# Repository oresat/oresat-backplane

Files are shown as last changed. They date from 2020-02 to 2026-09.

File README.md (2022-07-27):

# OreSat Backplane

## Background

The [OreSat](http://oresat.org) CubeSat bus uses a card cage / backplane system based on a 1 Mbps Controller Area Network (CAN) bus and a 2 cell Lithium ion battery power bus (6.0 - 8.4 V). There are ~ 8 cards per CubeSat "U", and the board is meant to be general purpose enough to allow for some card swapping. The RF lines, however, are microstrips on the backplane PCB so the backplane must be rev'd for changes in the RF cards. There are three sets of connectors:

1. 40 pin "Main" connector, which has !shutdown, CAN1, power, CAN2, OreSat power Domain (OPD) lines, and then 5 shared spare pins for custom card interconnects.
2. SMPM RF conncectors, which allows up to 3 RF connector per card and allows for 50 ohm microstrips to be run up and down the the board.
3. 20 pin "Auxiliary" connectors, used on the all but the "end" cards (top and bottom cards), which are for future inter-card communication. Good for Ethernet, for example.

The backplane now comes in two flavors: a 1U backplane, and a 2U backplane.

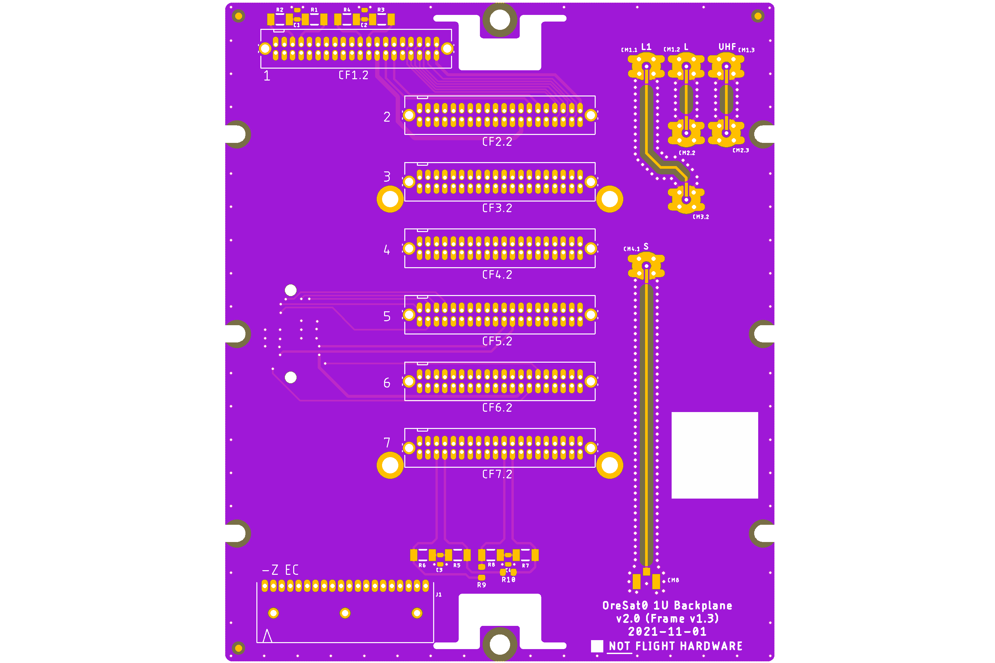
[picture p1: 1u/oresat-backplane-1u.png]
OreSat 1U Backplane Picture

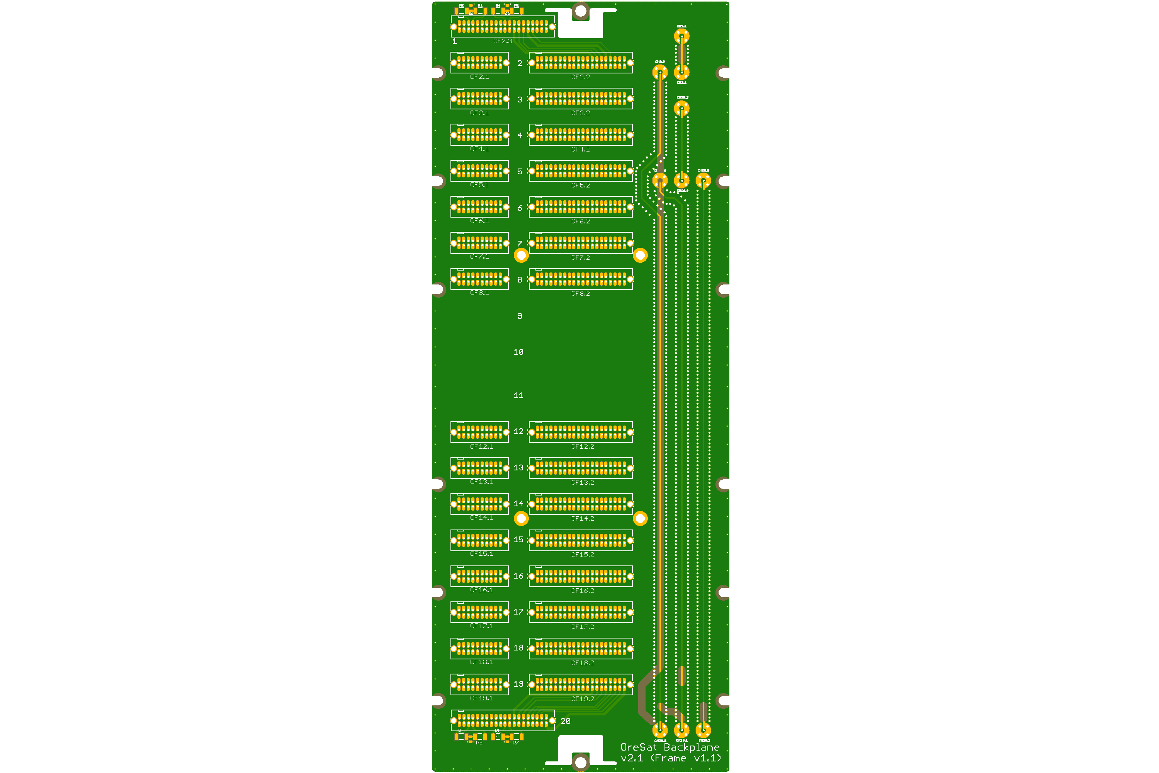
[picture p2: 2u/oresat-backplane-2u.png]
OreSat 2U Backplane Picture


## Mechanical Specifications

All mechanical specifications for this board are from the SolidWorks model which is in the 'oresat-structure' repo, specifically see the 'Backplane' folder. Some notes on the mechanical design:

- Ring of bare copper on the back is for thermal contact. Assumes annodized Aluminum, so no electrical contact on this ring.
- Backplane is grounded to the Aluminum frame on the internal four fasteners; this requires preparing the Aluminum for an electrical connection.
- Square cutouts on the top and bottom are for the solar connectors to reach the end cards. Note that on the 1U backplane, the bottom cutout is not used.
- Weird cutouts above and below square solar connector cutouts are for shoulder bolts (3 mm Shoulder Diameter, 2 mm Shoulder Length, M2 x 0.4 mm Thread, McMaster Carr #[90263A111](https://www.mcmaster.com/90263a111)) that precisely locates the PCB while allowing some flexing due to differences in thermal expansion between the Aluminum frame and the PCB.
- All other fasteners are M2 x 0.4 x 4 mm.

## Electrical Specifications

The board is designed for a [4 layer stackup](https://docs.oshpark.com/services/four-layer/) from [OSH Park](https://oshpark.com/) which has better RF performance than regular 2 layer board runs.

The connectors that we use on this puppy are the:

- **1.27 mm through-hole vertical socket connectors:**
    - 40 pin main connector
       - Samtec SFM-120-01-S-D-LC
       - 3D CAD: https://www.samtec.com/partnumber/sfm-120-01-s-d-lc
       - Drawing: http://suddendocs.samtec.com/prints/sfm-1xx-xx-xxx-d-xxx-mkt.pdf
       - Brochure: http://suddendocs.samtec.com/catalog_english/sfm.pdf
       - SFM footprint: http://suddendocs.samtec.com/prints/sfm-thd.pdf
    - 20 pin auxiliary connector
       - Samtec SFM-110-01-S-D-LC
       - 3D CAD: https://www.samtec.com/partnumber/sfm-110-01-s-d-lc
       - Drawing: http://suddendocs.samtec.com/prints/sfm-1xx-xx-xxx-d-xxx-mkt.pdf
       - Brochure: http://suddendocs.samtec.com/catalog_english/sfm.pdf
       - SFM footprint: http://suddendocs.samtec.com/prints/sfm-thd.pdf

- **RF (70 cm, L band, S band)**
   - Molex 073300-011X
   - SMPM Connector Plug, Male Pin 50 Ohm Surface Mount, Through Hole Solder, $13.84/ea @ 10
   - Molex (w/CAD): https://www.molex.com/molex/products/datasheet.jsp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
   - We've done a detailed characteraziation of OSH Park's 4 layer process, and found that 0.38 mm is the correct width for a 50 ohm microstrip.

- **CAN termination**
   - We'll use split termination, using two 60 ohm resistors with a center tapped capacitor for reduced EMI.
   - Resistors
      - 60.4 +/- 1% ohms. Might consider higher if the number of notes (~ 20) adds too much parallel resistance)
      - Usually there's only 2V (differential) across the 120 ohm termination resistors = 16 mA = 33 mW of power dissipation.
      - In the event of a bus short, there's 8.4 V across 120 ohms is 70 mA = 590 mW of power dissipation. That's ~ 300 mW across each of the 60 ohm resistors. Yikes.
      - ISO 11898-2 also requires 220 mW for the termination resistors, for whatever that's worth.
      - There exist 0.5 W 1206 resistors (?!) so although that's for an air rating, we'll still choose it, since larger than 1206 resistors are a tight fit
   - Capacitor
      - ISO 11898-2 doesn't seem to say anything about the capacitance, and the internets tend to say weird things. Unclear on this value.
      - TI's [Controller Area Network Physical Layer Requirements](http://www.ti.com/lit/an/slla270/slla270.pdf) suggests 4.7 nF to make the f_3dB = 1.1 MHz.
      - Seems awfully close to our 1 Mbps bus, so let's bump that down to 1 nF which is f_3db = 5.3 MHz.

- **Debug connector**
   - Harwin M55-6001642R (same family as the solar and end cap connectors)
   - Located on the back side of the backplane, it's a 16 pin 1.27 mm connector that gives external access to CAN busses, VBUS, and the UART lines. It sits in the 1U solar module "cutout".
   - For the external connector board, see the `backplane-debug` folder in the `oresat-flatsat` repo.

## Versions

- 1U
   - v1.0 - First fabbed 1U, but never assembled. For old frames (v1.1 frames), no -Z end cap connector, no debug connector.
   - v1.1 - Added -Z end cap connector. Fabbed roughly 2020-09-01, two assembled.
   - v1.2 - Added 1.27 mm debug connector, which tended to short. Fabbed 2020-12-08. Originally delivered on OreSat0.0 but never flown.
   - v2.0 -new backplane "v2" signal pinout (less power, more signals, UART lines, CAN bus bridging) and new non-shorting debug connector. Made new debug port board and breakout. Also corrected RF ports, including L1 band microstrip and S band strip to -Z end cap. Fabbed 2021-11-01 and installed on OreSat0.1 handed off to Spaceflight, ready for launch!
- 2U
   - v1.0 - First backplane. 2 layer board, RF connector array, aux and main connectors. Fabbed 2018/10/02.
   - v1.1 - End Cards now use 40 pin connector, solar connectors now actually fit. Fabbed 2019/02/25.
   - V2.0 - Switched to 4 layer board, removed RF connector array, used actual microstrips tuned to the 4 layer OSH Park process. Fabbed 2019/07/01.
   - v2.1 - Updated to latest backplane DXF, reducing all sides by 0.15 mm. Fixed solar connector cutout areas that were lopsided. Added CAN termination resistors. Moved RF connectors to latest (2020/02/15) locations. NOT YET FABBED.
   - vHASP - Made for the NASA HASP mission, fabbed, but never used.
   - V2.2 - Updated to FrameV2 and Oresat0.5 card locations

## LICENSE

Copyright the Portland State Aerospace Society, 2022.

This source describes Open Hardware that is licensed under CERN-OHL-S v2, or any later version.

You may redistribute and modify this source and make products using it under the terms of the CERN-OHL-S v2 (https://ohwr.org/cern_ohl_s_v2.txt).

This source is distributed WITHOUT ANY EXPRESS OR IMPLIED WARRANTY, INCLUDING OF MERCHANTABILITY, SATISFACTORY QUALITY AND FITNESS FOR A PARTICULAR PURPOSE. Please see the CERN-OHL-S v2 for applicable conditions.

Source location: https://github.com/oresat/

As per CERN-OHL-S v2 section 4, should You produce hardware based on this source, You must where practicable maintain the Source Location visible on the external case of the Gizmo or other products you make using this source.

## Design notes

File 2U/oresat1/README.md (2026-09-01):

---
title: "**OreSat1 2U Backplane Fabrication and Assembly Information**"
subtitle: |
  **Fabrication and Assembly Information**\
  For build TIME-STAMP
fontsize: 10pt
geometry:
  - margin=0.5in
toc: true
toc-depth: 2
colorlinks: true
urlcolor: blue
---

\newpage

# About this Board

## Board Description

The OreSat1 2U Backplane is the backplane for a 2U CubeSat based on the open source [OreSat CubeSat system](https://www.oresat.org/). The backplane has:

- 40 pin main connnectors for Oresat-based cards
- Bus voltage (2S Lithium Ion batteries with a Vnom of 7.2V)
- Two CAN busses for inter-card communication
- RF lines using SMPM RF connectors and microstrips
- A debug connector to carry critical lines to the outside of the CubeSat
- Two cutouts for solar module connections

## Documentation Links

- OreSat Backplane hardware Git repository: <https://github.com/oresat/oresat-backplane>
- **TODO:** Backplane Design Notes + Design Review Notes

## Documentation Files

| Filename | Notes |
| --- | --- |
| README.pdf | This README file |
| PROJECT-NAME-outline.dxf | Board outline (with holes) in DXF format |
| PROJECT-NAME-pcba.step | 3D model of PCBA (with components) |
| PROJECT-NAME-render-bot.jpg | Render of the top of the 3D model |
| PROJECT-NAME-render-bot.jpg | Render of the bottom of the 3D model |
| PROJECT-NAME-schematic.pdf | PDF of board schematics |

## Contact Information

- Website: <https://www.oresat.org/>
- Email: <oresat@pdx.edu>
- Instagram: @pdxaerospace

## Board Renders

Render of the top of the 3D model
Render of the bottom of the 3D model

\newpage

# Printed Circuit Board (PCB) Fabrication Information

## Board Info

- 4 layer board
- Bounding box is 82.5 x 213.5 mm
- Board thickness is 1.59 mm (0.063 inch)
- **Important:** See Materials and Stack Up sections below

## Board Requirements

- Design Rules
    - Minimum Trace / Space design rules
       - Outer layers: 0.127 mm (5.0 mil) / 0.127 mm (5.0 mil)
       - Inner layers: 0.127 mm (5.0 mil) / 0.127 mm (5.0 mil)
    - Outer dimension router tolerance: +/- 0.254 mm (10.0 mil)
    - Hole placement tolerance: +/- 0.075 mm (3.0 mil)
    - Inner tab routed slot tolerance: +/- 0.254 mm (10.0 mil)
- Drills
   - Drill Positional Tolerance: 0.051 mm (2.0 mil)
   - Drill Size tolerance: +/- 0.064 mm (2.5 mil)
- Plated/Un-plated holes
  - PTH minimum diameter: 0.254 mm (10 mil)
  - PTH minimum annulus: 0.102 mm (4 mil) radius
  - There are 4 un-plated (NPT) holes
- Outline/Routing
  - Requires a 1.0 mm or smaller diameter routing bit
- Slots/Cutouts
  - There are two slot/cutouts.
  - Requires a 1.0 mm or smaller diameter routing bit
- There are 3 fiducials on the top layer and 3 fiducials on the bottom layer.
- Panel tabs ("mouse bites")
   - Card edges must be smooth; no mouse bites or other intrusions into the card outline.
   - If external mouse bites are required, minimize and customer will remove by hand before assembly.
- If not otherwise specified, PCB fabrication shall conform to IPC-6012, Class 2 or better. 
- If not otherwise specified, PCB acceptability criteria shall be via IPC-A-600, Class 2 or better.

## Materials

- Controlled impedance
   - The stackup is critical for the performance of high speed signals on this board.
   - As long as the stackup is controlled, the board is not considered controlled impedance.
- Isola FR408HR or material with equivalent Dk.
- Board Surface treatment should be ENIG, althogh immersion Silver is acceptable.
- White silkscreen on top and bottom surface
- Taiyo PSR-4000 or equivalent soldermask on top and bottom, no requirements for color.

## Stack Up

| Layer | Thickness | Notes |
|---|---|---|
| Top Copper | 0.043 mm /  1.7 mil |  Layer 1 foil, 1 oz Cu after plating |
| prepreg | 0.200 mm /  7.9 mil |  Prepreg - Isola FR408HR 2113 |
| Layer 2 | 0.018 mm /  0.7 mil |  Layer 2 foil, 0.5 oz Cu |
| Core | 0.991 mm / 39 mil |  Core Isola FR408HR |
| Layer 3 | 0.018 mm /  0.7 mil |  Layer 3 foil, 0.5 oz Cu |
| prepreg | 0.200 mm /  7.9 mil |  Prepreg - Isola FR408HR 2113 |
| Bottom Copper | 0.043 mm /  1.7 mil |  Layer 4 foil, 1 oz copper after plating |
| **Total Stackup** | **1.588 mm / 62.5 mil** | |

## Array / Panel Information

- Coordinate with Contract Manufacturer (CM) for optimal size of this panel.
- If no feedback from CM, then produce single boards (no panel).

## Fabrication Files

### IPC-2581 File

| Filename | Notes |
| --- | --- |
| PROJECT-NAME-ipc2581.xml | IPC-2581 board information file |

### Legacy PCB Files

| Filename | Notes |
| ---| --- |
| PROJECT-NAME-Edge_Cuts.gbr | RS274X file for the dimension (outline) layer |
| PROJECT-NAME-F_Silkscreen.gbr | RS274X file for the top silkscreen |
| PROJECT-NAME-F_Mask.gbr | RS274X file for the top soldermask |
| PROJECT-NAME-F_Cu.gbr | RS274X file for the top copper layer |
| PROJECT-NAME-In1_Cu.gbr | RS274X file for the layer 2 copper |
| PROJECT-NAME-In2_Cu.gbr | RS274X file for the layer 3 copper |
| PROJECT-NAME-B_Cu.gbr | RS274X file for the bottom copper layer |
| PROJECT-NAME-B_Mask.gbr | RS274X file for the bottom soldermask |
| PROJECT-NAME-B_Silkscreen.gbr | RS274X file for the bottom silkscreen |
| PROJECT-NAME-NPTH.drl | Excellon file for non-plated through holes |
| PROJECT-NAME-PTH.drl | Excellon file for plated through holes | 

\newpage

# Printed Circuit Board Assembly (PCBA) Information

## Assembly Info

- There are components on the top and bottom sides of the board.
- This PCBA is a mix of surface mount (SMT) and through hole (THT) components.

## Assembly Requirements

- Assembly shall conform to IPC J-STD-001 Class 2 or better.
- Inspection of assemblies shall be per IPC-A-610, Class 2 or better.
- Bake components that are not moisture sealed to appropriate levels as required.
- Solder paste MUST be leaded.
- Aqueous flux and wash strongly preferred.
   - Clean to NASA Standard "Visibly Clean (VC)": No particles or residues are visible to the naked eye.
- No conformal coating.
- Ship in antistatic protective bag.

## Component Specific Assembly Information

- SMPM connectors (CM*.*) should be hand-added before reflow.

## Assembly Files

### IPC-2581 File

| Filename | Notes |
| --- | --- |
| PROJECT-NAME-ipc2581.xml | IPC-2581 board information file |

### Bill of Materials (BOM)

| Filename | Description |
| --- | --- |
| PROJECT-NAME-bom.csv | BOM in Comma Separated Variable format |

### Solder Paste Stencils

| Filename | Notes |
| --- | --- |
| PROJECT-NAME-B_Paste.gbr | RS274X file for top/front solder paste stencil |
| PROJECT-NAME-F_Paste.gbr | RS274X file for bottom/back solder paste stencil |

### Mounting/Placement Location

| Filename | Description |
| --- | --- |
| PROJECT-NAME-3u.pos | Pick and place locations for components |

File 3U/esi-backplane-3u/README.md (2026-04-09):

---
title: "**ESI/OreSat 3U Backplane Fabrication and Assembly Information**"
subtitle: |
  **Fabrication and Assembly Information**\
  For build TIME-STAMP
fontsize: 10pt
geometry:
  - margin=0.5in
toc: true
toc-depth: 2
colorlinks: true
urlcolor: blue
---

\newpage

# About this Board

## Board Description

The ESI/OreSat 3U Backplane is the backplane for a 3U backplane based on the open source [OreSat CubeSat system](https://www.oresat.org/). The backplane has:

- 40 pin main connnectors for Oresat-based cards
- Bus voltage (2S Lithium Ion batteries with a Vnom of 7.2V)
- Two CAN busses for inter-card communication
- RF lines using SMPM RF connectors and microstrips
- A debug connector to carry critical lines to the outside of the CubeSat
- Four cutouts for solar module connections

## Documentation Links

- OreSat Backplane hardware Git repository: <https://github.com/oresat/oresat-backplane>
- **TODO:** Backplane Design Notes + Design Review Notes

## Documentation Files

| Filename | Notes |
| --- | --- |
| README.pdf | This README file |
| PROJECT-NAME-outline.dxf | Board outline (with holes) in DXF format |
| PROJECT-NAME-pcba.step | 3D model of PCBA (with components) |
| PROJECT-NAME-render-bot.jpg | Render of the top of the 3D model |
| PROJECT-NAME-render-bot.jpg | Render of the bottom of the 3D model |
| PROJECT-NAME-schematic.pdf | PDF of board schematics |

## Contact Information

- Website: <https://www.oresat.org/>
- Email: <oresat@pdx.edu>
- Instagram: @pdxaerospace

## Board Renders

Render of the top of the 3D model
Render of the bottom of the 3D model

\newpage

# Printed Circuit Board (PCB) Fabrication Information

## Board Info

- 4 layer board
- Bounding box is 82.5 x 327.0 mm
- Board thickness is 1.59 mm (0.063 inch)
- **Important:** See Materials and Stack Up sections below

## Board Requirements

- Design Rules
    - Minimum Trace / Space design rules
       - Outer layers: 0.127 mm (5.0 mil) / 0.127 mm (5.0 mil)
       - Inner layers: 0.127 mm (5.0 mil) / 0.127 mm (5.0 mil)
    - Outer dimension router tolerance: +/- 0.254 mm (10.0 mil)
    - Hole placement tolerance: +/- 0.075 mm (3.0 mil)
    - Inner tab routed slot tolerance: +/- 0.254 mm (10.0 mil)
- Drills
   - Drill Positional Tolerance: 0.051 mm (2.0 mil)
   - Drill Size tolerance: +/- 0.064 mm (2.5 mil)
- Plated/Un-plated holes
  - There are 4 un-plated (NPT) holes
  - PTH minimum diameter: 0.254 mm (10 mil)
  - PTH minimum annulus: 0.102 mm (4 mil) radius
- Outline/Routing
  - Requires a 1.0 mm or smaller diameter routing bit
- Slots
  - There are no slots (although two cutouts have slot-like features)
- Cutouts
  - There are five cutouts.
- There are 3 fiducials on the top layer and 3 fiducials on the bottom layer.
- Panel tabs ("mouse bites")
   - Card edges must be smooth; no mouse bites or other intrusions into the card outline.
   - If external mouse bites are required, minimize and customer will remove by hand before assembly.
- If not otherwise specified, build to IPC 6012 Class 2 or better.

## Materials

- Controlled impedance
   - The stackup is critical for the performance of high speed signals on this board.
   - As long as the stackup is controlled, the board is not considered controlled impedance.
- Isola FR408HR or material with equivalent Dk.
- Board Surface treatment should be ENIG, althogh immersion Silver is acceptable.
- White silkscreen on top and bottom surface
- Taiyo PSR-4000 or equivalent soldermask on top and bottom, no requirements for color.

## Stack Up

| Layer | Thickness | Notes |
|---|---|---|
| Top Copper | 0.043 mm /  1.7 mil |  Layer 1 foil, 1 oz Cu after plating |
| prepreg | 0.200 mm /  7.9 mil |  Prepreg - Isola FR408HR 2113 |
| Layer 2 | 0.018 mm /  0.7 mil |  Layer 2 foil, 0.5 oz Cu |
| Core | 0.991 mm / 39 mil |  Core Isola FR408HR |
| Layer 3 | 0.018 mm /  0.7 mil |  Layer 3 foil, 0.5 oz Cu |
| prepreg | 0.200 mm /  7.9 mil |  Prepreg - Isola FR408HR 2113 |
| Bottom Copper | 0.043 mm /  1.7 mil |  Layer 4 foil, 1 oz copper after plating |
| **Total Stackup** | **1.588 mm / 62.5 mil** | |

## Array / Panel Information

- Coordinate with Contract Manufacturer (CM) for optimal size of this panel.
- If no feedback from CM, then produce single boards (no panel).

## Fabrication Files

### IPC-2581 File

| Filename | Notes |
| --- | --- |
| PROJECT-NAME-ipc2581.xml | IPC-2581 board information file |

### Legacy PCB Files

| Filename | Notes |
| ---| --- |
| PROJECT-NAME-Edge_Cuts.gbr | RS274X file for the dimension (outline) layer |
| PROJECT-NAME-F_Silkscreen.gbr | RS274X file for the top silkscreen |
| PROJECT-NAME-F_Mask.gbr | RS274X file for the top soldermask |
| PROJECT-NAME-F_Cu.gbr | RS274X file for the top copper layer |
| PROJECT-NAME-In1_Cu.gbr | RS274X file for the layer 2 copper |
| PROJECT-NAME-In2_Cu.gbr | RS274X file for the layer 3 copper |
| PROJECT-NAME-B_Cu.gbr | RS274X file for the bottom copper layer |
| PROJECT-NAME-B_Mask.gbr | RS274X file for the bottom soldermask |
| PROJECT-NAME-B_Silkscreen.gbr | RS274X file for the bottom silkscreen |
| PROJECT-NAME-NPTH.drl | Excellon file for non-plated through holes |
| PROJECT-NAME-PTH.drl | Excellon file for plated through holes | 

\newpage

# Printed Circuit Board Assembly (PCBA) Information

## Assembly Info

- There are components on the top and bottom sides of the board.
- This PCBA is a mix of surface mount (SMT) and through hole (THT) components.

## Assembly Requirements

- Assemble to IPC Class 2 or better
- Bake components that are not moisture sealed to appropriate levels as required.
- Solder paste MUST be leaded.
- Aqueous flux and wash strongly preferred.
   - Clean to NASA Standard "Visibly Clean (VC)": No particles or residues are visible to the naked eye.
- No conformal coating.
- Ship in antistatic protective bag.

## Component Specific Assembly Information

- SMPM connectors (CM*.*) should be hand-added before reflow.
- Not all connectors are placed, see BOM.

## Assembly Files

### IPC-2581 File

| Filename | Notes |
| --- | --- |
| PROJECT-NAME-ipc2581.xml | IPC-2581 board information file |

### Bill of Materials (BOM)

| Filename | Description |
| --- | --- |
| PROJECT-NAME-bom.csv | BOM in Comma Separated Variable format |

### Solder Paste Stencils

| Filename | Notes |
| --- | --- |
| PROJECT-NAME-B_Paste.gbr | RS274X file for top/front solder paste stencil |
| PROJECT-NAME-F_Paste.gbr | RS274X file for bottom/back solder paste stencil |

### Mounting/Placement Location

| Filename | Description |
| --- | --- |
| PROJECT-NAME-3u.pos | Pick and place locations for components |

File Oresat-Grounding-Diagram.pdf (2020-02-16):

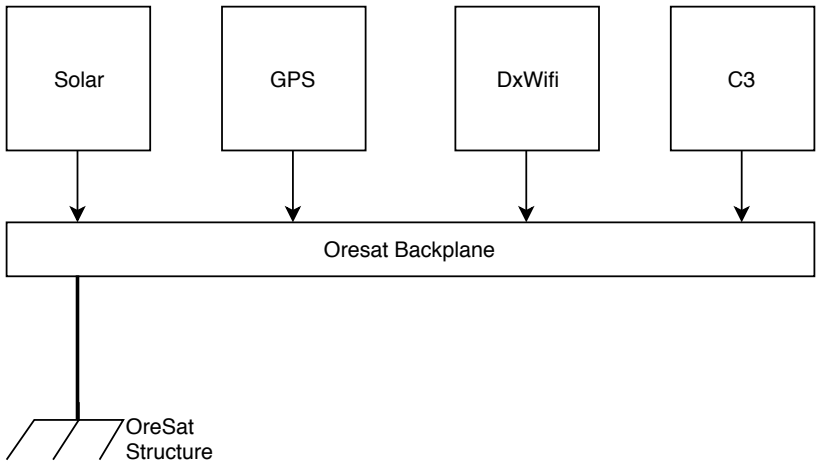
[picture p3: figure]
Solar; GPS; DxWifi; Oresat Backplane; OreSat Structure

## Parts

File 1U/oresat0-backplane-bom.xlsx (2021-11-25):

Bill Of Materials for OreSat0 1U Backplane
PCB version: 2.0 |  |  | P/NP = | Place/No Place
BOM revision: 1 |  |  | Generic = | Any part with the same characteristics may be substituted
Cnt | Part References | P/NP | Mfg | Mfg PN | Description | Distributor | Dist. PN | Cost | Ext. | Stock* | Generic | Notes
2 | C1, C2 | P | Murata | GCM1885C2A102JA16D | 1000 pF ±5% 100V Ceramic Capacitor C0G, NP0 0603 (1608 Metric) | Digi-Key | 399-C0603C102F1GACAUTOCT-ND | 0.143 | 0.286 | 0 | Y | High voltage, automotive grade
0 | C3, C4 | NP | Murata | GCM1885C2A102JA16D | 1000 pF ±5% 100V Ceramic Capacitor C0G, NP0 0603 (1608 Metric) | Digi-Key | 399-C0603C102F1GACAUTOCT-ND | 0 | 0 | 0 | Y
7 | C5, C6, C7, C8, C9, C10, C11 | P | Murata | GCM31CC71E106KA03K | 10 µF ±10% 25V Ceramic Capacitor X7S 1206 (3216 Metric) | Digi-Key | 490-14533-1-ND | 0.575 | 4.025 | 0 | Y | Vbus hold-up capacitors
7 | CM1.1, CM1.2, CM1.3, CM2.2, CM2.3, CM3.2, CM4.1 | P | Molex | 073300-0110 | "RF": SMPM Connector Plug, Male Pin 50 Ohm SMT + TH | Digi-Key | WM10770-ND | 14.02 | 98.14 | 8 | N | RF connectors
7 | B1, B2, B3, B4, B5, B6, B7 | P | Molex | 073300-0220 | Adapter Coaxial Connector SMPM Jack, Female Socket To SMPM Jack, Female Socket 50Ohm | Digi-Key | WM17066-ND | 14.72 | 103.04 | 16 | N | RF barrel adapters (required)
7 | CF1.2, CF2.2, CF3.2, CF4.2, CF5.2, CF6.2, CF7.2, CF8.2 | P | Samtec | SFM-120-01-S-D-LC | "Main": TigerEye SFM series 40 pin 1.27 mm TH Vertical connector | Digi-Key | SAM11706-ND | 11.998 | 83.986 | 11 | N | Main card connectors
1 | J1 | P | TE | 5-104196-5 | 20 Position Receptacle Connector 0.050" (1.27mm) Through Hole, Right Angle Gold | Digi-Key | A115240-ND | 6.43 | 6.43 | 8 | N | -Z End Cap connector
1 | J2 | P | Harwin | M55-6001642R | 16 Position Receptacle Connector 0.050" (1.27mm) Surface Mount Gold | Digi-Key | 952-3836-1-ND | 1.96 | 1.96 | 6 | N | Debug connector
1 | PCB1 | P | Osh Park | N/A | OreSat0 1U Backplane v2.0 | N/A | N/A | 126.6 | 126.6 | 3 | N | 4 layer Osh Park PCB
4 | R1, R2, R3, R4 | P | Rohm | ESR18EZPF60R4 | 60.4 Ohms ±1% 0.5W, 1/2W Resistor 1206 AEC-Q200 | Digi-Key | RHM60.4AFCT-ND | 0.126 | 0.504 | 0 | Y | High wattage just in case
0 | R5, R6, R7, R8 | NP | Rohm | ESR18EZPF60R4 | 60.4 Ohms ±1% 0.5W, 1/2W Resistor 1206 AEC-Q200 | Digi-Key | RHM60.4AFCT-ND | 0.126 | 0 | 0 | Y | High wattage just in case
2 | R9, R10 | P | Stackpole | RMCF0603ZT0R00 | 0 Ohms Jumper 0.1W, 1/10W Chip Resistor 0603 (1608 Metric) Automotive AEC-Q200 Thick Film | Digi-Key | RMCF0603ZT0R00CT-ND | 0.1 | 0.2 | 0 | Y | CAN jumpers (bridges CAN1 to CAN2)
 |  |  |  |  |  |  |  | Total: | $425.17
BOM Version Information
Rev | Date | Notes
1.0r0 | -- | Initial BOM for 1U.
1.1r0 | 2020-12-08 | Added -Z end cap connector, and debug connector.
2.0r0 | 2021-10-17 | v2.0 backplane specifically for OreSat0
2.0r1 | 2021-11-25 | Fixed debug connector.
* Stock: | 2021-11-01 | Last updated before OreSat0.1 orders

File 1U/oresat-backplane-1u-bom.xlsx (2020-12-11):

Bill Of Materials for OreSat Backplane 1U
source file: oresat-backplane-1u.sch
PCB version: 1.1 |  |  | P/DNP = | Place/Do Not Place (DNP is for final production boards)
BOM revision: 0 |  |  | Generic = | Any generic part with the same characteristics are OK (e.g., bypass cap)
Cnt | Part References | P/DNP | Mfg | Mfg PN | Description | Distributor | Dist. PN | Generic | Notes
8 | CM1.1, CM1.2, CM1.3, CM2.1, CM2.2, CM2.3, CM3.2, CM4.1 | P | Molex | 073300-0110 | "RF": SMPM Connector Plug, Male Pin 50 Ohm SMT + TH | Digi-Key | WM10770-ND | N | RF connectors
7 | CF2.1, CF3.1, CF4.1, CF5.1, CF6.1, CF7.1, CF8.1 | DNP | Samtec | SFM-110-01-S-D-LC | "Aux": TigerEye SFM series 20 pin 1.27 mm TH Vertical connector | Digi-Key | SFM-110-01-S-D-LC-ND | N | Auxiliary (not placed!)
8 | CF1.2, CF2.2, CF3.2, CF4.2, CF5.2, CF6.2, CF7.2, CF8.2 | P | Samtec | SFM-120-01-S-D-LC | "Main": TigerEye SFM series 40 pin 1.27 mm TH Vertical connector | Digi-Key | SAM11706-ND | N | Main card connectors
8 | R1, R2, R3, R4, R5, R6, R7, R8 | P | Rohm | ESR18EZPF60R4 | 60.4 Ohms ±1% 0.5W, 1/2W Resistor 1206 AEC-Q200 | Digi-Key | RHM60.4AFCT-ND | N | High wattage just in case
4 | C1, C2, C3, C4 | P | Kemet | C0603C102F1GACAUTO | 1000pF ±1% 100V Ceramic Capacitor C0G, NP0 0603 | Digi-Key | 399-C0603C102F1GACAUTOCT-ND | N | High voltage, automotive grade
1 | J1 | P | TE | 5-104196-5 | 20 Position Receptacle Connector Through Hole, Right Angle | Digi-Key | A115240-ND | N | -Z End Cap connector
1 | J3 | P | Harwin | M50-3501042 | 20 Position Connector Header Through Hole 0.050" (1.27mm) | Digi-Key | 952-1386-ND | N | Debug connector
Revision versioing infro
Rev | Date | Notes
1.0r0 | -- | Initial BOM for 1U.
1.1r0 | 2020-12-08 | Added -Z end cap connector, and debug connector.

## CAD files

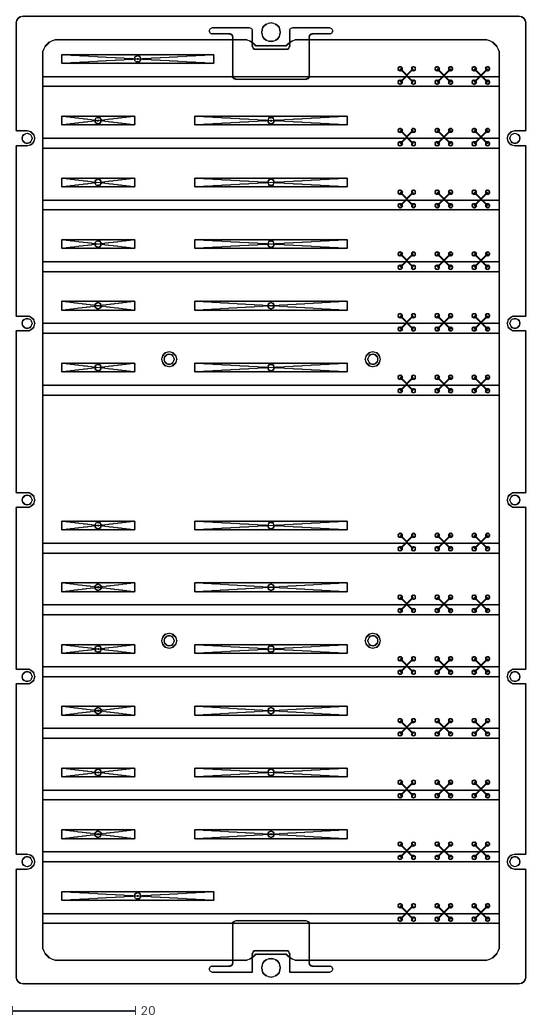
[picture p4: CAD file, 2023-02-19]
1.5U/1.5U_BackplanePCB.DXF
82.5 x 156.7

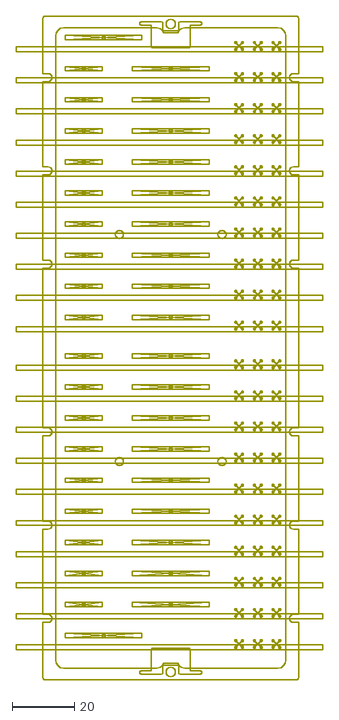
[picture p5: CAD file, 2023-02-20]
2U/2u-backplane.dxf
98.6 x 213.5

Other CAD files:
3U/esi-backplane-3u/esi-backplane-with-hole.dxf
3U/oresat-backplane-3u.dxf

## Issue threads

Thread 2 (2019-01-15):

Fix RF connectors based on HFSS simulation

andrewgreenberg, 2019-01-15:
RF connectors, at least n to n+1 connections, don't have great 2.4 GHz functionality. Wait for the HFSS simulation, and fix RF connector (SMPM) and microcoax footprints.

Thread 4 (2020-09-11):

Larger annulus and drill hole on RF connectors

davidalay, 2020-09-11:
The annulus on the rf connectors needs to be wider.  The drill diameter also needs to be slightly wider.

Closed 2021-11-03.

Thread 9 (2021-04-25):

Switch to a shrouded debug connector to prevent possible shorts

andrewgreenberg, 2021-04-25:
... like that destroyed BP #2.

Closed 2021-11-03.

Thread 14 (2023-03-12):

Pads on back of board for RF connector ground pins are too small

Benjamin-C, 2023-03-12:
The RF connectors need bigger ground pads for the ground pins on the back of the board so that we can solder them easier

Benjamin-C, 2023-03-28:
Annular ring size increased to 1.2mm diameter

Closed 2023-03-28.

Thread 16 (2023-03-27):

OreSat0.5 2U backplane: remove solder mask from under all M2 screws

andrewgreenberg, 2023-03-27:
Remove the front solder mask from below the 2x precision shoulder bolts and the 16 M2x0.4x4 fasteners.

Closed 2023-04-23.

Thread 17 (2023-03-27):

OreSat0.5 2U: 20 pin AUX connectors in the wrong slot. :(

andrewgreenberg, 2023-03-27:
20 pin aux connectors need to be in slot 17 (CFC Processor Card) and slot 18 (CFC sensor card), not in Slot 19, which is where the lens mount holders go.. You can leave the main connector in slot 19, no harm in that, but it does not need the AUX connector.

Closed 2023-03-28.

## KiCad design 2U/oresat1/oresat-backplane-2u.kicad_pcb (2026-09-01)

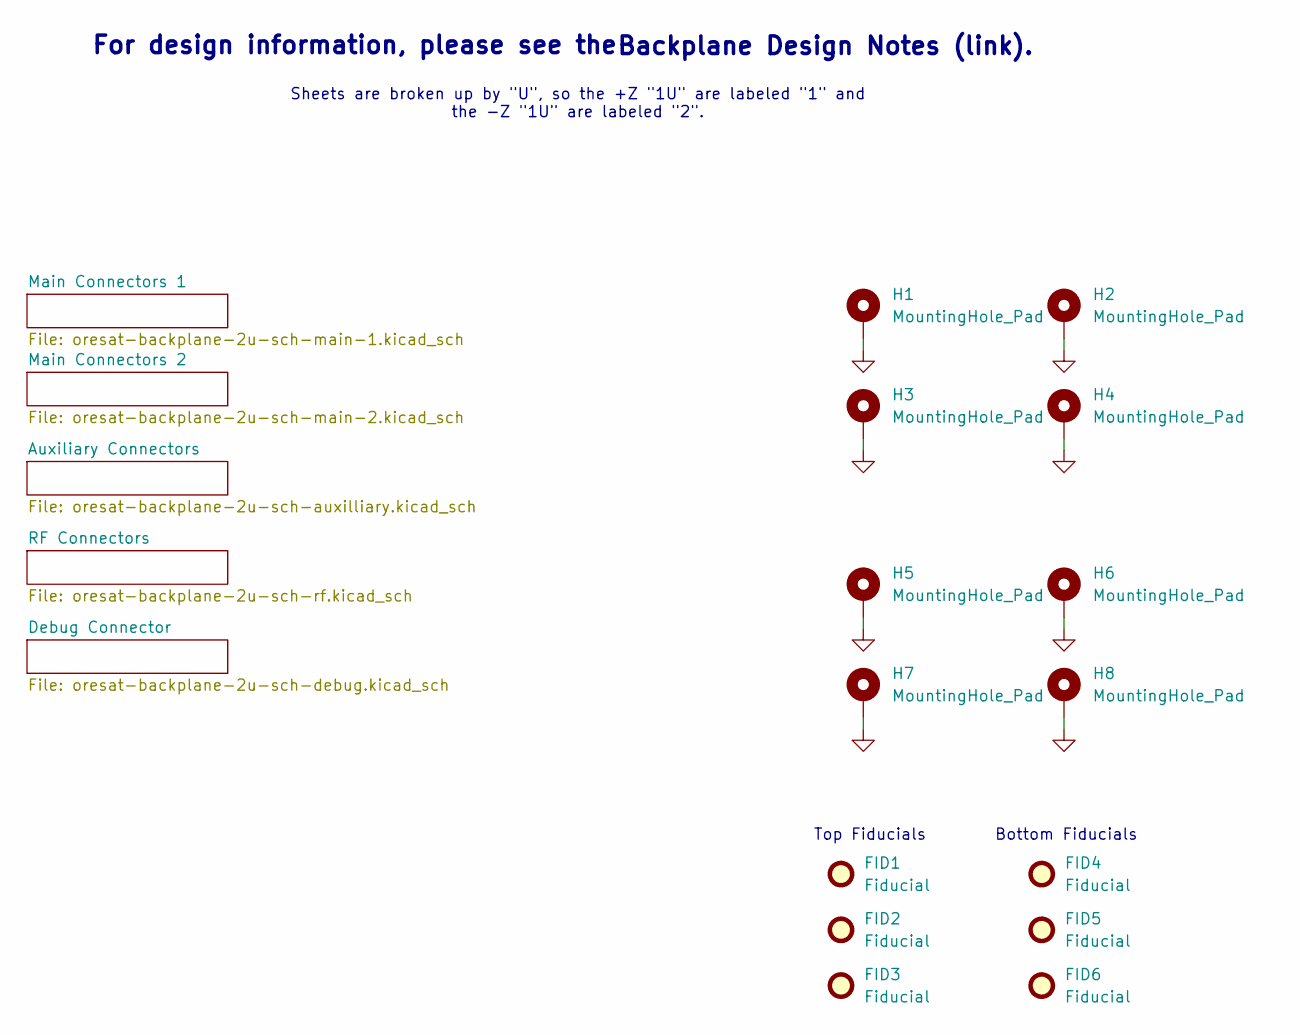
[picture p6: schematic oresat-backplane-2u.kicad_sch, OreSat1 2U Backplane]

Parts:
FID1, FID2, FID3, FID4, FID5, FID6: Fiducial; Fiducial_1mm_Mask2mm
H1, H2, H3, H4, H5, H6, H7, H8: MountingHole_Pad; MountingHole_2.2mm_M2_DIN965_Pad

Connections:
GND: H1.1 (1_1), H2.1 (1_1), H3.1 (1_1), H4.1 (1_1), H5.1 (1_1), H6.1 (1_1), H7.1 (1_1), H8.1 (1_1); also elsewhere on the board

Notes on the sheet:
For design information, please see the
Top Fiducials
Sheets are broken up by "U", so the +Z "1U" are labeled "1" and the -Z "1U" are labeled "2".
Backplane Design Notes (link).
Bottom Fiducials

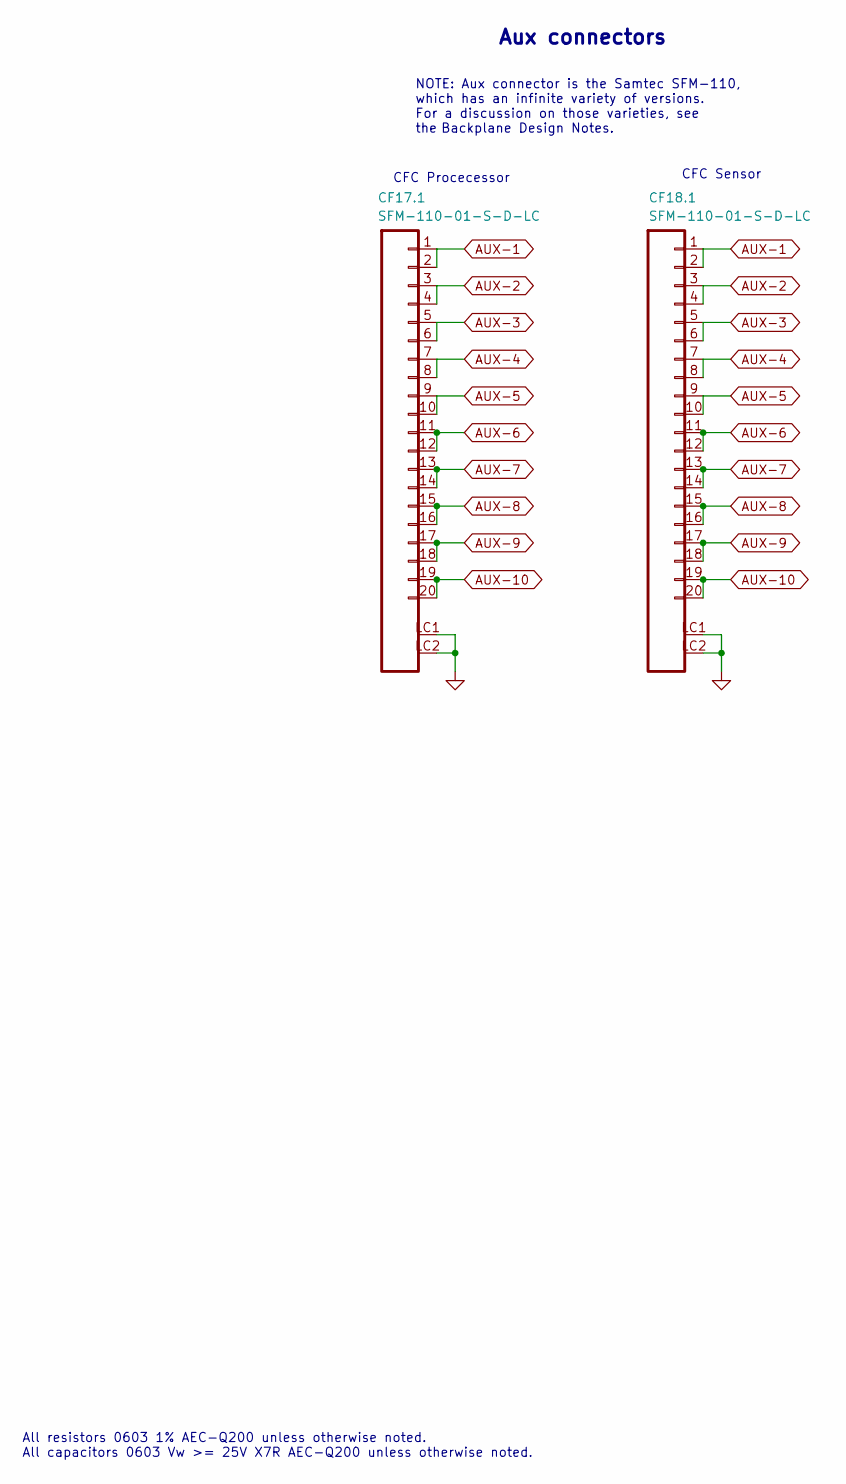
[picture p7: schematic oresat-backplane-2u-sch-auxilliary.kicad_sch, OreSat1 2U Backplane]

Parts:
CF17.1, CF18.1: SFM-110-01-S-D-LC; J-SAMTEC-CF-SFM-110-X1-XXX-D-LC; MPN SFM-110-01-S-D-LC

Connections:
AUX-1: CF17.1.1, CF17.1.2, CF18.1.1, CF18.1.2
AUX-2: CF17.1.3, CF17.1.4, CF18.1.3, CF18.1.4
AUX-3: CF17.1.5, CF17.1.6, CF18.1.5, CF18.1.6
AUX-4: CF17.1.7, CF17.1.8, CF18.1.7, CF18.1.8
AUX-5: CF17.1.9, CF17.1.10, CF18.1.9, CF18.1.10
AUX-6: CF17.1.11, CF17.1.12, CF18.1.11, CF18.1.12
AUX-7: CF17.1.13, CF17.1.14, CF18.1.13, CF18.1.14
AUX-8: CF17.1.15, CF17.1.16, CF18.1.15, CF18.1.16
AUX-9: CF17.1.17, CF17.1.18, CF18.1.17, CF18.1.18
AUX-10: CF17.1.19, CF17.1.20, CF18.1.19, CF18.1.20
GND: CF17.1.LC1, CF17.1.LC2, CF18.1.LC1, CF18.1.LC2; also elsewhere on the board

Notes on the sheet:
Backplane Design Notes.
CFC Procecessor
All resistors 0603 1% AEC-Q200 unless otherwise noted. All capacitors 0603 Vw >= 25V X7R AEC-Q200 unless otherwise noted.
CFC Sensor
NOTE: Aux connector is the Samtec SFM-110, which has an infinite variety of versions. For a discussion on those varieties, see the
Aux connectors

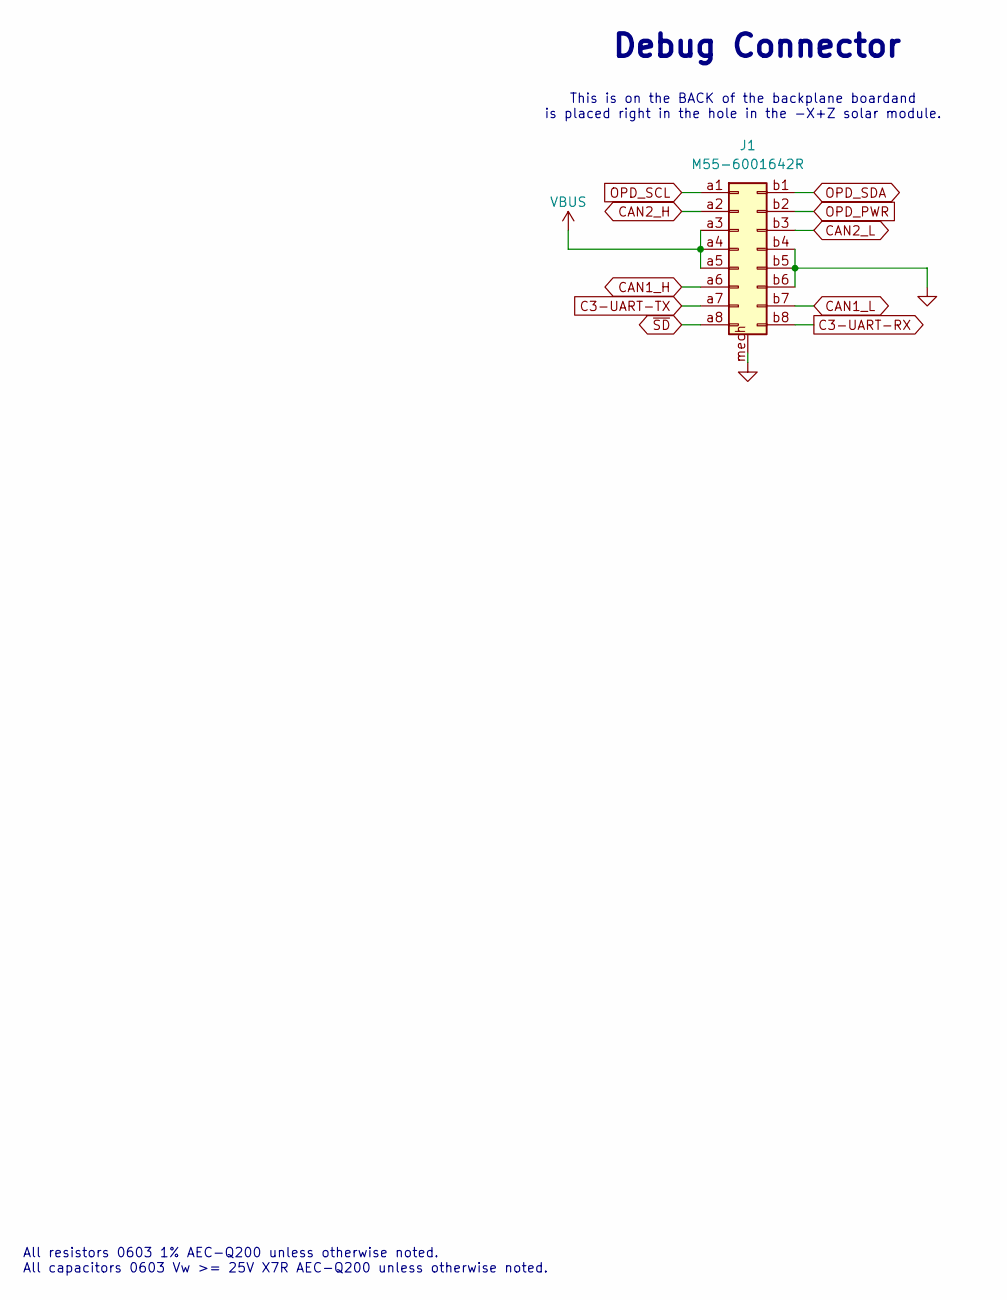
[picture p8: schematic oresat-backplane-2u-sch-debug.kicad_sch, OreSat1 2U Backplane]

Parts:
J1: M55-6001642R; m55-6001642; MPN M55-6001642R

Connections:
C3-UART-RX: J1.b8; also elsewhere on the board
C3-UART-TX: J1.a7; also elsewhere on the board
CAN1_H: J1.a6; also elsewhere on the board
CAN1_L: J1.b7; also elsewhere on the board
CAN2_H: J1.a2; also elsewhere on the board
CAN2_L: J1.b3; also elsewhere on the board
GND: J1.b4, J1.b5, J1.b6, J1.mech; also elsewhere on the board
OPD_PWR: J1.b2; also elsewhere on the board
OPD_SCL: J1.a1; also elsewhere on the board
OPD_SDA: J1.b1; also elsewhere on the board
VBUS: J1.a3, J1.a4, J1.a5; also elsewhere on the board
~SD: J1.a8; also elsewhere on the board

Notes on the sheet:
This is on the BACK of the backplane boardand is placed right in the hole in the -X+Z solar module.
Debug Connector
All resistors 0603 1% AEC-Q200 unless otherwise noted. All capacitors 0603 Vw >= 25V X7R AEC-Q200 unless otherwise noted.

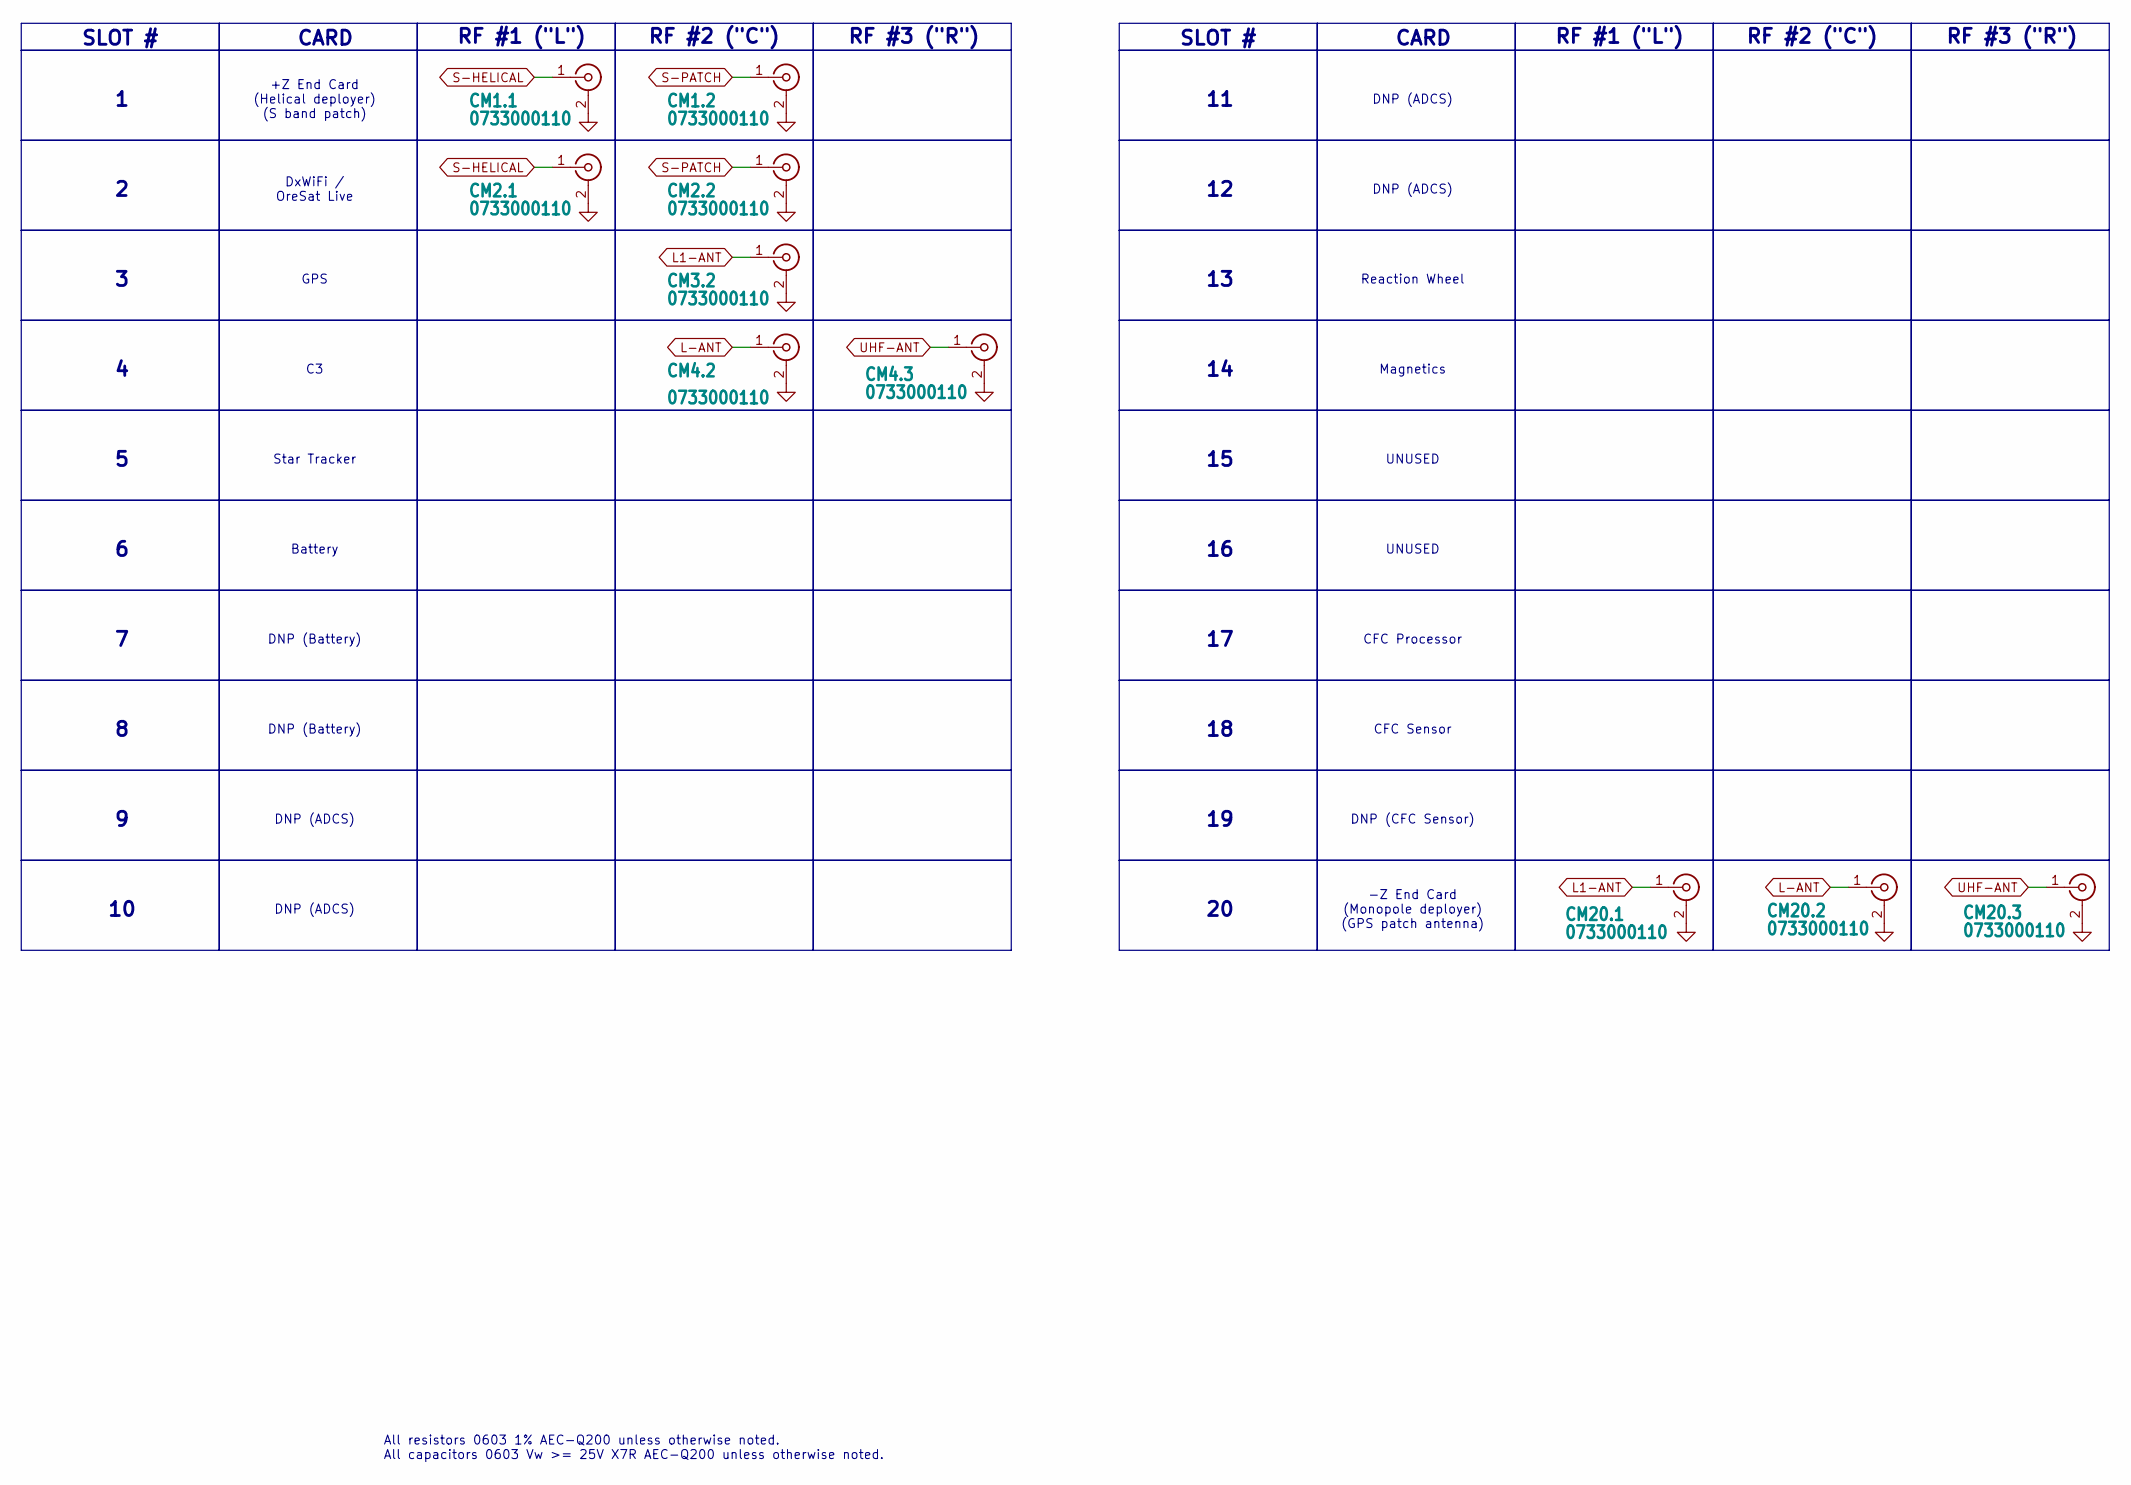
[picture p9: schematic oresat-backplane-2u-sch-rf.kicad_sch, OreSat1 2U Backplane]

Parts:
CM1.1, CM1.2, CM2.1, CM2.2, CM3.2, CM4.2, CM4.3, CM20.1, CM20.2, CM20.3: 0733000110; J-MOLEX-SMPM-73300-011X; MPN 0733000110

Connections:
GND: CM1.1.2 (Ext), CM1.2.2 (Ext), CM2.1.2 (Ext), CM2.2.2 (Ext), CM3.2.2 (Ext), CM4.2.2 (Ext), CM4.3.2 (Ext), CM20.1.2 (Ext), CM20.2.2 (Ext), CM20.3.2 (Ext); also elsewhere on the board
L1-ANT: CM3.2.1 (In), CM20.1.1 (In)
L-ANT: CM4.2.1 (In), CM20.2.1 (In)
S-HELICAL: CM1.1.1 (In), CM2.1.1 (In)
S-PATCH: CM1.2.1 (In), CM2.2.1 (In)
UHF-ANT: CM4.3.1 (In), CM20.3.1 (In)

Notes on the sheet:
CARD
SLOT #
+Z End Card (Helical deployer) (S band patch)
RF #2 ("C")
RF #3 ("R")
DxWiFi / OreSat Live
UNUSED
Star Tracker
Battery
DNP (CFC Sensor)
GPS
RF #1 ("L")
DNP (ADCS)
CFC Sensor
Magnetics
CFC Processor
-Z End Card (Monopole deployer) (GPS patch antenna)
DNP (Battery)
Reaction Wheel
All resistors 0603 1% AEC-Q200 unless otherwise noted. All capacitors 0603 Vw >= 25V X7R AEC-Q200 unless otherwise noted.

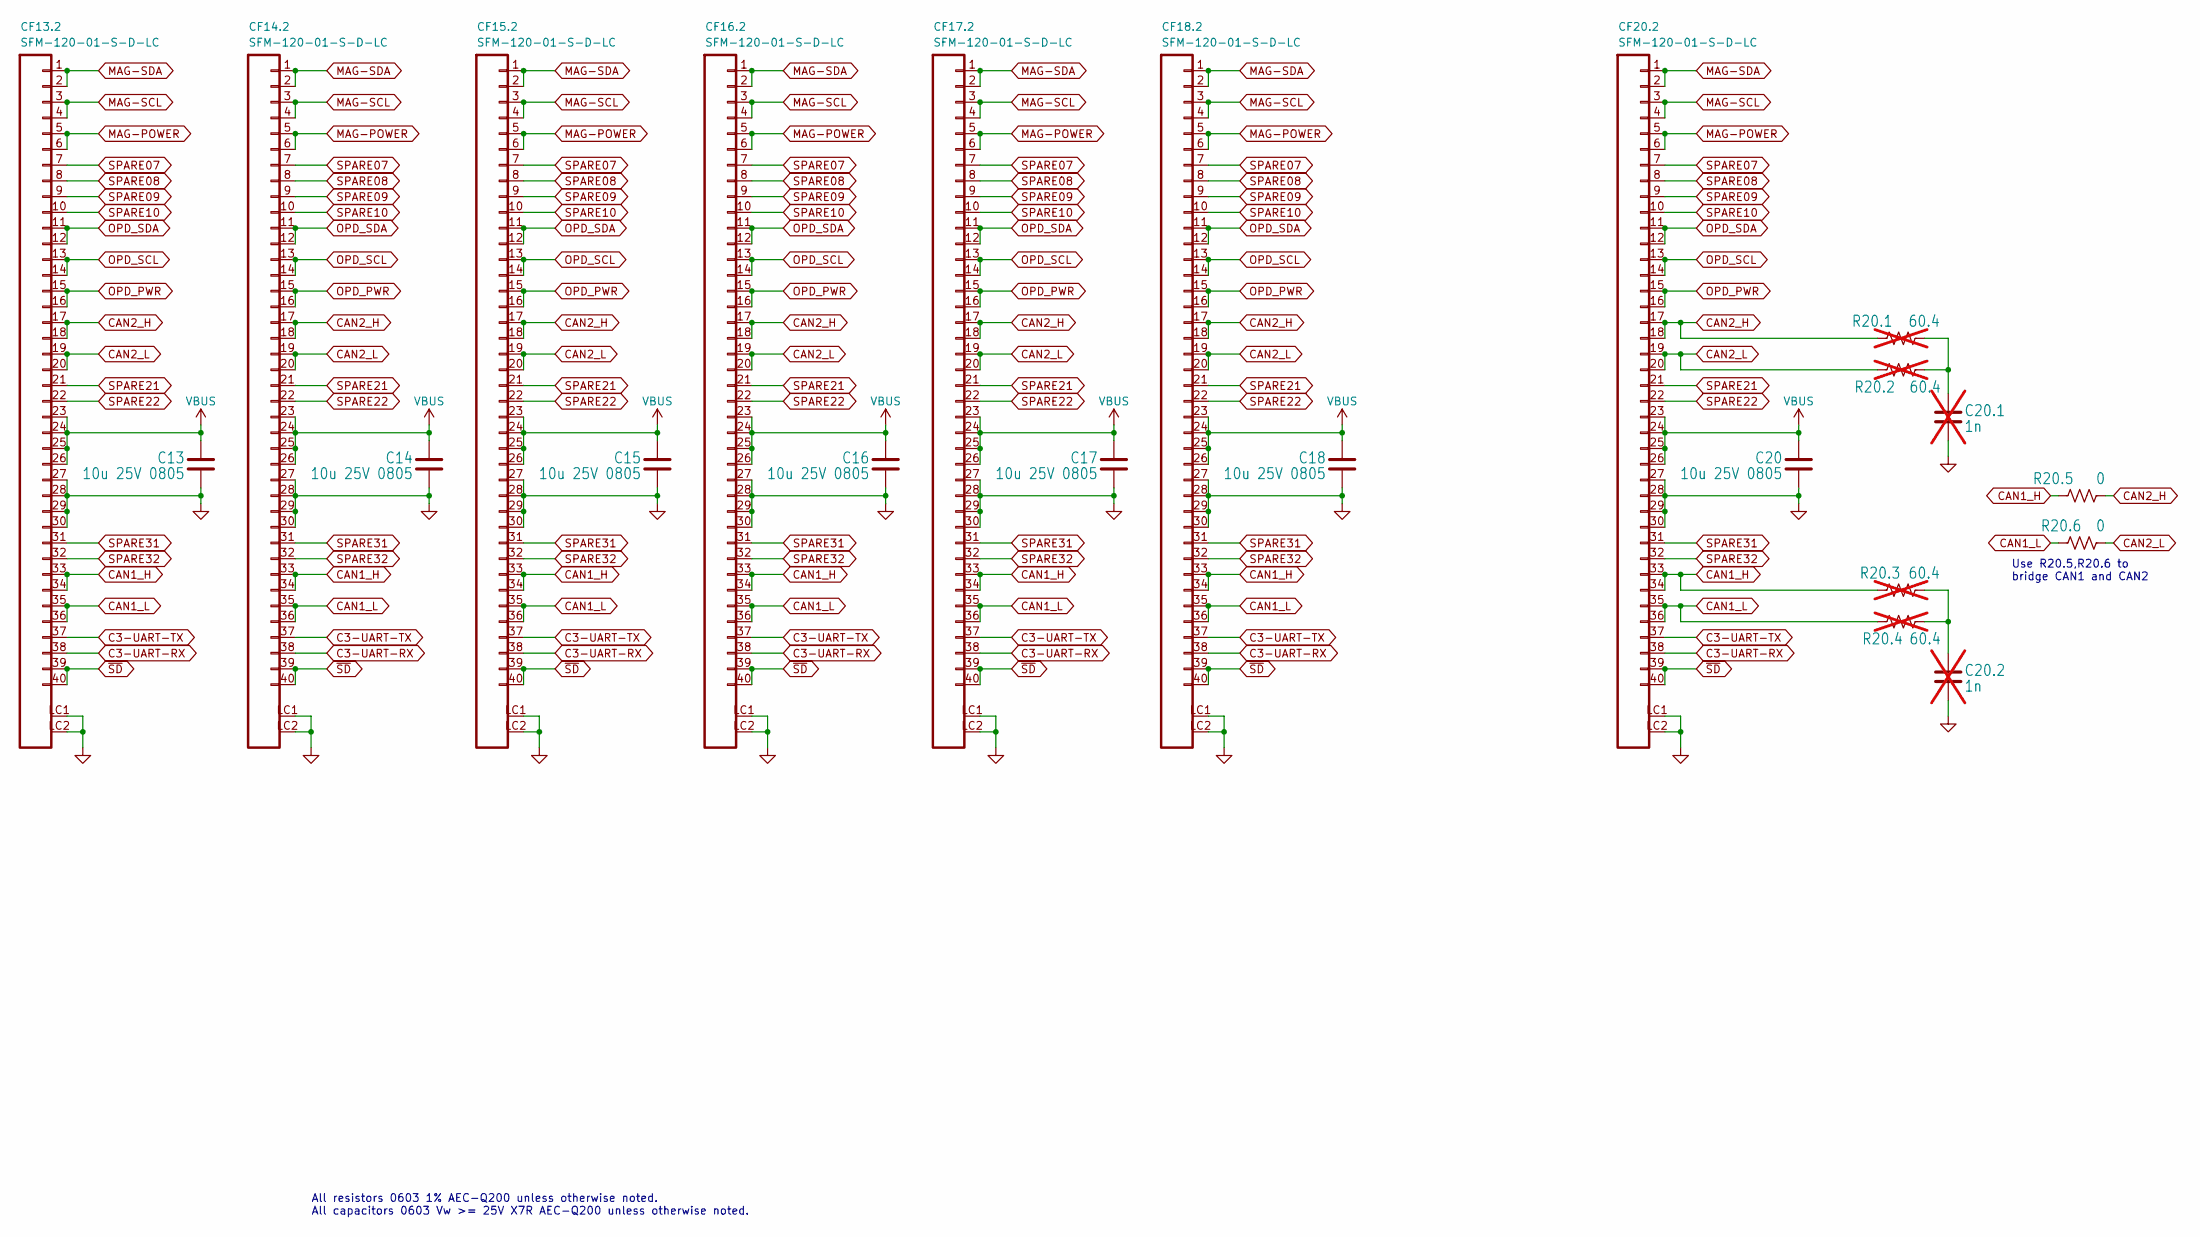
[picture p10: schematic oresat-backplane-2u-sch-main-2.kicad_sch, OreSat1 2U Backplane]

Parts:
C13, C14, C15, C16, C17, C18, C20: 10u 25V 0805; C_1206_3216Metric; MPN GRT31CR71E106KE13L
C20.1, C20.2: 1n; 0603-C-NOSILK; MPN C0603C102J5GECAUTO; not fitted
CF13.2, CF14.2, CF15.2, CF16.2, CF17.2, CF18.2, CF20.2: SFM-120-01-S-D-LC; J-SAMTEC-SFM-120-X1-XXX-D; MPN SFM-120-01-S-D-LC
R20.1, R20.2, R20.3, R20.4: 60.4; R_1206_3216Metric; MPN RMCF1206FT60R4; not fitted
R20.5, R20.6: 0; 0603-C-NOSILK; MPN RMCF0603ZT0R00

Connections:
C3-UART-RX: CF13.2.38, CF14.2.38, CF15.2.38, CF16.2.38, CF17.2.38, CF18.2.38, CF20.2.38; also elsewhere on the board
C3-UART-TX: CF13.2.37, CF14.2.37, CF15.2.37, CF16.2.37, CF17.2.37, CF18.2.37, CF20.2.37; also elsewhere on the board
CAN1_H: CF13.2.33, CF13.2.34, CF14.2.33, CF14.2.34, CF15.2.33, CF15.2.34, CF16.2.33, CF16.2.34, CF17.2.33, CF17.2.34, CF18.2.33, CF18.2.34, CF20.2.33, CF20.2.34, R20.3.1, R20.5.1; also elsewhere on the board
CAN1_L: CF13.2.35, CF13.2.36, CF14.2.35, CF14.2.36, CF15.2.35, CF15.2.36, CF16.2.35, CF16.2.36, CF17.2.35, CF17.2.36, CF18.2.35, CF18.2.36, CF20.2.35, CF20.2.36, R20.4.2, R20.6.1; also elsewhere on the board
CAN2_H: CF13.2.17, CF13.2.18, CF14.2.17, CF14.2.18, CF15.2.17, CF15.2.18, CF16.2.17, CF16.2.18, CF17.2.17, CF17.2.18, CF18.2.17, CF18.2.18, CF20.2.17, CF20.2.18, R20.1.1, R20.5.2; also elsewhere on the board
CAN2_L: CF13.2.19, CF13.2.20, CF14.2.19, CF14.2.20, CF15.2.19, CF15.2.20, CF16.2.19, CF16.2.20, CF17.2.19, CF17.2.20, CF18.2.19, CF18.2.20, CF20.2.19, CF20.2.20, R20.2.2, R20.6.2; also elsewhere on the board
GND: C13.2, C14.2, C15.2, C16.2, C17.2, C18.2, C20.2, C20.1.2, C20.2.2, CF13.2.27, CF13.2.28, CF13.2.29, CF13.2.30, CF13.2.LC1, CF13.2.LC2, CF14.2.27, CF14.2.28, CF14.2.29, CF14.2.30, CF14.2.LC1, CF14.2.LC2, CF15.2.27, CF15.2.28, CF15.2.29, CF15.2.30, CF15.2.LC1, CF15.2.LC2, CF16.2.27, CF16.2.28, CF16.2.29, CF16.2.30, CF16.2.LC1, CF16.2.LC2, CF17.2.27, CF17.2.28, CF17.2.29, CF17.2.30, CF17.2.LC1, CF17.2.LC2, CF18.2.27, CF18.2.28, CF18.2.29, CF18.2.30, CF18.2.LC1, CF18.2.LC2, CF20.2.27, CF20.2.28, CF20.2.29, CF20.2.30, CF20.2.LC1, CF20.2.LC2; also elsewhere on the board
MAG-POWER: CF13.2.5, CF13.2.6, CF14.2.5, CF14.2.6, CF15.2.5, CF15.2.6, CF16.2.5, CF16.2.6, CF17.2.5, CF17.2.6, CF18.2.5, CF18.2.6, CF20.2.5, CF20.2.6; also elsewhere on the board
MAG-SCL: CF13.2.3, CF13.2.4, CF14.2.3, CF14.2.4, CF15.2.3, CF15.2.4, CF16.2.3, CF16.2.4, CF17.2.3, CF17.2.4, CF18.2.3, CF18.2.4, CF20.2.3, CF20.2.4; also elsewhere on the board
MAG-SDA: CF13.2.1, CF13.2.2, CF14.2.1, CF14.2.2, CF15.2.1, CF15.2.2, CF16.2.1, CF16.2.2, CF17.2.1, CF17.2.2, CF18.2.1, CF18.2.2, CF20.2.1, CF20.2.2; also elsewhere on the board
unnamed: C20.1.1, R20.1.2, R20.2.1
unnamed: C20.2.1, R20.3.2, R20.4.1
OPD_PWR: CF13.2.15, CF13.2.16, CF14.2.15, CF14.2.16, CF15.2.15, CF15.2.16, CF16.2.15, CF16.2.16, CF17.2.15, CF17.2.16, CF18.2.15, CF18.2.16, CF20.2.15, CF20.2.16; also elsewhere on the board
OPD_SCL: CF13.2.13, CF13.2.14, CF14.2.13, CF14.2.14, CF15.2.13, CF15.2.14, CF16.2.13, CF16.2.14, CF17.2.13, CF17.2.14, CF18.2.13, CF18.2.14, CF20.2.13, CF20.2.14; also elsewhere on the board
OPD_SDA: CF13.2.11, CF13.2.12, CF14.2.11, CF14.2.12, CF15.2.11, CF15.2.12, CF16.2.11, CF16.2.12, CF17.2.11, CF17.2.12, CF18.2.11, CF18.2.12, CF20.2.11, CF20.2.12; also elsewhere on the board
SPARE07: CF13.2.7, CF14.2.7, CF15.2.7, CF16.2.7, CF17.2.7, CF18.2.7, CF20.2.7; also elsewhere on the board
SPARE08: CF13.2.8, CF14.2.8, CF15.2.8, CF16.2.8, CF17.2.8, CF18.2.8, CF20.2.8; also elsewhere on the board
SPARE09: CF13.2.9, CF14.2.9, CF15.2.9, CF16.2.9, CF17.2.9, CF18.2.9, CF20.2.9; also elsewhere on the board
SPARE10: CF13.2.10, CF14.2.10, CF15.2.10, CF16.2.10, CF17.2.10, CF18.2.10, CF20.2.10; also elsewhere on the board
SPARE21: CF13.2.21, CF14.2.21, CF15.2.21, CF16.2.21, CF17.2.21, CF18.2.21, CF20.2.21; also elsewhere on the board
SPARE22: CF13.2.22, CF14.2.22, CF15.2.22, CF16.2.22, CF17.2.22, CF18.2.22, CF20.2.22; also elsewhere on the board
SPARE31: CF13.2.31, CF14.2.31, CF15.2.31, CF16.2.31, CF17.2.31, CF18.2.31, CF20.2.31; also elsewhere on the board
SPARE32: CF13.2.32, CF14.2.32, CF15.2.32, CF16.2.32, CF17.2.32, CF18.2.32, CF20.2.32; also elsewhere on the board
VBUS: C13.1, C14.1, C15.1, C16.1, C17.1, C18.1, C20.1, CF13.2.23, CF13.2.24, CF13.2.25, CF13.2.26, CF14.2.23, CF14.2.24, CF14.2.25, CF14.2.26, CF15.2.23, CF15.2.24, CF15.2.25, CF15.2.26, CF16.2.23, CF16.2.24, CF16.2.25, CF16.2.26, CF17.2.23, CF17.2.24, CF17.2.25, CF17.2.26, CF18.2.23, CF18.2.24, CF18.2.25, CF18.2.26, CF20.2.23, CF20.2.24, CF20.2.25, CF20.2.26; also elsewhere on the board
~SD: CF13.2.39, CF13.2.40, CF14.2.39, CF14.2.40, CF15.2.39, CF15.2.40, CF16.2.39, CF16.2.40, CF17.2.39, CF17.2.40, CF18.2.39, CF18.2.40, CF20.2.39, CF20.2.40; also elsewhere on the board

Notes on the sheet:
Use R20.5,R20.6 to bridge CAN1 and CAN2
All resistors 0603 1% AEC-Q200 unless otherwise noted. All capacitors 0603 Vw >= 25V X7R AEC-Q200 unless otherwise noted.

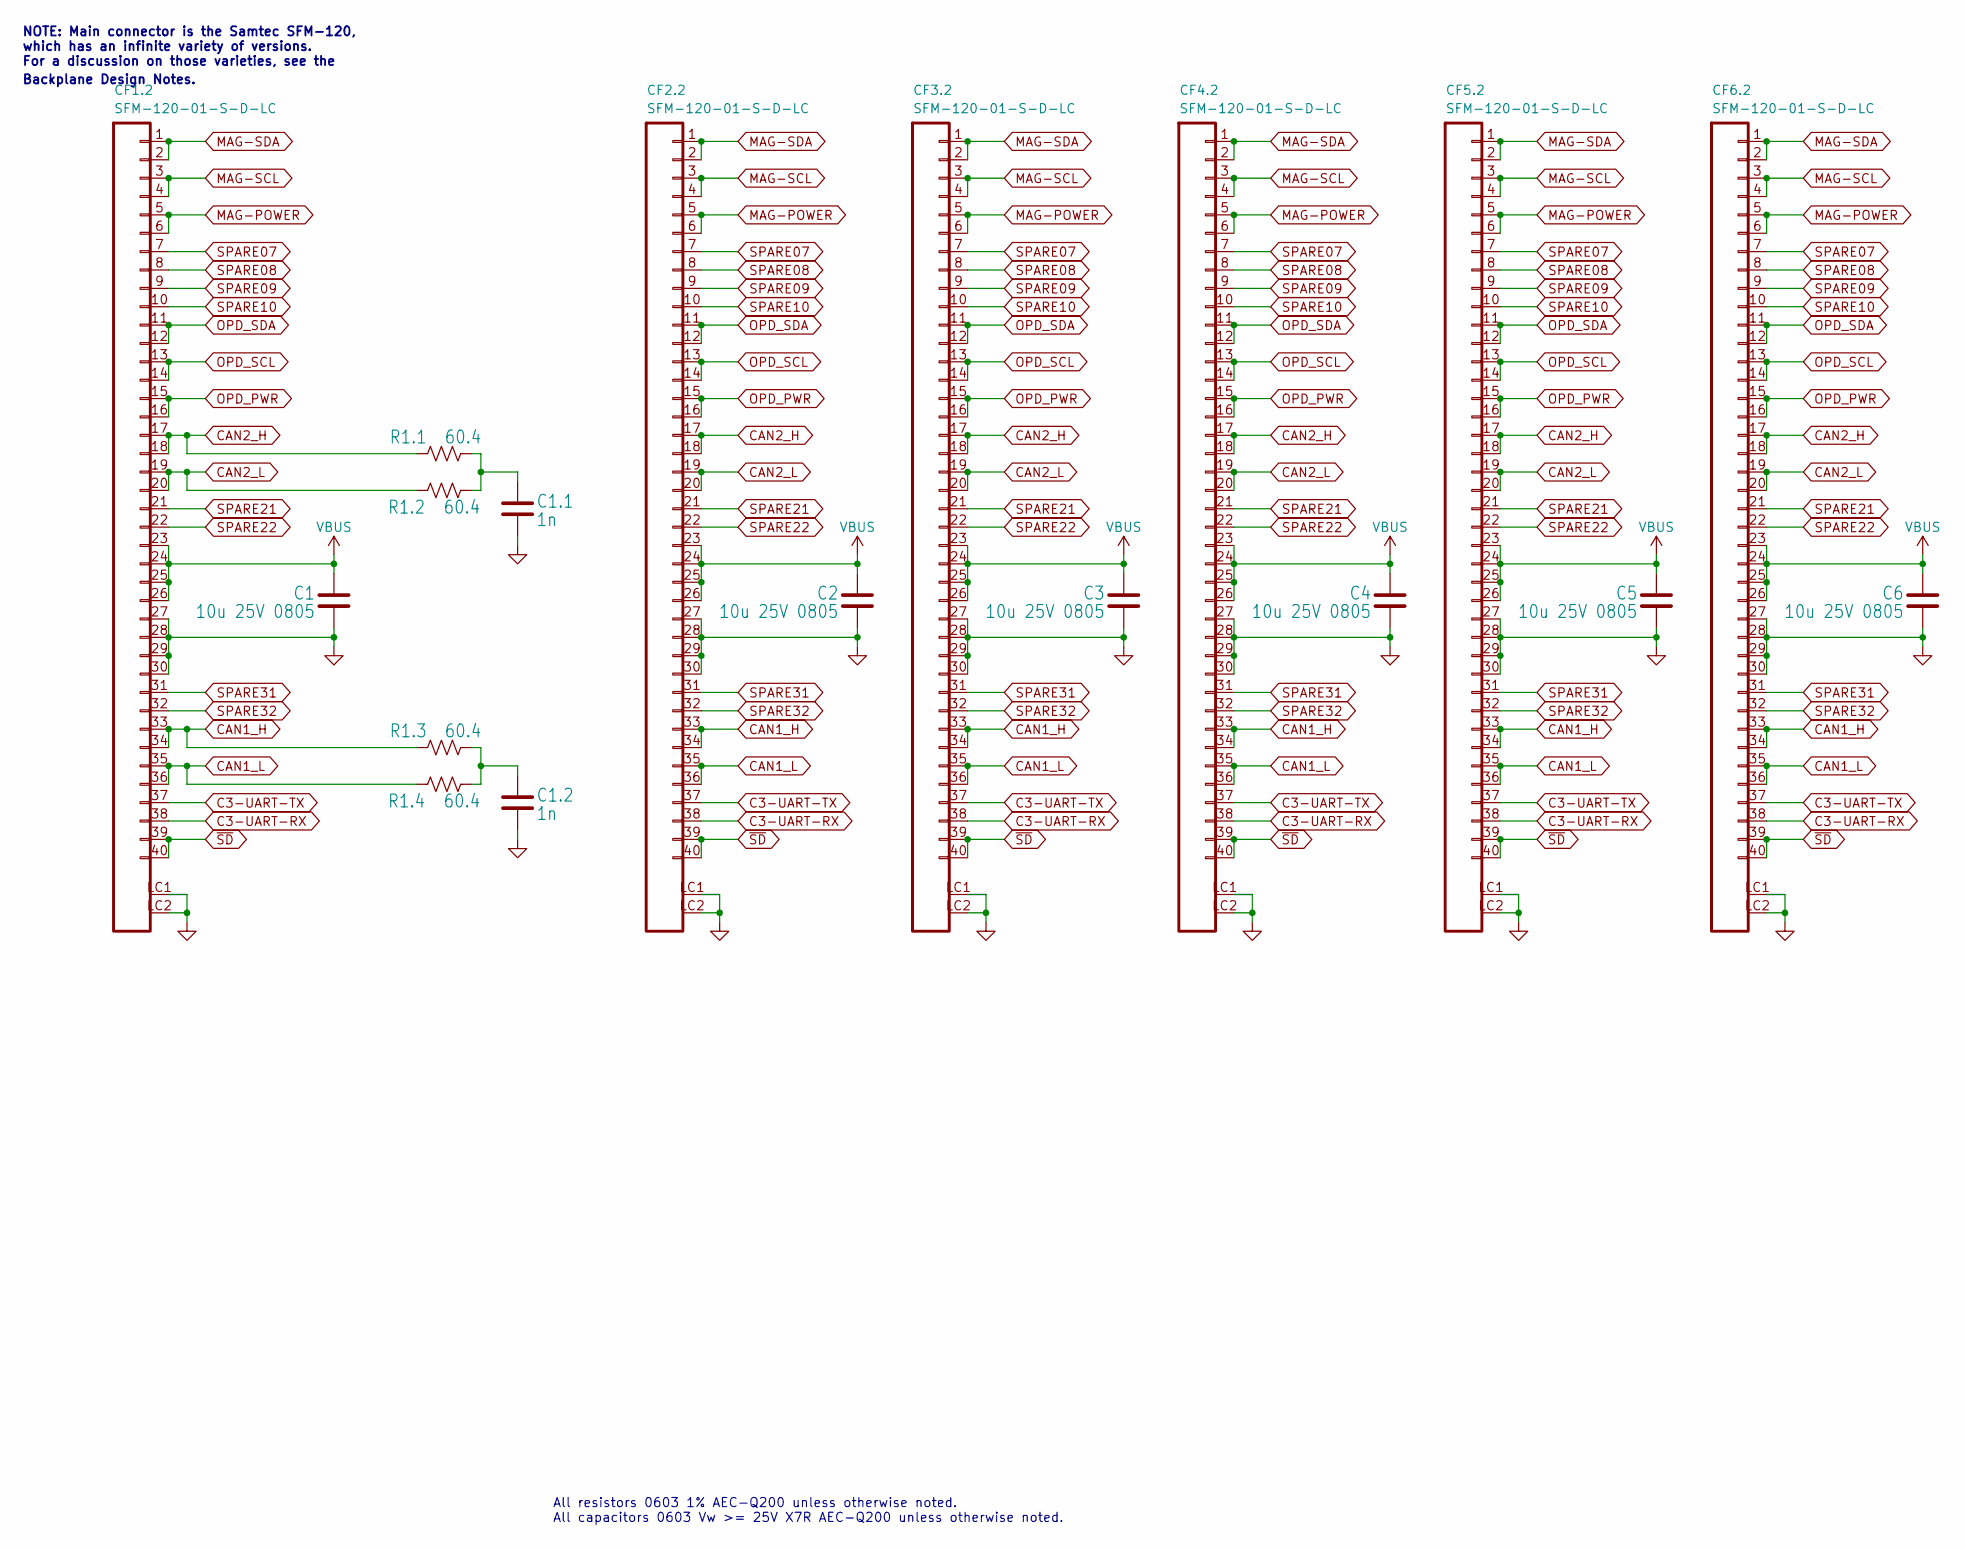
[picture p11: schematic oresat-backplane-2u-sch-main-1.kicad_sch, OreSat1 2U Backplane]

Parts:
C1, C2, C3, C4, C5, C6: 10u 25V 0805; C_1206_3216Metric; MPN GRT31CR71E106KE13L
C1.1, C1.2: 1n; 0603-C-NOSILK; MPN C0603C102J5GECAUTO
CF1.2, CF2.2, CF3.2, CF4.2, CF5.2, CF6.2: SFM-120-01-S-D-LC; J-SAMTEC-SFM-120-X1-XXX-D; MPN SFM-120-01-S-D-LC
R1.1, R1.2, R1.3, R1.4: 60.4; R_1206_3216Metric; MPN RMCF1206FT60R4

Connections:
C3-UART-RX: CF1.2.38, CF2.2.38, CF3.2.38, CF4.2.38, CF5.2.38, CF6.2.38; also elsewhere on the board
C3-UART-TX: CF1.2.37, CF2.2.37, CF3.2.37, CF4.2.37, CF5.2.37, CF6.2.37; also elsewhere on the board
CAN1_H: CF1.2.33, CF1.2.34, CF2.2.33, CF2.2.34, CF3.2.33, CF3.2.34, CF4.2.33, CF4.2.34, CF5.2.33, CF5.2.34, CF6.2.33, CF6.2.34, R1.3.2; also elsewhere on the board
CAN1_L: CF1.2.35, CF1.2.36, CF2.2.35, CF2.2.36, CF3.2.35, CF3.2.36, CF4.2.35, CF4.2.36, CF5.2.35, CF5.2.36, CF6.2.35, CF6.2.36, R1.4.1; also elsewhere on the board
CAN2_H: CF1.2.17, CF1.2.18, CF2.2.17, CF2.2.18, CF3.2.17, CF3.2.18, CF4.2.17, CF4.2.18, CF5.2.17, CF5.2.18, CF6.2.17, CF6.2.18, R1.1.2; also elsewhere on the board
CAN2_L: CF1.2.19, CF1.2.20, CF2.2.19, CF2.2.20, CF3.2.19, CF3.2.20, CF4.2.19, CF4.2.20, CF5.2.19, CF5.2.20, CF6.2.19, CF6.2.20, R1.2.1; also elsewhere on the board
GND: C1.2, C1.1.2, C1.2.2, C2.2, C3.2, C4.2, C5.2, C6.2, CF1.2.27, CF1.2.28, CF1.2.29, CF1.2.30, CF1.2.LC1, CF1.2.LC2, CF2.2.27, CF2.2.28, CF2.2.29, CF2.2.30, CF2.2.LC1, CF2.2.LC2, CF3.2.27, CF3.2.28, CF3.2.29, CF3.2.30, CF3.2.LC1, CF3.2.LC2, CF4.2.27, CF4.2.28, CF4.2.29, CF4.2.30, CF4.2.LC1, CF4.2.LC2, CF5.2.27, CF5.2.28, CF5.2.29, CF5.2.30, CF5.2.LC1, CF5.2.LC2, CF6.2.27, CF6.2.28, CF6.2.29, CF6.2.30, CF6.2.LC1, CF6.2.LC2; also elsewhere on the board
MAG-POWER: CF1.2.5, CF1.2.6, CF2.2.5, CF2.2.6, CF3.2.5, CF3.2.6, CF4.2.5, CF4.2.6, CF5.2.5, CF5.2.6, CF6.2.5, CF6.2.6; also elsewhere on the board
MAG-SCL: CF1.2.3, CF1.2.4, CF2.2.3, CF2.2.4, CF3.2.3, CF3.2.4, CF4.2.3, CF4.2.4, CF5.2.3, CF5.2.4, CF6.2.3, CF6.2.4; also elsewhere on the board
MAG-SDA: CF1.2.1, CF1.2.2, CF2.2.1, CF2.2.2, CF3.2.1, CF3.2.2, CF4.2.1, CF4.2.2, CF5.2.1, CF5.2.2, CF6.2.1, CF6.2.2; also elsewhere on the board
unnamed: C1.1.1, R1.1.1, R1.2.2
unnamed: C1.2.1, R1.3.1, R1.4.2
OPD_PWR: CF1.2.15, CF1.2.16, CF2.2.15, CF2.2.16, CF3.2.15, CF3.2.16, CF4.2.15, CF4.2.16, CF5.2.15, CF5.2.16, CF6.2.15, CF6.2.16; also elsewhere on the board
OPD_SCL: CF1.2.13, CF1.2.14, CF2.2.13, CF2.2.14, CF3.2.13, CF3.2.14, CF4.2.13, CF4.2.14, CF5.2.13, CF5.2.14, CF6.2.13, CF6.2.14; also elsewhere on the board
OPD_SDA: CF1.2.11, CF1.2.12, CF2.2.11, CF2.2.12, CF3.2.11, CF3.2.12, CF4.2.11, CF4.2.12, CF5.2.11, CF5.2.12, CF6.2.11, CF6.2.12; also elsewhere on the board
SPARE07: CF1.2.7, CF2.2.7, CF3.2.7, CF4.2.7, CF5.2.7, CF6.2.7; also elsewhere on the board
SPARE08: CF1.2.8, CF2.2.8, CF3.2.8, CF4.2.8, CF5.2.8, CF6.2.8; also elsewhere on the board
SPARE09: CF1.2.9, CF2.2.9, CF3.2.9, CF4.2.9, CF5.2.9, CF6.2.9; also elsewhere on the board
SPARE10: CF1.2.10, CF2.2.10, CF3.2.10, CF4.2.10, CF5.2.10, CF6.2.10; also elsewhere on the board
SPARE21: CF1.2.21, CF2.2.21, CF3.2.21, CF4.2.21, CF5.2.21, CF6.2.21; also elsewhere on the board
SPARE22: CF1.2.22, CF2.2.22, CF3.2.22, CF4.2.22, CF5.2.22, CF6.2.22; also elsewhere on the board
SPARE31: CF1.2.31, CF2.2.31, CF3.2.31, CF4.2.31, CF5.2.31, CF6.2.31; also elsewhere on the board
SPARE32: CF1.2.32, CF2.2.32, CF3.2.32, CF4.2.32, CF5.2.32, CF6.2.32; also elsewhere on the board
VBUS: C1.1, C2.1, C3.1, C4.1, C5.1, C6.1, CF1.2.23, CF1.2.24, CF1.2.25, CF1.2.26, CF2.2.23, CF2.2.24, CF2.2.25, CF2.2.26, CF3.2.23, CF3.2.24, CF3.2.25, CF3.2.26, CF4.2.23, CF4.2.24, CF4.2.25, CF4.2.26, CF5.2.23, CF5.2.24, CF5.2.25, CF5.2.26, CF6.2.23, CF6.2.24, CF6.2.25, CF6.2.26; also elsewhere on the board
~SD: CF1.2.39, CF1.2.40, CF2.2.39, CF2.2.40, CF3.2.39, CF3.2.40, CF4.2.39, CF4.2.40, CF5.2.39, CF5.2.40, CF6.2.39, CF6.2.40; also elsewhere on the board

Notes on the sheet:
NOTE: Main connector is the Samtec SFM-120, which has an infinite variety of versions. For a discussion on those varieties, see the
All resistors 0603 1% AEC-Q200 unless otherwise noted. All capacitors 0603 Vw >= 25V X7R AEC-Q200 unless otherwise noted.
Backplane Design Notes.

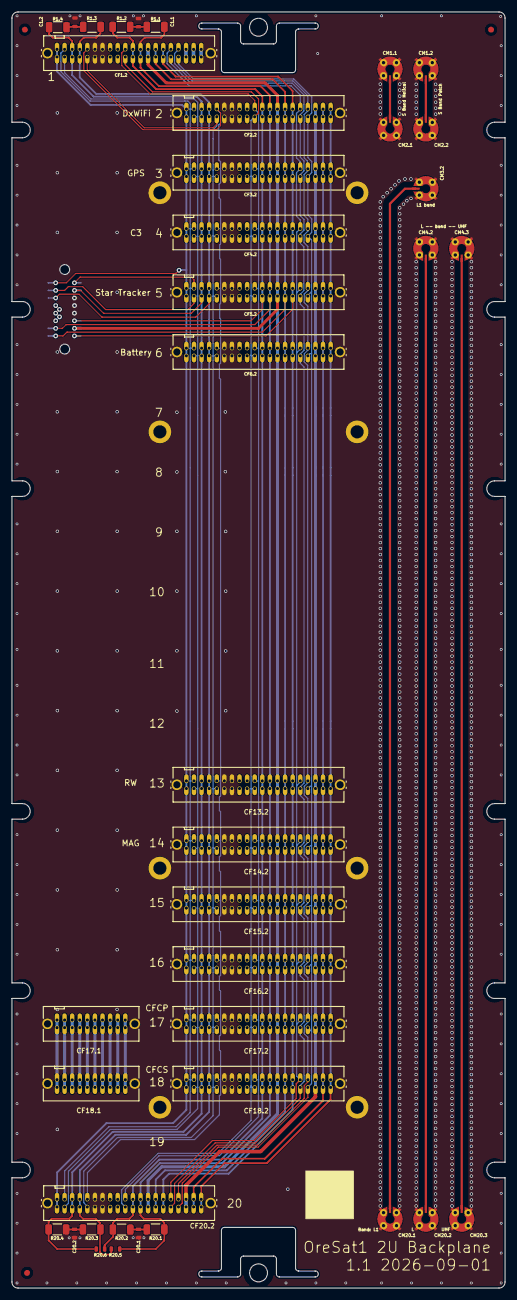
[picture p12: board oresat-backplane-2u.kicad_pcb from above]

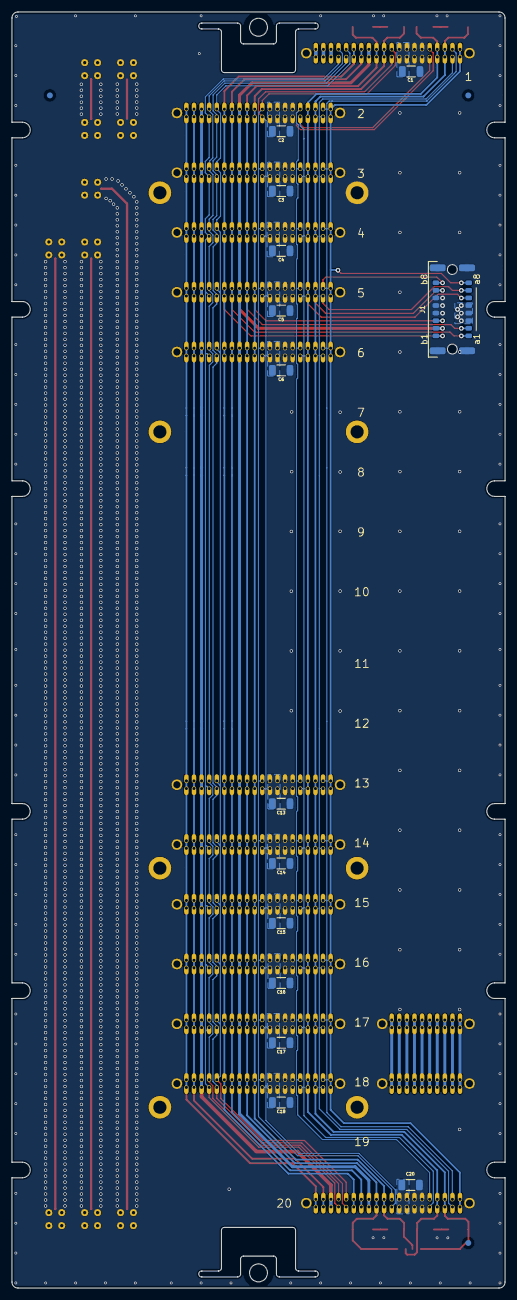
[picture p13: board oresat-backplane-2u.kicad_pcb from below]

Board: 4 copper layers, 82.5 x 213.5 mm, 69 parts (17 on the bottom side), 42 nets.

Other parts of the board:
PH1, PH2: MountingHole_3mm

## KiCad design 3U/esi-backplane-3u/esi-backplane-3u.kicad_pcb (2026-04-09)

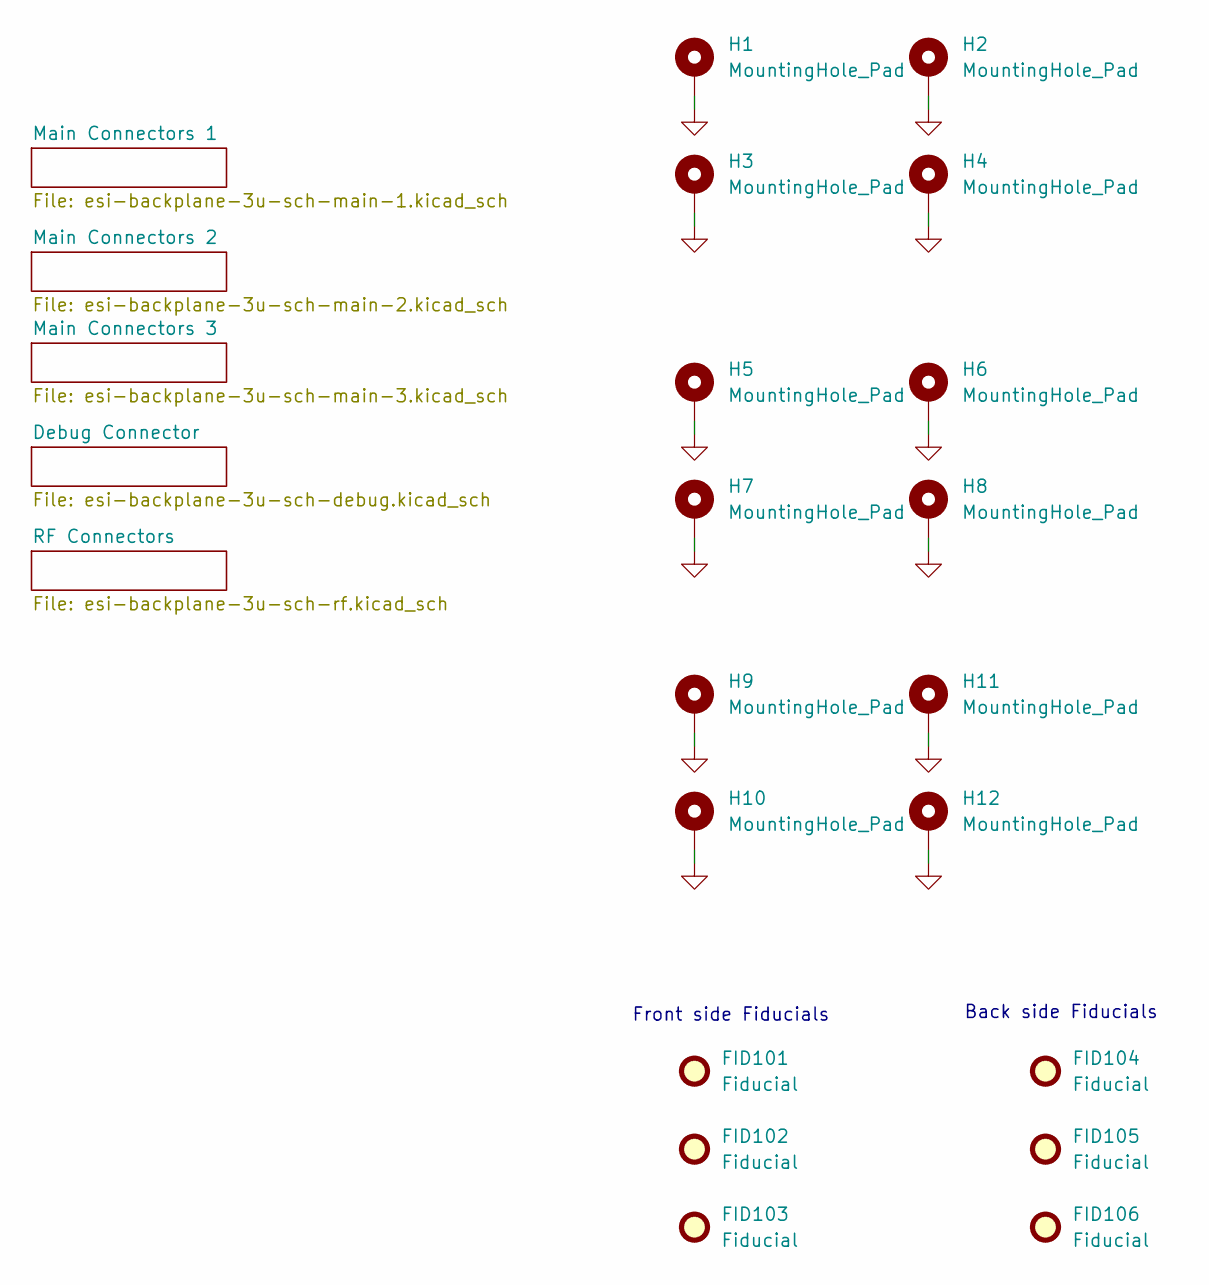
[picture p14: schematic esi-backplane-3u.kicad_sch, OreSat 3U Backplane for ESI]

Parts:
FID101, FID102, FID103, FID104, FID105, FID106: Fiducial; Fiducial_1mm_Mask2mm
H1, H2, H3, H4, H5, H6, H7, H8, H9, H10, H11, H12: MountingHole_Pad; MountingHole_2.2mm_M2_DIN965_Pad

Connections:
GND: H1.1, H2.1, H3.1, H4.1, H5.1, H6.1, H7.1, H8.1, H9.1, H10.1, H11.1, H12.1; also elsewhere on the board

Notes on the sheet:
Front side Fiducials
Back side Fiducials

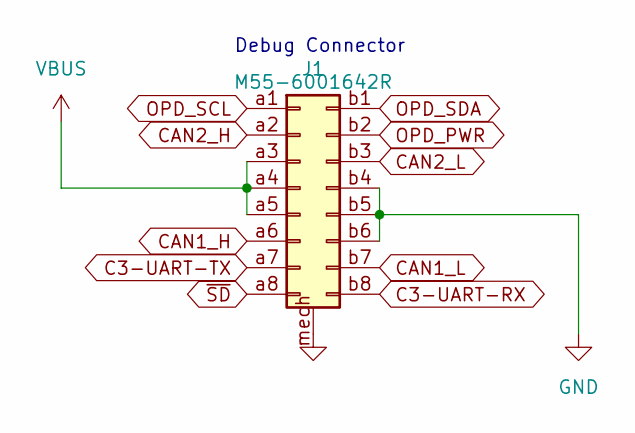
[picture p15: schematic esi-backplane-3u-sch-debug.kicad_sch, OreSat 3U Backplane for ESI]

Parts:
J1: M55-6001642R; m55-6001642; MPN M55-6001642R

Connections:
C3-UART-RX: J1.b8; also elsewhere on the board
C3-UART-TX: J1.a7; also elsewhere on the board
CAN1_H: J1.a6; also elsewhere on the board
CAN1_L: J1.b7; also elsewhere on the board
CAN2_H: J1.a2; also elsewhere on the board
CAN2_L: J1.b3; also elsewhere on the board
GND: J1.b4, J1.b5, J1.b6, J1.mech; also elsewhere on the board
OPD_PWR: J1.b2; also elsewhere on the board
OPD_SCL: J1.a1; also elsewhere on the board
OPD_SDA: J1.b1; also elsewhere on the board
VBUS: J1.a3, J1.a4, J1.a5; also elsewhere on the board
~SD: J1.a8; also elsewhere on the board

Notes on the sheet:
Debug Connector

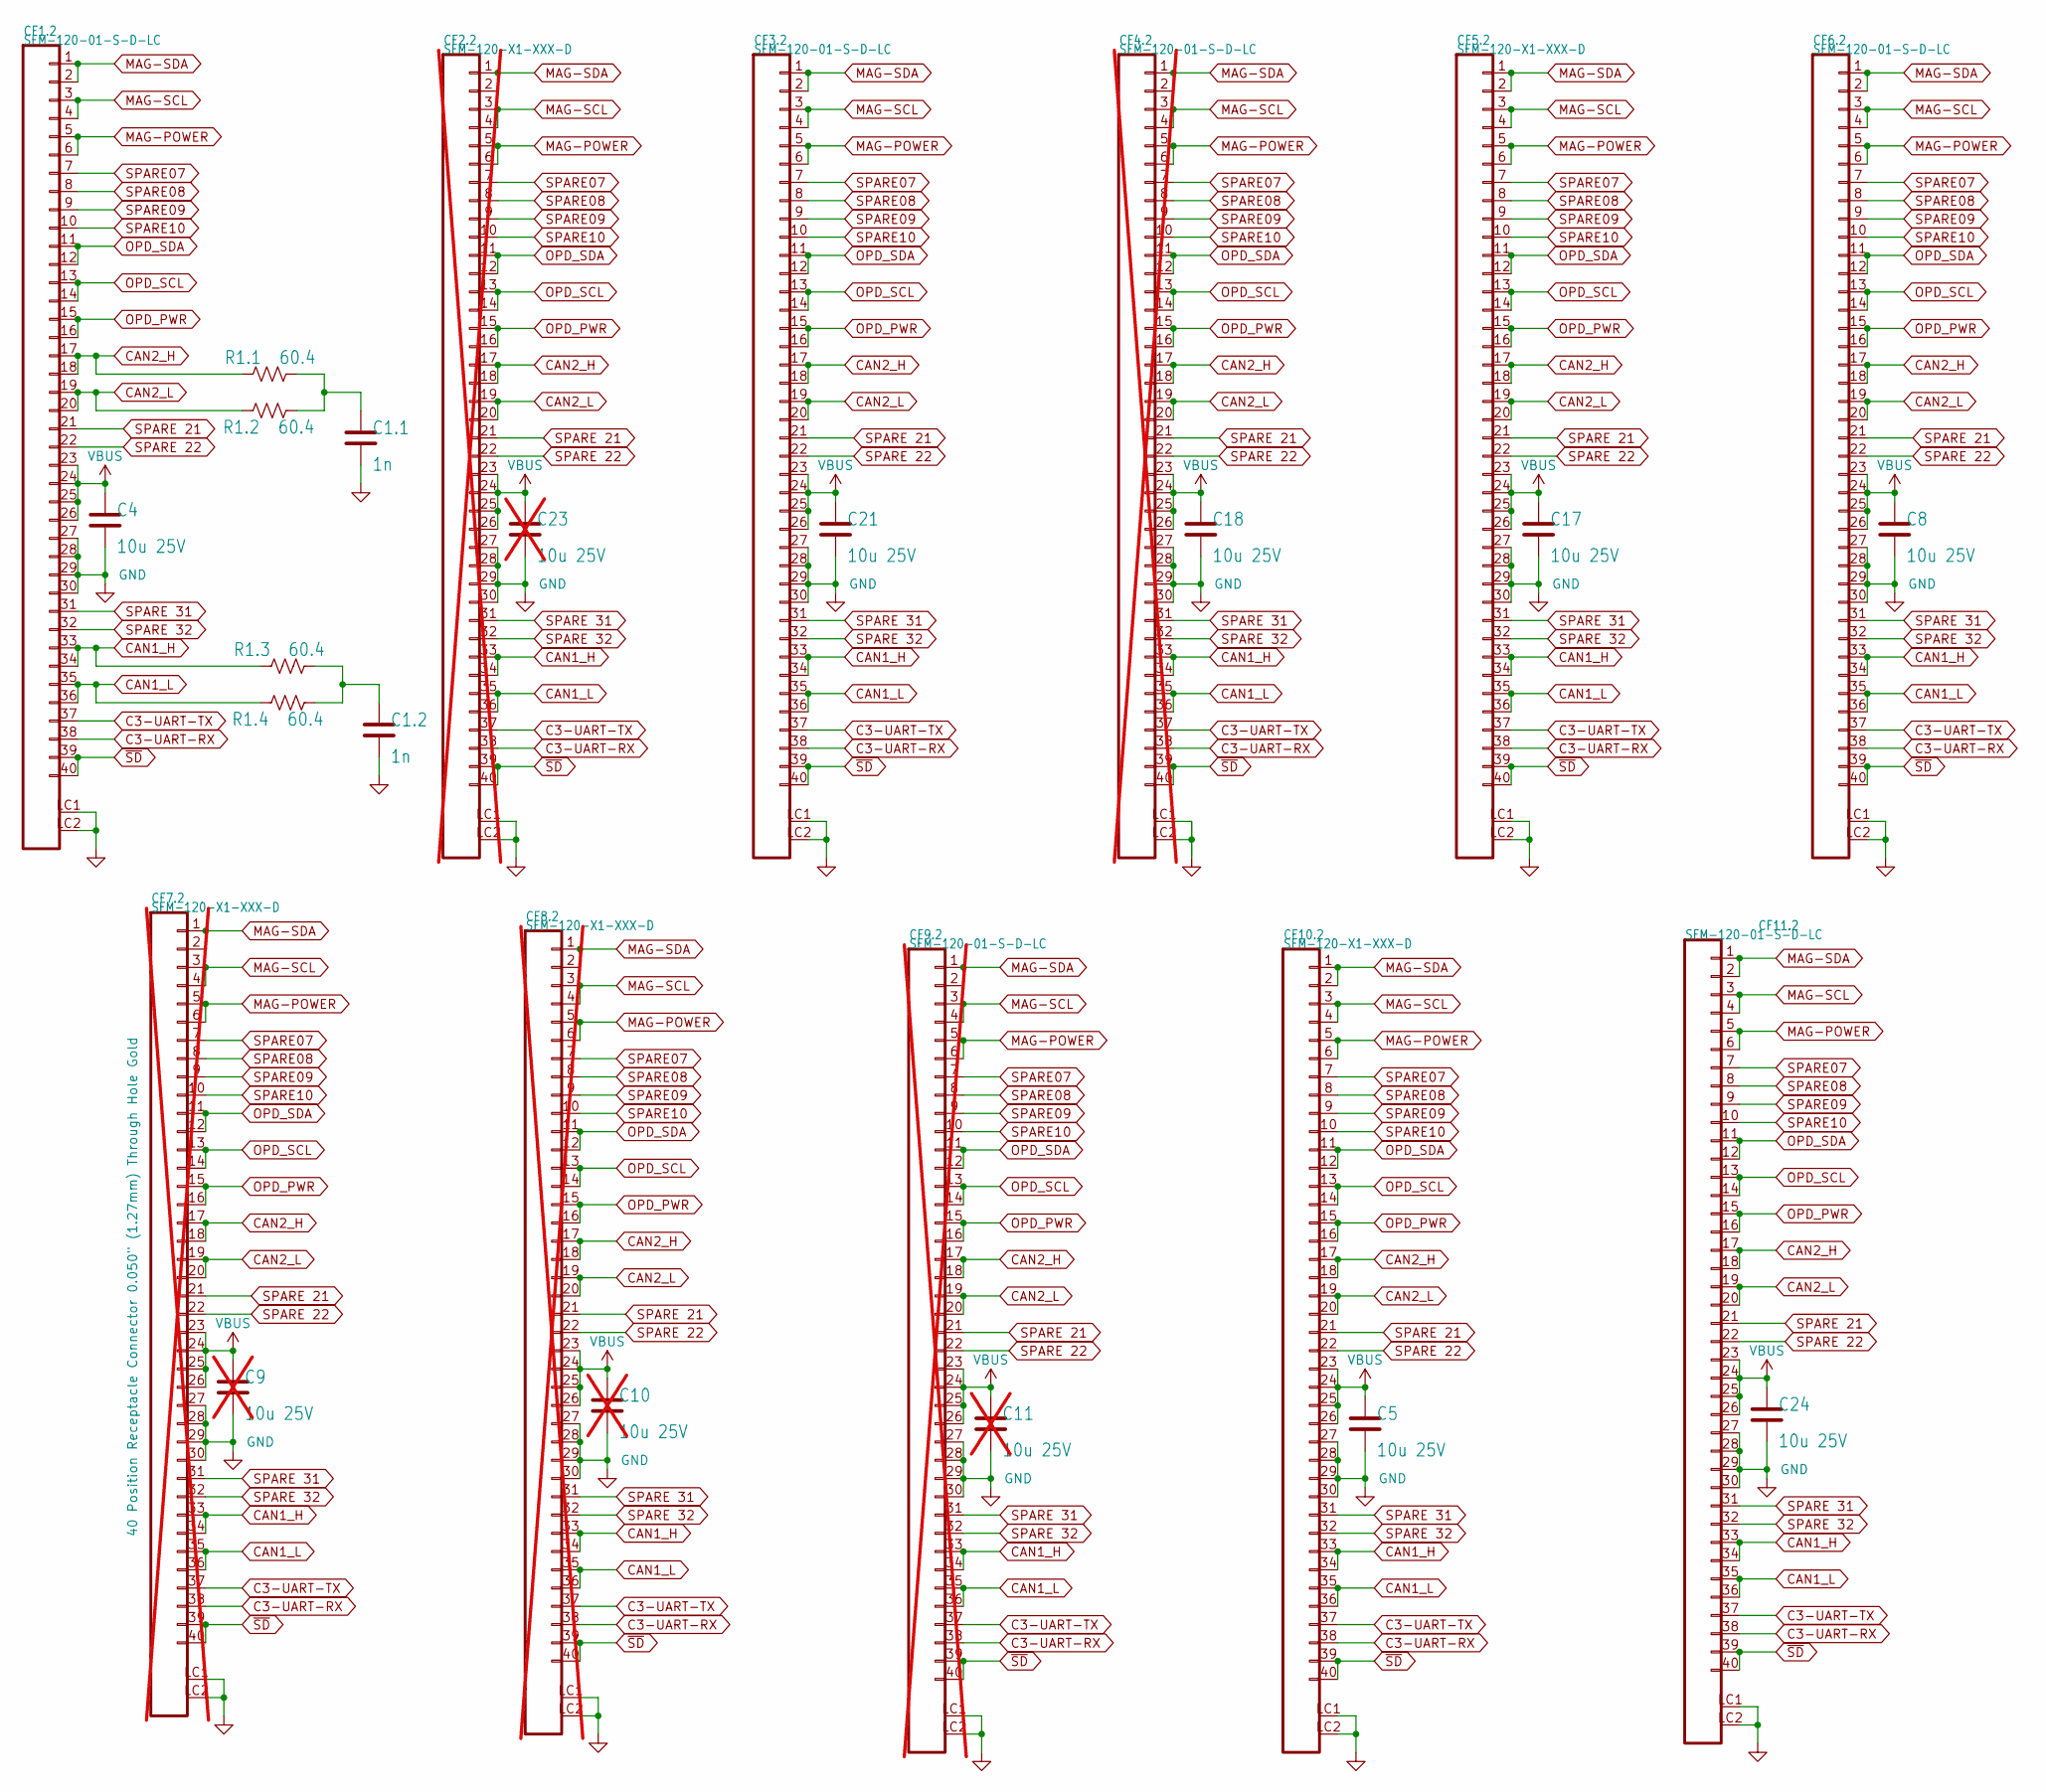
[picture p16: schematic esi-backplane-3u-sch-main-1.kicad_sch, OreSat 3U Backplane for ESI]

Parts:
C1.1, C1.2: 1n; 0603-C-NOSILK; MPN C0603C102J5GECAUTO
C4, C5, C8, C17, C18, C21, C24: 10u 25V; C_1206_3216Metric; MPN TMK316AB7106KLHT
C9, C10, C11, C23: 10u 25V; C_1206_3216Metric; MPN TMK316AB7106KLHT; not fitted
CF1.2, CF3.2, CF6.2, CF11.2: SFM-120-01-S-D-LC; J-SAMTEC-SFM-120-X1-XXX-D; MPN SFM-120-01-S-D-LC
CF2.2, CF7.2, CF8.2: SFM-120-X1-XXX-D; J-SAMTEC-SFM-120-X1-XXX-D; MPN SFM-120-01-S-D-LC; not fitted
CF4.2, CF9.2: SFM-120-01-S-D-LC; J-SAMTEC-SFM-120-X1-XXX-D; MPN SFM-120-01-S-D-LC; not fitted
CF5.2, CF10.2: SFM-120-X1-XXX-D; J-SAMTEC-SFM-120-X1-XXX-D; MPN SFM-120-01-S-D-LC
R1.1, R1.2, R1.3, R1.4: 60.4; R_1206_3216Metric; MPN RMCF1206FT60R4

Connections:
C3-UART-RX: CF1.2.38, CF2.2.38, CF3.2.38, CF4.2.38, CF5.2.38, CF6.2.38, CF7.2.38, CF8.2.38, CF9.2.38, CF10.2.38, CF11.2.38; also elsewhere on the board
C3-UART-TX: CF1.2.37, CF2.2.37, CF3.2.37, CF4.2.37, CF5.2.37, CF6.2.37, CF7.2.37, CF8.2.37, CF9.2.37, CF10.2.37, CF11.2.37; also elsewhere on the board
CAN1_H: CF1.2.33, CF1.2.34, CF2.2.33, CF2.2.34, CF3.2.33, CF3.2.34, CF4.2.33, CF4.2.34, CF5.2.33, CF5.2.34, CF6.2.33, CF6.2.34, CF7.2.33, CF7.2.34, CF8.2.33, CF8.2.34, CF9.2.33, CF9.2.34, CF10.2.33, CF10.2.34, CF11.2.33, CF11.2.34, R1.3.2; also elsewhere on the board
CAN1_L: CF1.2.35, CF1.2.36, CF2.2.35, CF2.2.36, CF3.2.35, CF3.2.36, CF4.2.35, CF4.2.36, CF5.2.35, CF5.2.36, CF6.2.35, CF6.2.36, CF7.2.35, CF7.2.36, CF8.2.35, CF8.2.36, CF9.2.35, CF9.2.36, CF10.2.35, CF10.2.36, CF11.2.35, CF11.2.36, R1.4.1; also elsewhere on the board
CAN2_H: CF1.2.17, CF1.2.18, CF2.2.17, CF2.2.18, CF3.2.17, CF3.2.18, CF4.2.17, CF4.2.18, CF5.2.17, CF5.2.18, CF6.2.17, CF6.2.18, CF7.2.17, CF7.2.18, CF8.2.17, CF8.2.18, CF9.2.17, CF9.2.18, CF10.2.17, CF10.2.18, CF11.2.17, CF11.2.18, R1.1.2; also elsewhere on the board
CAN2_L: CF1.2.19, CF1.2.20, CF2.2.19, CF2.2.20, CF3.2.19, CF3.2.20, CF4.2.19, CF4.2.20, CF5.2.19, CF5.2.20, CF6.2.19, CF6.2.20, CF7.2.19, CF7.2.20, CF8.2.19, CF8.2.20, CF9.2.19, CF9.2.20, CF10.2.19, CF10.2.20, CF11.2.19, CF11.2.20, R1.2.1; also elsewhere on the board
GND: C1.1.2, C1.2.2, C4.2, C5.2, C8.2, C9.2, C10.2, C11.2, C17.2, C18.2, C21.2, C23.2, C24.2, CF1.2.27, CF1.2.28, CF1.2.29, CF1.2.30, CF1.2.LC1, CF1.2.LC2, CF2.2.27, CF2.2.28, CF2.2.29, CF2.2.30, CF2.2.LC1, CF2.2.LC2, CF3.2.27, CF3.2.28, CF3.2.29, CF3.2.30, CF3.2.LC1, CF3.2.LC2, CF4.2.27, CF4.2.28, CF4.2.29, CF4.2.30, CF4.2.LC1, CF4.2.LC2, CF5.2.27, CF5.2.28, CF5.2.29, CF5.2.30, CF5.2.LC1, CF5.2.LC2, CF6.2.27, CF6.2.28, CF6.2.29, CF6.2.30, CF6.2.LC1, CF6.2.LC2, CF7.2.27, CF7.2.28, CF7.2.29, CF7.2.30, CF7.2.LC1, CF7.2.LC2, CF8.2.27, CF8.2.28, CF8.2.29, CF8.2.30, CF8.2.LC1, CF8.2.LC2, CF9.2.27, CF9.2.28, CF9.2.29, CF9.2.30, CF9.2.LC1, CF9.2.LC2, CF10.2.27, CF10.2.28, CF10.2.29, CF10.2.30, CF10.2.LC1, CF10.2.LC2, CF11.2.27, CF11.2.28, CF11.2.29, CF11.2.30, CF11.2.LC1, CF11.2.LC2; also elsewhere on the board
MAG-POWER: CF1.2.5, CF1.2.6, CF2.2.5, CF2.2.6, CF3.2.5, CF3.2.6, CF4.2.5, CF4.2.6, CF5.2.5, CF5.2.6, CF6.2.5, CF6.2.6, CF7.2.5, CF7.2.6, CF8.2.5, CF8.2.6, CF9.2.5, CF9.2.6, CF10.2.5, CF10.2.6, CF11.2.5, CF11.2.6; also elsewhere on the board
MAG-SCL: CF1.2.3, CF1.2.4, CF2.2.3, CF2.2.4, CF3.2.3, CF3.2.4, CF4.2.3, CF4.2.4, CF5.2.3, CF5.2.4, CF6.2.3, CF6.2.4, CF7.2.3, CF7.2.4, CF8.2.3, CF8.2.4, CF9.2.3, CF9.2.4, CF10.2.3, CF10.2.4, CF11.2.3, CF11.2.4; also elsewhere on the board
MAG-SDA: CF1.2.1, CF1.2.2, CF2.2.1, CF2.2.2, CF3.2.1, CF3.2.2, CF4.2.1, CF4.2.2, CF5.2.1, CF5.2.2, CF6.2.1, CF6.2.2, CF7.2.1, CF7.2.2, CF8.2.1, CF8.2.2, CF9.2.1, CF9.2.2, CF10.2.1, CF10.2.2, CF11.2.1, CF11.2.2; also elsewhere on the board
unnamed: C1.1.1, R1.1.1, R1.2.2
unnamed: C1.2.1, R1.3.1, R1.4.2
OPD_PWR: CF1.2.15, CF1.2.16, CF2.2.15, CF2.2.16, CF3.2.15, CF3.2.16, CF4.2.15, CF4.2.16, CF5.2.15, CF5.2.16, CF6.2.15, CF6.2.16, CF7.2.15, CF7.2.16, CF8.2.15, CF8.2.16, CF9.2.15, CF9.2.16, CF10.2.15, CF10.2.16, CF11.2.15, CF11.2.16; also elsewhere on the board
OPD_SCL: CF1.2.13, CF1.2.14, CF2.2.13, CF2.2.14, CF3.2.13, CF3.2.14, CF4.2.13, CF4.2.14, CF5.2.13, CF5.2.14, CF6.2.13, CF6.2.14, CF7.2.13, CF7.2.14, CF8.2.13, CF8.2.14, CF9.2.13, CF9.2.14, CF10.2.13, CF10.2.14, CF11.2.13, CF11.2.14; also elsewhere on the board
OPD_SDA: CF1.2.11, CF1.2.12, CF2.2.11, CF2.2.12, CF3.2.11, CF3.2.12, CF4.2.11, CF4.2.12, CF5.2.11, CF5.2.12, CF6.2.11, CF6.2.12, CF7.2.11, CF7.2.12, CF8.2.11, CF8.2.12, CF9.2.11, CF9.2.12, CF10.2.11, CF10.2.12, CF11.2.11, CF11.2.12; also elsewhere on the board
SPARE07: CF1.2.7, CF2.2.7, CF3.2.7, CF4.2.7, CF5.2.7, CF6.2.7, CF7.2.7, CF8.2.7, CF9.2.7, CF10.2.7, CF11.2.7; also elsewhere on the board
SPARE08: CF1.2.8, CF2.2.8, CF3.2.8, CF4.2.8, CF5.2.8, CF6.2.8, CF7.2.8, CF8.2.8, CF9.2.8, CF10.2.8, CF11.2.8; also elsewhere on the board
SPARE09: CF1.2.9, CF2.2.9, CF3.2.9, CF4.2.9, CF5.2.9, CF6.2.9, CF7.2.9, CF8.2.9, CF9.2.9, CF10.2.9, CF11.2.9; also elsewhere on the board
SPARE10: CF1.2.10, CF2.2.10, CF3.2.10, CF4.2.10, CF5.2.10, CF6.2.10, CF7.2.10, CF8.2.10, CF9.2.10, CF10.2.10, CF11.2.10; also elsewhere on the board
SPARE 21: CF1.2.21, CF2.2.21, CF3.2.21, CF4.2.21, CF5.2.21, CF6.2.21, CF7.2.21, CF8.2.21, CF9.2.21, CF10.2.21, CF11.2.21; also elsewhere on the board
SPARE 22: CF1.2.22, CF2.2.22, CF3.2.22, CF4.2.22, CF5.2.22, CF6.2.22, CF7.2.22, CF8.2.22, CF9.2.22, CF10.2.22, CF11.2.22; also elsewhere on the board
SPARE 31: CF1.2.31, CF2.2.31, CF3.2.31, CF4.2.31, CF5.2.31, CF6.2.31, CF7.2.31, CF8.2.31, CF9.2.31, CF10.2.31, CF11.2.31; also elsewhere on the board
SPARE 32: CF1.2.32, CF2.2.32, CF3.2.32, CF4.2.32, CF5.2.32, CF6.2.32, CF7.2.32, CF8.2.32, CF9.2.32, CF10.2.32, CF11.2.32; also elsewhere on the board
VBUS: C4.1, C5.1, C8.1, C9.1, C10.1, C11.1, C17.1, C18.1, C21.1, C23.1, C24.1, CF1.2.23, CF1.2.24, CF1.2.25, CF1.2.26, CF2.2.23, CF2.2.24, CF2.2.25, CF2.2.26, CF3.2.23, CF3.2.24, CF3.2.25, CF3.2.26, CF4.2.23, CF4.2.24, CF4.2.25, CF4.2.26, CF5.2.23, CF5.2.24, CF5.2.25, CF5.2.26, CF6.2.23, CF6.2.24, CF6.2.25, CF6.2.26, CF7.2.23, CF7.2.24, CF7.2.25, CF7.2.26, CF8.2.23, CF8.2.24, CF8.2.25, CF8.2.26, CF9.2.23, CF9.2.24, CF9.2.25, CF9.2.26, CF10.2.23, CF10.2.24, CF10.2.25, CF10.2.26, CF11.2.23, CF11.2.24, CF11.2.25, CF11.2.26; also elsewhere on the board
~SD: CF1.2.39, CF1.2.40, CF2.2.39, CF2.2.40, CF3.2.39, CF3.2.40, CF4.2.39, CF4.2.40, CF5.2.39, CF5.2.40, CF6.2.39, CF6.2.40, CF7.2.39, CF7.2.40, CF8.2.39, CF8.2.40, CF9.2.39, CF9.2.40, CF10.2.39, CF10.2.40, CF11.2.39, CF11.2.40; also elsewhere on the board

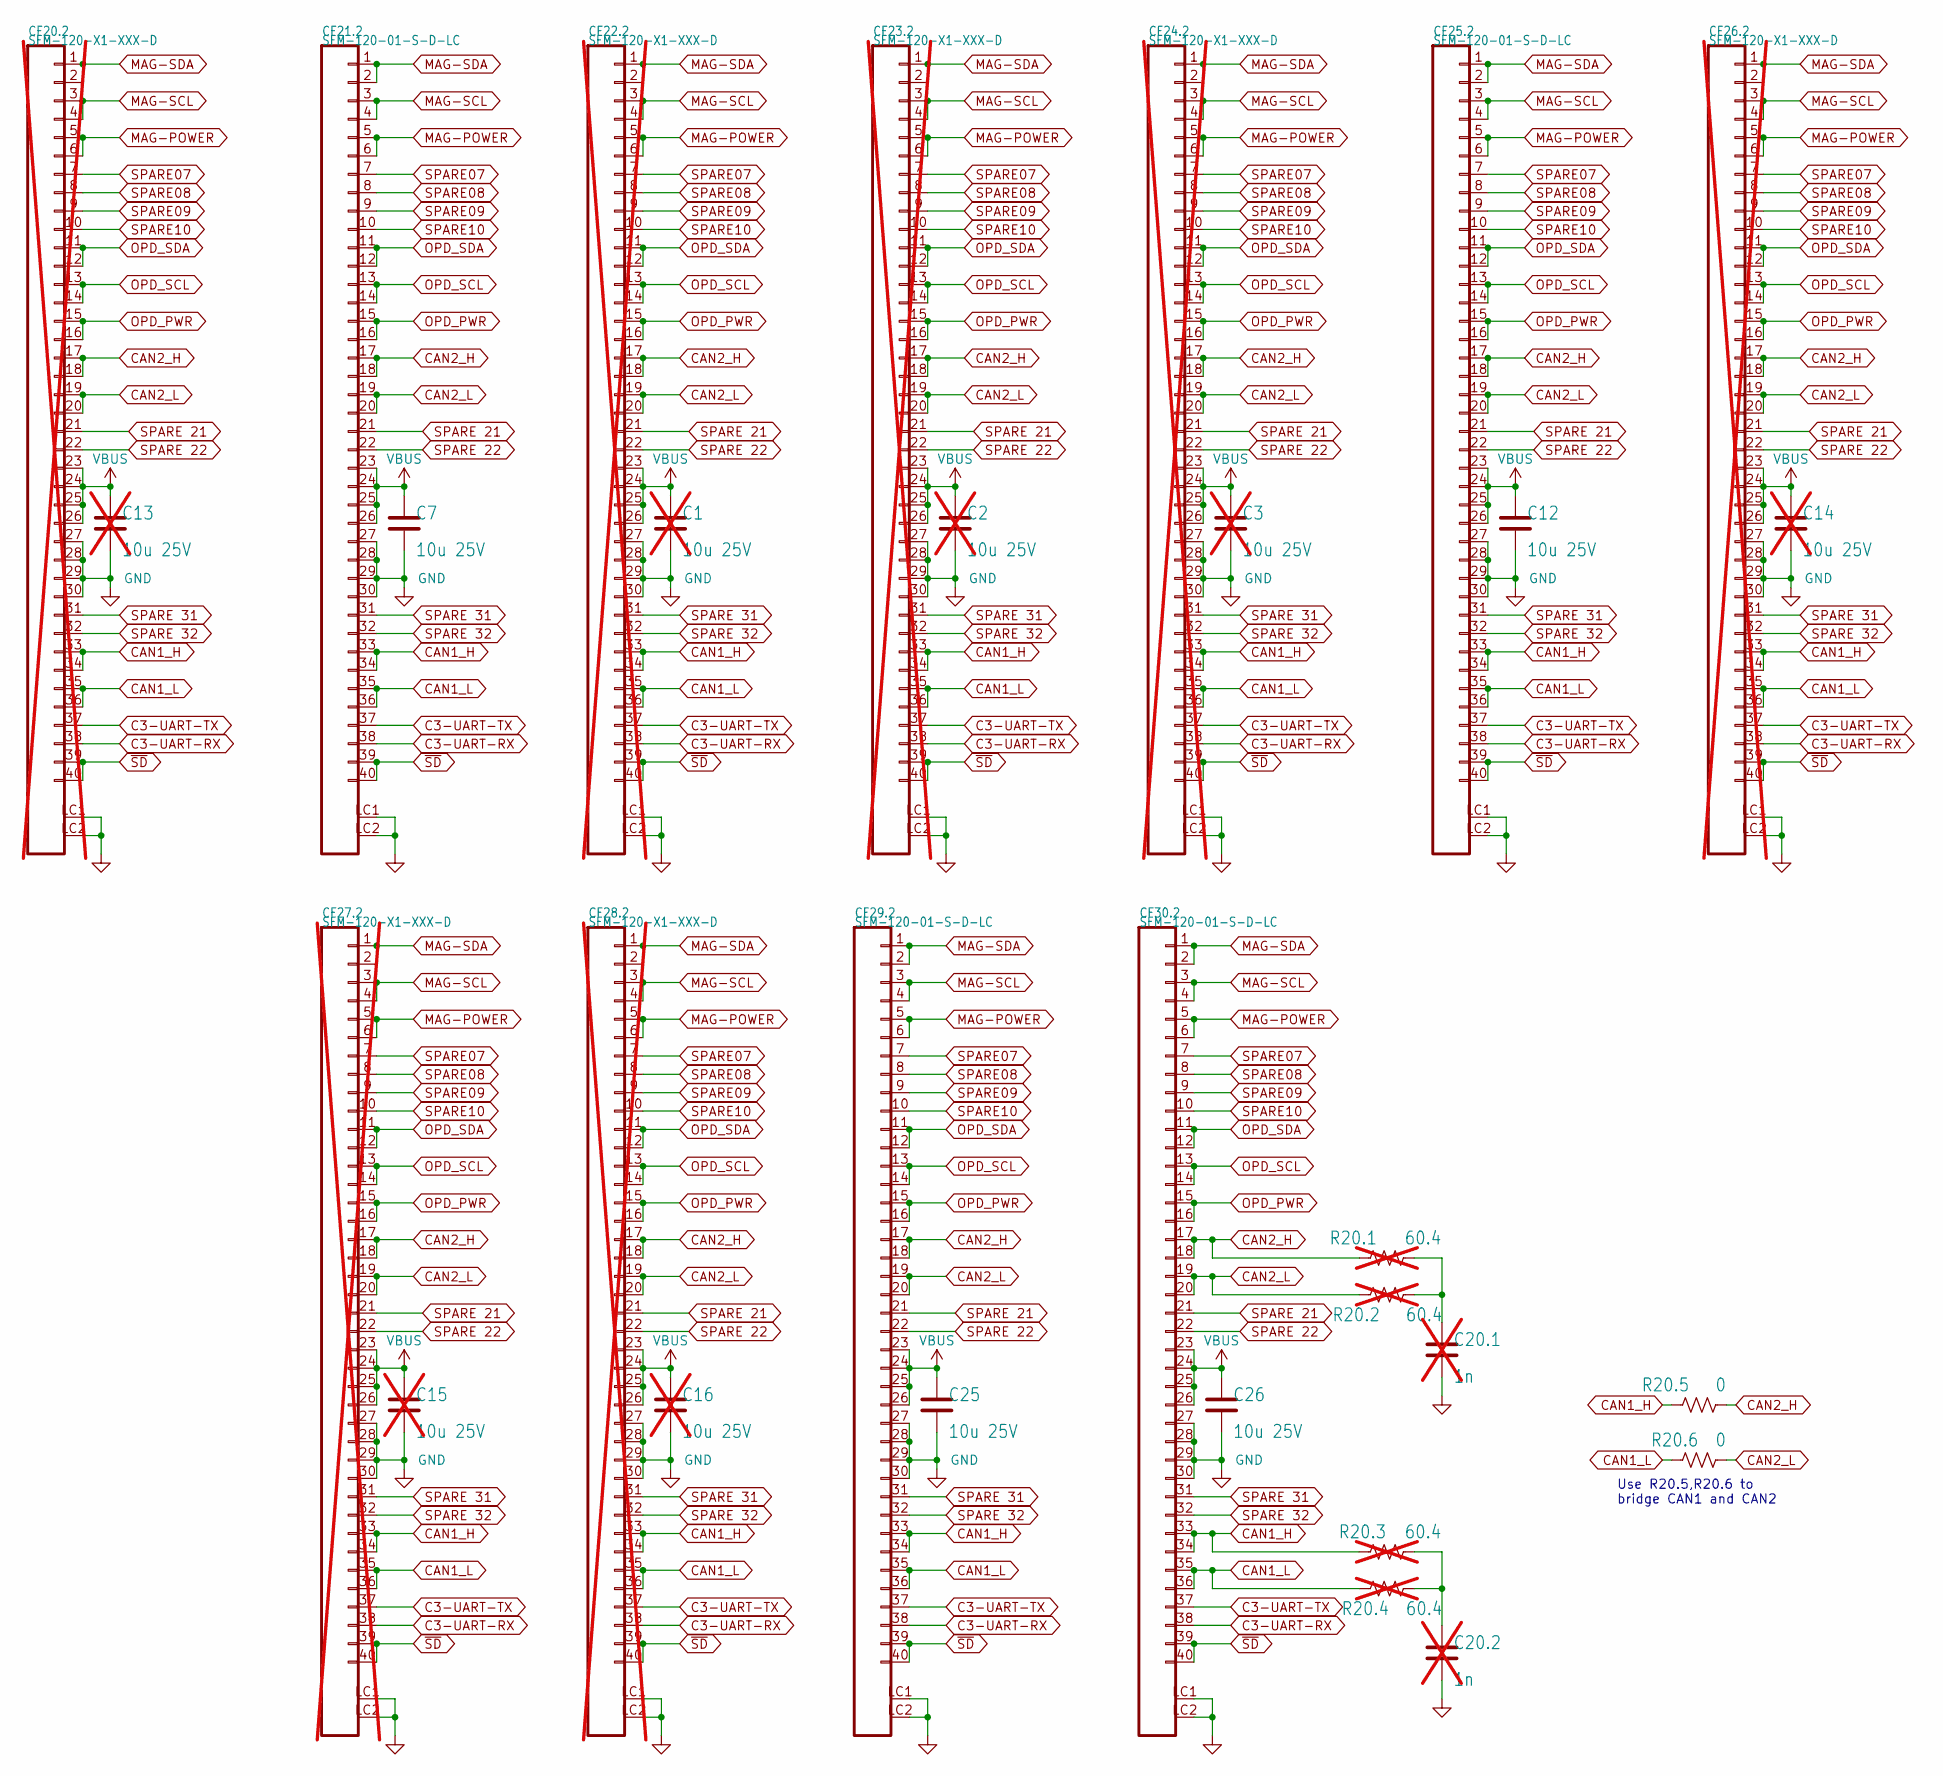
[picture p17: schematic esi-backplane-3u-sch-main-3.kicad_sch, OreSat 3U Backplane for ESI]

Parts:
C1, C2, C3, C13, C14, C15, C16: 10u 25V; C_1206_3216Metric; MPN TMK316AB7106KLHT; not fitted
C7, C12, C25, C26: 10u 25V; C_1206_3216Metric; MPN TMK316AB7106KLHT
C20.1, C20.2: 1n; 0603-C-NOSILK; MPN C0603C102J5GECAUTO; not fitted
CF20.2, CF22.2, CF23.2, CF24.2, CF26.2, CF27.2, CF28.2: SFM-120-X1-XXX-D; J-SAMTEC-SFM-120-X1-XXX-D; MPN SFM-120-01-S-D-LC; not fitted
CF21.2, CF25.2, CF29.2, CF30.2: SFM-120-01-S-D-LC; J-SAMTEC-SFM-120-X1-XXX-D; MPN SFM-120-01-S-D-LC
R20.1, R20.2, R20.3, R20.4: 60.4; R_1206_3216Metric; MPN RMCF1206FT60R4; not fitted
R20.5, R20.6: 0; 0603-C-NOSILK; MPN RMCF0603ZT0R00

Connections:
C3-UART-RX: CF20.2.38, CF21.2.38, CF22.2.38, CF23.2.38, CF24.2.38, CF25.2.38, CF26.2.38, CF27.2.38, CF28.2.38, CF29.2.38, CF30.2.38; also elsewhere on the board
C3-UART-TX: CF20.2.37, CF21.2.37, CF22.2.37, CF23.2.37, CF24.2.37, CF25.2.37, CF26.2.37, CF27.2.37, CF28.2.37, CF29.2.37, CF30.2.37; also elsewhere on the board
CAN1_H: CF20.2.33, CF20.2.34, CF21.2.33, CF21.2.34, CF22.2.33, CF22.2.34, CF23.2.33, CF23.2.34, CF24.2.33, CF24.2.34, CF25.2.33, CF25.2.34, CF26.2.33, CF26.2.34, CF27.2.33, CF27.2.34, CF28.2.33, CF28.2.34, CF29.2.33, CF29.2.34, CF30.2.33, CF30.2.34, R20.3.1, R20.5.1; also elsewhere on the board
CAN1_L: CF20.2.35, CF20.2.36, CF21.2.35, CF21.2.36, CF22.2.35, CF22.2.36, CF23.2.35, CF23.2.36, CF24.2.35, CF24.2.36, CF25.2.35, CF25.2.36, CF26.2.35, CF26.2.36, CF27.2.35, CF27.2.36, CF28.2.35, CF28.2.36, CF29.2.35, CF29.2.36, CF30.2.35, CF30.2.36, R20.4.2, R20.6.1; also elsewhere on the board
CAN2_H: CF20.2.17, CF20.2.18, CF21.2.17, CF21.2.18, CF22.2.17, CF22.2.18, CF23.2.17, CF23.2.18, CF24.2.17, CF24.2.18, CF25.2.17, CF25.2.18, CF26.2.17, CF26.2.18, CF27.2.17, CF27.2.18, CF28.2.17, CF28.2.18, CF29.2.17, CF29.2.18, CF30.2.17, CF30.2.18, R20.1.1, R20.5.2; also elsewhere on the board
CAN2_L: CF20.2.19, CF20.2.20, CF21.2.19, CF21.2.20, CF22.2.19, CF22.2.20, CF23.2.19, CF23.2.20, CF24.2.19, CF24.2.20, CF25.2.19, CF25.2.20, CF26.2.19, CF26.2.20, CF27.2.19, CF27.2.20, CF28.2.19, CF28.2.20, CF29.2.19, CF29.2.20, CF30.2.19, CF30.2.20, R20.2.2, R20.6.2; also elsewhere on the board
GND: C1.2, C2.2, C3.2, C7.2, C12.2, C13.2, C14.2, C15.2, C16.2, C20.1.2, C20.2.2, C25.2, C26.2, CF20.2.27, CF20.2.28, CF20.2.29, CF20.2.30, CF20.2.LC1, CF20.2.LC2, CF21.2.27, CF21.2.28, CF21.2.29, CF21.2.30, CF21.2.LC1, CF21.2.LC2, CF22.2.27, CF22.2.28, CF22.2.29, CF22.2.30, CF22.2.LC1, CF22.2.LC2, CF23.2.27, CF23.2.28, CF23.2.29, CF23.2.30, CF23.2.LC1, CF23.2.LC2, CF24.2.27, CF24.2.28, CF24.2.29, CF24.2.30, CF24.2.LC1, CF24.2.LC2, CF25.2.27, CF25.2.28, CF25.2.29, CF25.2.30, CF25.2.LC1, CF25.2.LC2, CF26.2.27, CF26.2.28, CF26.2.29, CF26.2.30, CF26.2.LC1, CF26.2.LC2, CF27.2.27, CF27.2.28, CF27.2.29, CF27.2.30, CF27.2.LC1, CF27.2.LC2, CF28.2.27, CF28.2.28, CF28.2.29, CF28.2.30, CF28.2.LC1, CF28.2.LC2, CF29.2.27, CF29.2.28, CF29.2.29, CF29.2.30, CF29.2.LC1, CF29.2.LC2, CF30.2.27, CF30.2.28, CF30.2.29, CF30.2.30, CF30.2.LC1, CF30.2.LC2; also elsewhere on the board
MAG-POWER: CF20.2.5, CF20.2.6, CF21.2.5, CF21.2.6, CF22.2.5, CF22.2.6, CF23.2.5, CF23.2.6, CF24.2.5, CF24.2.6, CF25.2.5, CF25.2.6, CF26.2.5, CF26.2.6, CF27.2.5, CF27.2.6, CF28.2.5, CF28.2.6, CF29.2.5, CF29.2.6, CF30.2.5, CF30.2.6; also elsewhere on the board
MAG-SCL: CF20.2.3, CF20.2.4, CF21.2.3, CF21.2.4, CF22.2.3, CF22.2.4, CF23.2.3, CF23.2.4, CF24.2.3, CF24.2.4, CF25.2.3, CF25.2.4, CF26.2.3, CF26.2.4, CF27.2.3, CF27.2.4, CF28.2.3, CF28.2.4, CF29.2.3, CF29.2.4, CF30.2.3, CF30.2.4; also elsewhere on the board
MAG-SDA: CF20.2.1, CF20.2.2, CF21.2.1, CF21.2.2, CF22.2.1, CF22.2.2, CF23.2.1, CF23.2.2, CF24.2.1, CF24.2.2, CF25.2.1, CF25.2.2, CF26.2.1, CF26.2.2, CF27.2.1, CF27.2.2, CF28.2.1, CF28.2.2, CF29.2.1, CF29.2.2, CF30.2.1, CF30.2.2; also elsewhere on the board
unnamed: C20.1.1, R20.1.2, R20.2.1
unnamed: C20.2.1, R20.3.2, R20.4.1
OPD_PWR: CF20.2.15, CF20.2.16, CF21.2.15, CF21.2.16, CF22.2.15, CF22.2.16, CF23.2.15, CF23.2.16, CF24.2.15, CF24.2.16, CF25.2.15, CF25.2.16, CF26.2.15, CF26.2.16, CF27.2.15, CF27.2.16, CF28.2.15, CF28.2.16, CF29.2.15, CF29.2.16, CF30.2.15, CF30.2.16; also elsewhere on the board
OPD_SCL: CF20.2.13, CF20.2.14, CF21.2.13, CF21.2.14, CF22.2.13, CF22.2.14, CF23.2.13, CF23.2.14, CF24.2.13, CF24.2.14, CF25.2.13, CF25.2.14, CF26.2.13, CF26.2.14, CF27.2.13, CF27.2.14, CF28.2.13, CF28.2.14, CF29.2.13, CF29.2.14, CF30.2.13, CF30.2.14; also elsewhere on the board
OPD_SDA: CF20.2.11, CF20.2.12, CF21.2.11, CF21.2.12, CF22.2.11, CF22.2.12, CF23.2.11, CF23.2.12, CF24.2.11, CF24.2.12, CF25.2.11, CF25.2.12, CF26.2.11, CF26.2.12, CF27.2.11, CF27.2.12, CF28.2.11, CF28.2.12, CF29.2.11, CF29.2.12, CF30.2.11, CF30.2.12; also elsewhere on the board
SPARE07: CF20.2.7, CF21.2.7, CF22.2.7, CF23.2.7, CF24.2.7, CF25.2.7, CF26.2.7, CF27.2.7, CF28.2.7, CF29.2.7, CF30.2.7; also elsewhere on the board
SPARE08: CF20.2.8, CF21.2.8, CF22.2.8, CF23.2.8, CF24.2.8, CF25.2.8, CF26.2.8, CF27.2.8, CF28.2.8, CF29.2.8, CF30.2.8; also elsewhere on the board
SPARE09: CF20.2.9, CF21.2.9, CF22.2.9, CF23.2.9, CF24.2.9, CF25.2.9, CF26.2.9, CF27.2.9, CF28.2.9, CF29.2.9, CF30.2.9; also elsewhere on the board
SPARE10: CF20.2.10, CF21.2.10, CF22.2.10, CF23.2.10, CF24.2.10, CF25.2.10, CF26.2.10, CF27.2.10, CF28.2.10, CF29.2.10, CF30.2.10; also elsewhere on the board
SPARE 21: CF20.2.21, CF21.2.21, CF22.2.21, CF23.2.21, CF24.2.21, CF25.2.21, CF26.2.21, CF27.2.21, CF28.2.21, CF29.2.21, CF30.2.21; also elsewhere on the board
SPARE 22: CF20.2.22, CF21.2.22, CF22.2.22, CF23.2.22, CF24.2.22, CF25.2.22, CF26.2.22, CF27.2.22, CF28.2.22, CF29.2.22, CF30.2.22; also elsewhere on the board
SPARE 31: CF20.2.31, CF21.2.31, CF22.2.31, CF23.2.31, CF24.2.31, CF25.2.31, CF26.2.31, CF27.2.31, CF28.2.31, CF29.2.31, CF30.2.31; also elsewhere on the board
SPARE 32: CF20.2.32, CF21.2.32, CF22.2.32, CF23.2.32, CF24.2.32, CF25.2.32, CF26.2.32, CF27.2.32, CF28.2.32, CF29.2.32, CF30.2.32; also elsewhere on the board
VBUS: C1.1, C2.1, C3.1, C7.1, C12.1, C13.1, C14.1, C15.1, C16.1, C25.1, C26.1, CF20.2.23, CF20.2.24, CF20.2.25, CF20.2.26, CF21.2.23, CF21.2.24, CF21.2.25, CF21.2.26, CF22.2.23, CF22.2.24, CF22.2.25, CF22.2.26, CF23.2.23, CF23.2.24, CF23.2.25, CF23.2.26, CF24.2.23, CF24.2.24, CF24.2.25, CF24.2.26, CF25.2.23, CF25.2.24, CF25.2.25, CF25.2.26, CF26.2.23, CF26.2.24, CF26.2.25, CF26.2.26, CF27.2.23, CF27.2.24, CF27.2.25, CF27.2.26, CF28.2.23, CF28.2.24, CF28.2.25, CF28.2.26, CF29.2.23, CF29.2.24, CF29.2.25, CF29.2.26, CF30.2.23, CF30.2.24, CF30.2.25, CF30.2.26; also elsewhere on the board
~SD: CF20.2.39, CF20.2.40, CF21.2.39, CF21.2.40, CF22.2.39, CF22.2.40, CF23.2.39, CF23.2.40, CF24.2.39, CF24.2.40, CF25.2.39, CF25.2.40, CF26.2.39, CF26.2.40, CF27.2.39, CF27.2.40, CF28.2.39, CF28.2.40, CF29.2.39, CF29.2.40, CF30.2.39, CF30.2.40; also elsewhere on the board

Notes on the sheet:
Use R20.5,R20.6 to bridge CAN1 and CAN2


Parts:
C6, C19, C22: 10u 25V; C_1206_3216Metric; MPN TMK316AB7106KLHT
C20, C27, C28, C29, C30: 10u 25V; C_1206_3216Metric; MPN TMK316AB7106KLHT; not fitted
CF12.2, CF14.2, CF15.2, CF16.2, CF17.2: SFM-120-X1-XXX-D; J-SAMTEC-SFM-120-X1-XXX-D; MPN SFM-120-01-S-D-LC; not fitted
CF13.2, CF18.2, CF19.2: SFM-120-01-S-D-LC; J-SAMTEC-SFM-120-X1-XXX-D; MPN SFM-120-01-S-D-LC

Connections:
C3-UART-RX: CF12.2.38, CF13.2.38, CF14.2.38, CF15.2.38, CF16.2.38, CF17.2.38, CF18.2.38, CF19.2.38; also elsewhere on the board
C3-UART-TX: CF12.2.37, CF13.2.37, CF14.2.37, CF15.2.37, CF16.2.37, CF17.2.37, CF18.2.37, CF19.2.37; also elsewhere on the board
CAN1_H: CF12.2.33, CF12.2.34, CF13.2.33, CF13.2.34, CF14.2.33, CF14.2.34, CF15.2.33, CF15.2.34, CF16.2.33, CF16.2.34, CF17.2.33, CF17.2.34, CF18.2.33, CF18.2.34, CF19.2.33, CF19.2.34; also elsewhere on the board
CAN1_L: CF12.2.35, CF12.2.36, CF13.2.35, CF13.2.36, CF14.2.35, CF14.2.36, CF15.2.35, CF15.2.36, CF16.2.35, CF16.2.36, CF17.2.35, CF17.2.36, CF18.2.35, CF18.2.36, CF19.2.35, CF19.2.36; also elsewhere on the board
CAN2_H: CF12.2.17, CF12.2.18, CF13.2.17, CF13.2.18, CF14.2.17, CF14.2.18, CF15.2.17, CF15.2.18, CF16.2.17, CF16.2.18, CF17.2.17, CF17.2.18, CF18.2.17, CF18.2.18, CF19.2.17, CF19.2.18; also elsewhere on the board
CAN2_L: CF12.2.19, CF12.2.20, CF13.2.19, CF13.2.20, CF14.2.19, CF14.2.20, CF15.2.19, CF15.2.20, CF16.2.19, CF16.2.20, CF17.2.19, CF17.2.20, CF18.2.19, CF18.2.20, CF19.2.19, CF19.2.20; also elsewhere on the board
GND: C6.2, C19.2, C20.2, C22.2, C27.2, C28.2, C29.2, C30.2, CF12.2.27, CF12.2.28, CF12.2.29, CF12.2.30, CF12.2.LC1, CF12.2.LC2, CF13.2.27, CF13.2.28, CF13.2.29, CF13.2.30, CF13.2.LC1, CF13.2.LC2, CF14.2.27, CF14.2.28, CF14.2.29, CF14.2.30, CF14.2.LC1, CF14.2.LC2, CF15.2.27, CF15.2.28, CF15.2.29, CF15.2.30, CF15.2.LC1, CF15.2.LC2, CF16.2.27, CF16.2.28, CF16.2.29, CF16.2.30, CF16.2.LC1, CF16.2.LC2, CF17.2.27, CF17.2.28, CF17.2.29, CF17.2.30, CF17.2.LC1, CF17.2.LC2, CF18.2.27, CF18.2.28, CF18.2.29, CF18.2.30, CF18.2.LC1, CF18.2.LC2, CF19.2.27, CF19.2.28, CF19.2.29, CF19.2.30, CF19.2.LC1, CF19.2.LC2; also elsewhere on the board
MAG-POWER: CF12.2.5, CF12.2.6, CF13.2.5, CF13.2.6, CF14.2.5, CF14.2.6, CF15.2.5, CF15.2.6, CF16.2.5, CF16.2.6, CF17.2.5, CF17.2.6, CF18.2.5, CF18.2.6, CF19.2.5, CF19.2.6; also elsewhere on the board
MAG-SCL: CF12.2.3, CF12.2.4, CF13.2.3, CF13.2.4, CF14.2.3, CF14.2.4, CF15.2.3, CF15.2.4, CF16.2.3, CF16.2.4, CF17.2.3, CF17.2.4, CF18.2.3, CF18.2.4, CF19.2.3, CF19.2.4; also elsewhere on the board
MAG-SDA: CF12.2.1, CF12.2.2, CF13.2.1, CF13.2.2, CF14.2.1, CF14.2.2, CF15.2.1, CF15.2.2, CF16.2.1, CF16.2.2, CF17.2.1, CF17.2.2, CF18.2.1, CF18.2.2, CF19.2.1, CF19.2.2; also elsewhere on the board
OPD_PWR: CF12.2.15, CF12.2.16, CF13.2.15, CF13.2.16, CF14.2.15, CF14.2.16, CF15.2.15, CF15.2.16, CF16.2.15, CF16.2.16, CF17.2.15, CF17.2.16, CF18.2.15, CF18.2.16, CF19.2.15, CF19.2.16; also elsewhere on the board
OPD_SCL: CF12.2.13, CF12.2.14, CF13.2.13, CF13.2.14, CF14.2.13, CF14.2.14, CF15.2.13, CF15.2.14, CF16.2.13, CF16.2.14, CF17.2.13, CF17.2.14, CF18.2.13, CF18.2.14, CF19.2.13, CF19.2.14; also elsewhere on the board
OPD_SDA: CF12.2.11, CF12.2.12, CF13.2.11, CF13.2.12, CF14.2.11, CF14.2.12, CF15.2.11, CF15.2.12, CF16.2.11, CF16.2.12, CF17.2.11, CF17.2.12, CF18.2.11, CF18.2.12, CF19.2.11, CF19.2.12; also elsewhere on the board
SPARE07: CF12.2.7, CF13.2.7, CF14.2.7, CF15.2.7, CF16.2.7, CF17.2.7, CF18.2.7, CF19.2.7; also elsewhere on the board
SPARE08: CF12.2.8, CF13.2.8, CF14.2.8, CF15.2.8, CF16.2.8, CF17.2.8, CF18.2.8, CF19.2.8; also elsewhere on the board
SPARE09: CF12.2.9, CF13.2.9, CF14.2.9, CF15.2.9, CF16.2.9, CF17.2.9, CF18.2.9, CF19.2.9; also elsewhere on the board
SPARE10: CF12.2.10, CF13.2.10, CF14.2.10, CF15.2.10, CF16.2.10, CF17.2.10, CF18.2.10, CF19.2.10; also elsewhere on the board
SPARE 21: CF12.2.21, CF13.2.21, CF14.2.21, CF15.2.21, CF16.2.21, CF17.2.21, CF18.2.21, CF19.2.21; also elsewhere on the board
SPARE 22: CF12.2.22, CF13.2.22, CF14.2.22, CF15.2.22, CF16.2.22, CF17.2.22, CF18.2.22, CF19.2.22; also elsewhere on the board
SPARE 31: CF12.2.31, CF13.2.31, CF14.2.31, CF15.2.31, CF16.2.31, CF17.2.31, CF18.2.31, CF19.2.31; also elsewhere on the board
SPARE 32: CF12.2.32, CF13.2.32, CF14.2.32, CF15.2.32, CF16.2.32, CF17.2.32, CF18.2.32, CF19.2.32; also elsewhere on the board
VBUS: C6.1, C19.1, C20.1, C22.1, C27.1, C28.1, C29.1, C30.1, CF12.2.23, CF12.2.24, CF12.2.25, CF12.2.26, CF13.2.23, CF13.2.24, CF13.2.25, CF13.2.26, CF14.2.23, CF14.2.24, CF14.2.25, CF14.2.26, CF15.2.23, CF15.2.24, CF15.2.25, CF15.2.26, CF16.2.23, CF16.2.24, CF16.2.25, CF16.2.26, CF17.2.23, CF17.2.24, CF17.2.25, CF17.2.26, CF18.2.23, CF18.2.24, CF18.2.25, CF18.2.26, CF19.2.23, CF19.2.24, CF19.2.25, CF19.2.26; also elsewhere on the board
~SD: CF12.2.39, CF12.2.40, CF13.2.39, CF13.2.40, CF14.2.39, CF14.2.40, CF15.2.39, CF15.2.40, CF16.2.39, CF16.2.40, CF17.2.39, CF17.2.40, CF18.2.39, CF18.2.40, CF19.2.39, CF19.2.40; also elsewhere on the board

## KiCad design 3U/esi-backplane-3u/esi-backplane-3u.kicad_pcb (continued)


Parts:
CM1.1, CM1.11, CM1.30, CM2.4, CM3.30, CM.3.3: 0733000110; J-MOLEX-SMPM-73300-011X; MPN 0733000110

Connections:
GND: CM1.1.2 (Ext), CM1.11.2 (Ext), CM1.30.2 (Ext), CM2.4.2 (Ext), CM3.30.2 (Ext), CM.3.3.2 (Ext); also elsewhere on the board
RF-GPS-L1: CM1.30.1 (In), CM2.4.1 (In)
RF-S-BAND: CM1.1.1 (In), CM1.11.1 (In)
RF-UHF: CM3.30.1 (In), CM.3.3.1 (In)



Board: 4 copper layers, 82.5 x 327.0 mm, 101 parts (34 on the bottom side), 30 nets.

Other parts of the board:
PH1, PH2: MountingHole_3mm

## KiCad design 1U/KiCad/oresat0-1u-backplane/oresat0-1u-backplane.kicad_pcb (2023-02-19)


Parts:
C3, C4: 1n; .0603-C-NOSILK
R5, R6, R7, R8: NP/60.4; 1206-C
R9, R10: 0; .0603-B-NOSILK

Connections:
CAN1_H: R5.1, R10.1; also elsewhere on the board
CAN1_L: R6.1, R9.1; also elsewhere on the board
CAN2_H: R7.1, R10.2; also elsewhere on the board
CAN2_L: R8.1, R9.2; also elsewhere on the board
GND: C3.2, C4.2; also elsewhere on the board
unnamed: C3.1, R5.2, R6.2
unnamed: C4.1, R7.2, R8.2

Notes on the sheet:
NP: CAN 1/2 independent 0 Ohm: CAN 1 = 2 (remove 60 ohms)


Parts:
C11: 10u 25V; 1206-B
CF7.2: SFM-120-X1-XXX-D

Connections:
C3-UART-RX: CF7.2.38; also elsewhere on the board
C3-UART-TX: CF7.2.37; also elsewhere on the board
CAN1_H: CF7.2.33, CF7.2.34; also elsewhere on the board
CAN1_L: CF7.2.35, CF7.2.36; also elsewhere on the board
CAN2_H: CF7.2.17, CF7.2.18; also elsewhere on the board
CAN2_L: CF7.2.19, CF7.2.20; also elsewhere on the board
GND: C11.2, CF7.2.27, CF7.2.28, CF7.2.29, CF7.2.30, CF7.2.LC1, CF7.2.LC2; also elsewhere on the board
OPD_PWR: CF7.2.15, CF7.2.16; also elsewhere on the board
OPD_SCL: CF7.2.13, CF7.2.14; also elsewhere on the board
OPD_SDA: CF7.2.11, CF7.2.12; also elsewhere on the board
SPARE1-MAG-SDA: CF7.2.1, CF7.2.2; also elsewhere on the board
SPARE3-MAG-SCL: CF7.2.3; also elsewhere on the board
SPARE4-MAG-SCL: CF7.2.4; also elsewhere on the board
SPARE5-MAG-POWER: CF7.2.5; also elsewhere on the board
SPARE6-MAG-POWER: CF7.2.6; also elsewhere on the board
SPARE7: CF7.2.7; also elsewhere on the board
SPARE8: CF7.2.8; also elsewhere on the board
SPARE9-TURNSTILE-DEPLOY: CF7.2.9; also elsewhere on the board
SPARE10-TURNSTILE-DEPLOY: CF7.2.10; also elsewhere on the board
SPARE21: CF7.2.21; also elsewhere on the board
SPARE22: CF7.2.22; also elsewhere on the board
SPARE31: CF7.2.31; also elsewhere on the board
SPARE32: CF7.2.32; also elsewhere on the board
VBUS: C11.1, CF7.2.23, CF7.2.24, CF7.2.25, CF7.2.26; also elsewhere on the board
~SD: CF7.2.39, CF7.2.40; also elsewhere on the board


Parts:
C9: 10u 25V; 1206-B
CF5.2: SFM-120-X1-XXX-D
J2: M55-6001642R; CONN_M55-6001642R_HRW

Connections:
C3-UART-RX: CF5.2.38, J2.2; also elsewhere on the board
C3-UART-TX: CF5.2.37, J2.3; also elsewhere on the board
CAN1_H: CF5.2.33, CF5.2.34, J2.5; also elsewhere on the board
CAN1_L: CF5.2.35, CF5.2.36, J2.4; also elsewhere on the board
CAN2_H: CF5.2.17, CF5.2.18, J2.13; also elsewhere on the board
CAN2_L: CF5.2.19, CF5.2.20, J2.12; also elsewhere on the board
GND: C9.2, CF5.2.27, CF5.2.28, CF5.2.29, CF5.2.30, CF5.2.LC1, CF5.2.LC2, J2.6, J2.8, J2.10, J2.19 (17), J2.20 (17), J2.21 (17), J2.22 (17); also elsewhere on the board
OPD_PWR: CF5.2.15, CF5.2.16, J2.14; also elsewhere on the board
OPD_SCL: CF5.2.13, CF5.2.14, J2.15; also elsewhere on the board
OPD_SDA: CF5.2.11, CF5.2.12, J2.16; also elsewhere on the board
SPARE1-MAG-SDA: CF5.2.1, CF5.2.2; also elsewhere on the board
SPARE3-MAG-SCL: CF5.2.3; also elsewhere on the board
SPARE4-MAG-SCL: CF5.2.4; also elsewhere on the board
SPARE5-MAG-POWER: CF5.2.5; also elsewhere on the board
SPARE6-MAG-POWER: CF5.2.6; also elsewhere on the board
SPARE7: CF5.2.7; also elsewhere on the board
SPARE8: CF5.2.8; also elsewhere on the board
SPARE9-TURNSTILE-DEPLOY: CF5.2.9; also elsewhere on the board
SPARE10-TURNSTILE-DEPLOY: CF5.2.10; also elsewhere on the board
SPARE21: CF5.2.21; also elsewhere on the board
SPARE22: CF5.2.22; also elsewhere on the board
SPARE31: CF5.2.31; also elsewhere on the board
SPARE32: CF5.2.32; also elsewhere on the board
VBUS: C9.1, CF5.2.23, CF5.2.24, CF5.2.25, CF5.2.26, J2.7, J2.9, J2.11; also elsewhere on the board
~SD: CF5.2.39, CF5.2.40, J2.1; also elsewhere on the board

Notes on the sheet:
DEBUG CONNECTOR


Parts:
CM8: U.FL-R-SMA; U.FL-R-SMT
J1: 5-104196-5

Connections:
GND: CM8.2, CM8.3, J1.HD1 (HD), J1.HD2 (HD), J1.HD3 (HD); also elsewhere on the board
S-PATCH: CM8.1; also elsewhere on the board
SPARE1-MAG-SDA: J1.19, J1.20; also elsewhere on the board
SPARE3-MAG-SCL: J1.18; also elsewhere on the board
SPARE4-MAG-SCL: J1.17; also elsewhere on the board
SPARE5-MAG-POWER: J1.16; also elsewhere on the board
SPARE6-MAG-POWER: J1.15; also elsewhere on the board
SPARE7: J1.14; also elsewhere on the board
SPARE8: J1.13; also elsewhere on the board
SPARE9-TURNSTILE-DEPLOY: J1.12; also elsewhere on the board
SPARE10-TURNSTILE-DEPLOY: J1.11; also elsewhere on the board

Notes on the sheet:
-Z End Cap Connector


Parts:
C1, C2: 1n; .0603-C-NOSILK
C5: 10u 25V; 1206-B
CF1.2: SFM-120-X1-XXX-D
CM1.1, CM1.2, CM1.3: J-MOLEX-SMPM-73300-0111X; J-MOLEX-SMPM-73300-0111X-long
FIDUCIAL1, FIDUCIAL2, FIDUCIAL3: FIDUCIAL-1.0X2.0
R1, R2, R3, R4: 60.4; 1206-C
U$1: FLIGHMARKERNEW; FLIGHTMARKER_NEW_BOARDS

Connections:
C3-UART-RX: CF1.2.38; also elsewhere on the board
C3-UART-TX: CF1.2.37; also elsewhere on the board
CAN1_H: CF1.2.33, CF1.2.34, R1.1; also elsewhere on the board
CAN1_L: CF1.2.35, CF1.2.36, R2.1; also elsewhere on the board
CAN2_H: CF1.2.17, CF1.2.18, R3.1; also elsewhere on the board
CAN2_L: CF1.2.19, CF1.2.20, R4.1; also elsewhere on the board
GND: C1.2, C2.2, C5.2, CF1.2.27, CF1.2.28, CF1.2.29, CF1.2.30, CF1.2.LC1, CF1.2.LC2, CM1.1.GND (SHIELD1), CM1.2.GND (SHIELD1), CM1.3.GND (SHIELD1); also elsewhere on the board
L1-TURNSTILE: CM1.1.RF-DOWN (RF); also elsewhere on the board
L-TURNSTILE: CM1.2.RF-DOWN (RF); also elsewhere on the board
unnamed: C1.1, R1.2, R2.2
unnamed: C2.1, R3.2, R4.2
OPD_PWR: CF1.2.15, CF1.2.16; also elsewhere on the board
OPD_SCL: CF1.2.13, CF1.2.14; also elsewhere on the board
OPD_SDA: CF1.2.11, CF1.2.12; also elsewhere on the board
SPARE1-MAG-SDA: CF1.2.1, CF1.2.2; also elsewhere on the board
SPARE3-MAG-SCL: CF1.2.3; also elsewhere on the board
SPARE4-MAG-SCL: CF1.2.4; also elsewhere on the board
SPARE5-MAG-POWER: CF1.2.5; also elsewhere on the board
SPARE6-MAG-POWER: CF1.2.6; also elsewhere on the board
SPARE7: CF1.2.7; also elsewhere on the board
SPARE8: CF1.2.8; also elsewhere on the board
SPARE9-TURNSTILE-DEPLOY: CF1.2.9; also elsewhere on the board
SPARE10-TURNSTILE-DEPLOY: CF1.2.10; also elsewhere on the board
SPARE21: CF1.2.21; also elsewhere on the board
SPARE22: CF1.2.22; also elsewhere on the board
SPARE31: CF1.2.31; also elsewhere on the board
SPARE32: CF1.2.32; also elsewhere on the board
UHF-TURNSTILE: CM1.3.RF-DOWN (RF); also elsewhere on the board
VBUS: C5.1, CF1.2.23, CF1.2.24, CF1.2.25, CF1.2.26; also elsewhere on the board
~SD: CF1.2.39, CF1.2.40; also elsewhere on the board

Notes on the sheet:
OreSat0 1U backplane v2.0
NOTE: See Slot 8 for CAN 1/2 information.
v2.0


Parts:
C8: 10u 25V; 1206-B
CF4.2: SFM-120-X1-XXX-D
CM4.1: J-MOLEX-SMPM-73300-0111X; J-MOLEX-SMPM-73300-0111X-long

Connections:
C3-UART-RX: CF4.2.38; also elsewhere on the board
C3-UART-TX: CF4.2.37; also elsewhere on the board
CAN1_H: CF4.2.33, CF4.2.34; also elsewhere on the board
CAN1_L: CF4.2.35, CF4.2.36; also elsewhere on the board
CAN2_H: CF4.2.17, CF4.2.18; also elsewhere on the board
CAN2_L: CF4.2.19, CF4.2.20; also elsewhere on the board
GND: C8.2, CF4.2.27, CF4.2.28, CF4.2.29, CF4.2.30, CF4.2.LC1, CF4.2.LC2, CM4.1.GND (SHIELD1); also elsewhere on the board
OPD_PWR: CF4.2.15, CF4.2.16; also elsewhere on the board
OPD_SCL: CF4.2.13, CF4.2.14; also elsewhere on the board
OPD_SDA: CF4.2.11, CF4.2.12; also elsewhere on the board
S-PATCH: CM4.1.RF-DOWN (RF); also elsewhere on the board
SPARE1-MAG-SDA: CF4.2.1, CF4.2.2; also elsewhere on the board
SPARE3-MAG-SCL: CF4.2.3; also elsewhere on the board
SPARE4-MAG-SCL: CF4.2.4; also elsewhere on the board
SPARE5-MAG-POWER: CF4.2.5; also elsewhere on the board
SPARE6-MAG-POWER: CF4.2.6; also elsewhere on the board
SPARE7: CF4.2.7; also elsewhere on the board
SPARE8: CF4.2.8; also elsewhere on the board
SPARE9-TURNSTILE-DEPLOY: CF4.2.9; also elsewhere on the board
SPARE10-TURNSTILE-DEPLOY: CF4.2.10; also elsewhere on the board
SPARE21: CF4.2.21; also elsewhere on the board
SPARE22: CF4.2.22; also elsewhere on the board
SPARE31: CF4.2.31; also elsewhere on the board
SPARE32: CF4.2.32; also elsewhere on the board
VBUS: C8.1, CF4.2.23, CF4.2.24, CF4.2.25, CF4.2.26; also elsewhere on the board
~SD: CF4.2.39, CF4.2.40; also elsewhere on the board

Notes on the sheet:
NOTE: See Slot 8 for CAN 1/2 information.

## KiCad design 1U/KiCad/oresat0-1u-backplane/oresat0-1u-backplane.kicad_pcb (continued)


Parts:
C7: 10u 25V; 1206-B
CF3.2: SFM-120-X1-XXX-D
CM3.2: J-MOLEX-SMPM-73300-0111X; J-MOLEX-SMPM-73300-0111X-long

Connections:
C3-UART-RX: CF3.2.38; also elsewhere on the board
C3-UART-TX: CF3.2.37; also elsewhere on the board
CAN1_H: CF3.2.33, CF3.2.34; also elsewhere on the board
CAN1_L: CF3.2.35, CF3.2.36; also elsewhere on the board
CAN2_H: CF3.2.17, CF3.2.18; also elsewhere on the board
CAN2_L: CF3.2.19, CF3.2.20; also elsewhere on the board
GND: C7.2, CF3.2.27, CF3.2.28, CF3.2.29, CF3.2.30, CF3.2.LC1, CF3.2.LC2, CM3.2.GND (SHIELD1); also elsewhere on the board
L1-TURNSTILE: CM3.2.RF-DOWN (RF); also elsewhere on the board
OPD_PWR: CF3.2.15, CF3.2.16; also elsewhere on the board
OPD_SCL: CF3.2.13, CF3.2.14; also elsewhere on the board
OPD_SDA: CF3.2.11, CF3.2.12; also elsewhere on the board
SPARE1-MAG-SDA: CF3.2.1, CF3.2.2; also elsewhere on the board
SPARE3-MAG-SCL: CF3.2.3; also elsewhere on the board
SPARE4-MAG-SCL: CF3.2.4; also elsewhere on the board
SPARE5-MAG-POWER: CF3.2.5; also elsewhere on the board
SPARE6-MAG-POWER: CF3.2.6; also elsewhere on the board
SPARE7: CF3.2.7; also elsewhere on the board
SPARE8: CF3.2.8; also elsewhere on the board
SPARE9-TURNSTILE-DEPLOY: CF3.2.9; also elsewhere on the board
SPARE10-TURNSTILE-DEPLOY: CF3.2.10; also elsewhere on the board
SPARE21: CF3.2.21; also elsewhere on the board
SPARE22: CF3.2.22; also elsewhere on the board
SPARE31: CF3.2.31; also elsewhere on the board
SPARE32: CF3.2.32; also elsewhere on the board
VBUS: C7.1, CF3.2.23, CF3.2.24, CF3.2.25, CF3.2.26; also elsewhere on the board
~SD: CF3.2.39, CF3.2.40; also elsewhere on the board


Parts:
C6: 10u 25V; 1206-B
CF2.2: SFM-120-X1-XXX-D
CM2.2, CM2.3: J-MOLEX-SMPM-73300-0111X; J-MOLEX-SMPM-73300-0111X-long

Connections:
C3-UART-RX: CF2.2.38; also elsewhere on the board
C3-UART-TX: CF2.2.37; also elsewhere on the board
CAN1_H: CF2.2.33, CF2.2.34; also elsewhere on the board
CAN1_L: CF2.2.35, CF2.2.36; also elsewhere on the board
CAN2_H: CF2.2.17, CF2.2.18; also elsewhere on the board
CAN2_L: CF2.2.19, CF2.2.20; also elsewhere on the board
GND: C6.2, CF2.2.27, CF2.2.28, CF2.2.29, CF2.2.30, CF2.2.LC1, CF2.2.LC2, CM2.2.GND (SHIELD1), CM2.3.GND (SHIELD1); also elsewhere on the board
L-TURNSTILE: CM2.2.RF-DOWN (RF); also elsewhere on the board
OPD_PWR: CF2.2.15, CF2.2.16; also elsewhere on the board
OPD_SCL: CF2.2.13, CF2.2.14; also elsewhere on the board
OPD_SDA: CF2.2.11, CF2.2.12; also elsewhere on the board
SPARE1-MAG-SDA: CF2.2.1, CF2.2.2; also elsewhere on the board
SPARE3-MAG-SCL: CF2.2.3; also elsewhere on the board
SPARE4-MAG-SCL: CF2.2.4; also elsewhere on the board
SPARE5-MAG-POWER: CF2.2.5; also elsewhere on the board
SPARE6-MAG-POWER: CF2.2.6; also elsewhere on the board
SPARE7: CF2.2.7; also elsewhere on the board
SPARE8: CF2.2.8; also elsewhere on the board
SPARE9-TURNSTILE-DEPLOY: CF2.2.9; also elsewhere on the board
SPARE10-TURNSTILE-DEPLOY: CF2.2.10; also elsewhere on the board
SPARE21: CF2.2.21; also elsewhere on the board
SPARE22: CF2.2.22; also elsewhere on the board
SPARE31: CF2.2.31; also elsewhere on the board
SPARE32: CF2.2.32; also elsewhere on the board
UHF-TURNSTILE: CM2.3.RF-DOWN (RF); also elsewhere on the board
VBUS: C6.1, CF2.2.23, CF2.2.24, CF2.2.25, CF2.2.26; also elsewhere on the board
~SD: CF2.2.39, CF2.2.40; also elsewhere on the board

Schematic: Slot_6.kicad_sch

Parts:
C10: 10u 25V; 1206-B
CF6.2: SFM-120-X1-XXX-D

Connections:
C3-UART-RX: CF6.2.38; also elsewhere on the board
C3-UART-TX: CF6.2.37; also elsewhere on the board
CAN1_H: CF6.2.33, CF6.2.34; also elsewhere on the board
CAN1_L: CF6.2.35, CF6.2.36; also elsewhere on the board
CAN2_H: CF6.2.17, CF6.2.18; also elsewhere on the board
CAN2_L: CF6.2.19, CF6.2.20; also elsewhere on the board
GND: C10.2, CF6.2.27, CF6.2.28, CF6.2.29, CF6.2.30, CF6.2.LC1, CF6.2.LC2; also elsewhere on the board
OPD_PWR: CF6.2.15, CF6.2.16; also elsewhere on the board
OPD_SCL: CF6.2.13, CF6.2.14; also elsewhere on the board
OPD_SDA: CF6.2.11, CF6.2.12; also elsewhere on the board
SPARE1-MAG-SDA: CF6.2.1, CF6.2.2; also elsewhere on the board
SPARE3-MAG-SCL: CF6.2.3; also elsewhere on the board
SPARE4-MAG-SCL: CF6.2.4; also elsewhere on the board
SPARE5-MAG-POWER: CF6.2.5; also elsewhere on the board
SPARE6-MAG-POWER: CF6.2.6; also elsewhere on the board
SPARE7: CF6.2.7; also elsewhere on the board
SPARE8: CF6.2.8; also elsewhere on the board
SPARE9-TURNSTILE-DEPLOY: CF6.2.9; also elsewhere on the board
SPARE10-TURNSTILE-DEPLOY: CF6.2.10; also elsewhere on the board
SPARE21: CF6.2.21; also elsewhere on the board
SPARE22: CF6.2.22; also elsewhere on the board
SPARE31: CF6.2.31; also elsewhere on the board
SPARE32: CF6.2.32; also elsewhere on the board
VBUS: C10.1, CF6.2.23, CF6.2.24, CF6.2.25, CF6.2.26; also elsewhere on the board
~SD: CF6.2.39, CF6.2.40; also elsewhere on the board



Board: 4 copper layers, 82.5 x 99.0 mm, 44 parts (8 on the bottom side), 33 nets.

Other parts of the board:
@HOLE0, @HOLE1: (no value)

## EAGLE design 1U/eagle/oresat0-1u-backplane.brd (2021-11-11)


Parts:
C1, C2: 1n; .0603-C-NOSILK
C5: 10u 25V; 1206-B
CF1.2: SFM-120-X1-XXX-D
CM1.1, CM1.2, CM1.3: J-MOLEX-SMPM-73300-0111X
FIDUCIAL1, FIDUCIAL2, FIDUCIAL3: FIDUCIAL-1.0X2.0
R1, R2, R3, R4: 60.4; 1206-C
U$1: FLIGHMARKERNEW; FLIGHTMARKER_NEW_BOARDS

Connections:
!SD: CF1.2.39, CF1.2.40; also elsewhere on the board
C3-UART-RX: CF1.2.38; also elsewhere on the board
C3-UART-TX: CF1.2.37; also elsewhere on the board
CAN1_H: CF1.2.33, CF1.2.34, R1.1; also elsewhere on the board
CAN1_L: CF1.2.35, CF1.2.36, R2.1; also elsewhere on the board
CAN2_H: CF1.2.17, CF1.2.18, R3.1; also elsewhere on the board
CAN2_L: CF1.2.19, CF1.2.20, R4.1; also elsewhere on the board
GND: C1.2, C2.2, C5.2, CF1.2.27, CF1.2.28, CF1.2.29, CF1.2.30, CF1.2.LC1, CF1.2.LC2, CM1.1.P$1 (SHIELD1), CM1.1.P$2 (SHIELD1), CM1.1.P$3 (SHIELD1), CM1.1.P$4 (SHIELD1), CM1.2.P$1 (SHIELD1), CM1.2.P$2 (SHIELD1), CM1.2.P$3 (SHIELD1), CM1.2.P$4 (SHIELD1), CM1.3.P$1 (SHIELD1), CM1.3.P$2 (SHIELD1), CM1.3.P$3 (SHIELD1), CM1.3.P$4 (SHIELD1); also elsewhere on the board
L1-TURNSTILE: CM1.1.RF-DOWN (RF); also elsewhere on the board
L-TURNSTILE: CM1.2.RF-DOWN (RF); also elsewhere on the board
unnamed: C2.1, R3.2, R4.2
unnamed: C1.1, R1.2, R2.2
OPD_PWR: CF1.2.15, CF1.2.16; also elsewhere on the board
OPD_SCL: CF1.2.13, CF1.2.14; also elsewhere on the board
OPD_SDA: CF1.2.11, CF1.2.12; also elsewhere on the board
SPARE1-MAG-SDA: CF1.2.1, CF1.2.2; also elsewhere on the board
SPARE3-MAG-SCL: CF1.2.3; also elsewhere on the board
SPARE4-MAG-SCL: CF1.2.4; also elsewhere on the board
SPARE5-MAG-POWER: CF1.2.5; also elsewhere on the board
SPARE6-MAG-POWER: CF1.2.6; also elsewhere on the board
SPARE7: CF1.2.7; also elsewhere on the board
SPARE8: CF1.2.8; also elsewhere on the board
SPARE9-TURNSTILE-DEPLOY: CF1.2.9; also elsewhere on the board
SPARE10-TURNSTILE-DEPLOY: CF1.2.10; also elsewhere on the board
SPARE21: CF1.2.21; also elsewhere on the board
SPARE22: CF1.2.22; also elsewhere on the board
SPARE31: CF1.2.31; also elsewhere on the board
SPARE32: CF1.2.32; also elsewhere on the board
UHF-TURNSTILE: CM1.3.RF-DOWN (RF); also elsewhere on the board
VBUS: C5.1, CF1.2.23, CF1.2.24, CF1.2.25, CF1.2.26; also elsewhere on the board

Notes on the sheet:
v2.0
NOTE: See Slot 8 for CAN 1/2 information.
OreSat0 1U backplane v2.0


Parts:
C6: 10u 25V; 1206-B
CF2.2: SFM-120-X1-XXX-D
CM2.2, CM2.3: J-MOLEX-SMPM-73300-0111X

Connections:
!SD: CF2.2.39, CF2.2.40; also elsewhere on the board
C3-UART-RX: CF2.2.38; also elsewhere on the board
C3-UART-TX: CF2.2.37; also elsewhere on the board
CAN1_H: CF2.2.33, CF2.2.34; also elsewhere on the board
CAN1_L: CF2.2.35, CF2.2.36; also elsewhere on the board
CAN2_H: CF2.2.17, CF2.2.18; also elsewhere on the board
CAN2_L: CF2.2.19, CF2.2.20; also elsewhere on the board
GND: C6.2, CF2.2.27, CF2.2.28, CF2.2.29, CF2.2.30, CF2.2.LC1, CF2.2.LC2, CM2.2.P$1 (SHIELD1), CM2.2.P$2 (SHIELD1), CM2.2.P$3 (SHIELD1), CM2.2.P$4 (SHIELD1), CM2.3.P$1 (SHIELD1), CM2.3.P$2 (SHIELD1), CM2.3.P$3 (SHIELD1), CM2.3.P$4 (SHIELD1); also elsewhere on the board
L-TURNSTILE: CM2.2.RF-DOWN (RF); also elsewhere on the board
OPD_PWR: CF2.2.15, CF2.2.16; also elsewhere on the board
OPD_SCL: CF2.2.13, CF2.2.14; also elsewhere on the board
OPD_SDA: CF2.2.11, CF2.2.12; also elsewhere on the board
SPARE1-MAG-SDA: CF2.2.1, CF2.2.2; also elsewhere on the board
SPARE3-MAG-SCL: CF2.2.3; also elsewhere on the board
SPARE4-MAG-SCL: CF2.2.4; also elsewhere on the board
SPARE5-MAG-POWER: CF2.2.5; also elsewhere on the board
SPARE6-MAG-POWER: CF2.2.6; also elsewhere on the board
SPARE7: CF2.2.7; also elsewhere on the board
SPARE8: CF2.2.8; also elsewhere on the board
SPARE9-TURNSTILE-DEPLOY: CF2.2.9; also elsewhere on the board
SPARE10-TURNSTILE-DEPLOY: CF2.2.10; also elsewhere on the board
SPARE21: CF2.2.21; also elsewhere on the board
SPARE22: CF2.2.22; also elsewhere on the board
SPARE31: CF2.2.31; also elsewhere on the board
SPARE32: CF2.2.32; also elsewhere on the board
UHF-TURNSTILE: CM2.3.RF-DOWN (RF); also elsewhere on the board
VBUS: C6.1, CF2.2.23, CF2.2.24, CF2.2.25, CF2.2.26; also elsewhere on the board


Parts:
C7: 10u 25V; 1206-B
CF3.2: SFM-120-X1-XXX-D
CM3.2: J-MOLEX-SMPM-73300-0111X

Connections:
!SD: CF3.2.39, CF3.2.40; also elsewhere on the board
C3-UART-RX: CF3.2.38; also elsewhere on the board
C3-UART-TX: CF3.2.37; also elsewhere on the board
CAN1_H: CF3.2.33, CF3.2.34; also elsewhere on the board
CAN1_L: CF3.2.35, CF3.2.36; also elsewhere on the board
CAN2_H: CF3.2.17, CF3.2.18; also elsewhere on the board
CAN2_L: CF3.2.19, CF3.2.20; also elsewhere on the board
GND: C7.2, CF3.2.27, CF3.2.28, CF3.2.29, CF3.2.30, CF3.2.LC1, CF3.2.LC2, CM3.2.P$1 (SHIELD1), CM3.2.P$2 (SHIELD1), CM3.2.P$3 (SHIELD1), CM3.2.P$4 (SHIELD1); also elsewhere on the board
L1-TURNSTILE: CM3.2.RF-DOWN (RF); also elsewhere on the board
OPD_PWR: CF3.2.15, CF3.2.16; also elsewhere on the board
OPD_SCL: CF3.2.13, CF3.2.14; also elsewhere on the board
OPD_SDA: CF3.2.11, CF3.2.12; also elsewhere on the board
SPARE1-MAG-SDA: CF3.2.1, CF3.2.2; also elsewhere on the board
SPARE3-MAG-SCL: CF3.2.3; also elsewhere on the board
SPARE4-MAG-SCL: CF3.2.4; also elsewhere on the board
SPARE5-MAG-POWER: CF3.2.5; also elsewhere on the board
SPARE6-MAG-POWER: CF3.2.6; also elsewhere on the board
SPARE7: CF3.2.7; also elsewhere on the board
SPARE8: CF3.2.8; also elsewhere on the board
SPARE9-TURNSTILE-DEPLOY: CF3.2.9; also elsewhere on the board
SPARE10-TURNSTILE-DEPLOY: CF3.2.10; also elsewhere on the board
SPARE21: CF3.2.21; also elsewhere on the board
SPARE22: CF3.2.22; also elsewhere on the board
SPARE31: CF3.2.31; also elsewhere on the board
SPARE32: CF3.2.32; also elsewhere on the board
VBUS: C7.1, CF3.2.23, CF3.2.24, CF3.2.25, CF3.2.26; also elsewhere on the board


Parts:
C8: 10u 25V; 1206-B
CF4.2: SFM-120-X1-XXX-D
CM4.1: J-MOLEX-SMPM-73300-0111X

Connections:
!SD: CF4.2.39, CF4.2.40; also elsewhere on the board
C3-UART-RX: CF4.2.38; also elsewhere on the board
C3-UART-TX: CF4.2.37; also elsewhere on the board
CAN1_H: CF4.2.33, CF4.2.34; also elsewhere on the board
CAN1_L: CF4.2.35, CF4.2.36; also elsewhere on the board
CAN2_H: CF4.2.17, CF4.2.18; also elsewhere on the board
CAN2_L: CF4.2.19, CF4.2.20; also elsewhere on the board
GND: C8.2, CF4.2.27, CF4.2.28, CF4.2.29, CF4.2.30, CF4.2.LC1, CF4.2.LC2, CM4.1.P$1 (SHIELD1), CM4.1.P$2 (SHIELD1), CM4.1.P$3 (SHIELD1), CM4.1.P$4 (SHIELD1); also elsewhere on the board
OPD_PWR: CF4.2.15, CF4.2.16; also elsewhere on the board
OPD_SCL: CF4.2.13, CF4.2.14; also elsewhere on the board
OPD_SDA: CF4.2.11, CF4.2.12; also elsewhere on the board
S-PATCH: CM4.1.RF-DOWN (RF); also elsewhere on the board
SPARE1-MAG-SDA: CF4.2.1, CF4.2.2; also elsewhere on the board
SPARE3-MAG-SCL: CF4.2.3; also elsewhere on the board
SPARE4-MAG-SCL: CF4.2.4; also elsewhere on the board
SPARE5-MAG-POWER: CF4.2.5; also elsewhere on the board
SPARE6-MAG-POWER: CF4.2.6; also elsewhere on the board
SPARE7: CF4.2.7; also elsewhere on the board
SPARE8: CF4.2.8; also elsewhere on the board
SPARE9-TURNSTILE-DEPLOY: CF4.2.9; also elsewhere on the board
SPARE10-TURNSTILE-DEPLOY: CF4.2.10; also elsewhere on the board
SPARE21: CF4.2.21; also elsewhere on the board
SPARE22: CF4.2.22; also elsewhere on the board
SPARE31: CF4.2.31; also elsewhere on the board
SPARE32: CF4.2.32; also elsewhere on the board
VBUS: C8.1, CF4.2.23, CF4.2.24, CF4.2.25, CF4.2.26; also elsewhere on the board

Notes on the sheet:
NOTE: See Slot 8 for CAN 1/2 information.


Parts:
C9: 10u 25V; 1206-B
CF5.2: SFM-120-X1-XXX-D
J2: M55-6001642R; CONN_M55-6001642R_HRW

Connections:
!SD: CF5.2.39, CF5.2.40, J2.1; also elsewhere on the board
C3-UART-RX: CF5.2.38, J2.2; also elsewhere on the board
C3-UART-TX: CF5.2.37, J2.3; also elsewhere on the board
CAN1_H: CF5.2.33, CF5.2.34, J2.5; also elsewhere on the board
CAN1_L: CF5.2.35, CF5.2.36, J2.4; also elsewhere on the board
CAN2_H: CF5.2.17, CF5.2.18, J2.13; also elsewhere on the board
CAN2_L: CF5.2.19, CF5.2.20, J2.12; also elsewhere on the board
GND: C9.2, CF5.2.27, CF5.2.28, CF5.2.29, CF5.2.30, CF5.2.LC1, CF5.2.LC2, J2.6, J2.8, J2.10, J2.19 (17), J2.20 (17), J2.21 (17), J2.22 (17); also elsewhere on the board
OPD_PWR: CF5.2.15, CF5.2.16, J2.14; also elsewhere on the board
OPD_SCL: CF5.2.13, CF5.2.14, J2.15; also elsewhere on the board
OPD_SDA: CF5.2.11, CF5.2.12, J2.16; also elsewhere on the board
SPARE1-MAG-SDA: CF5.2.1, CF5.2.2; also elsewhere on the board
SPARE3-MAG-SCL: CF5.2.3; also elsewhere on the board
SPARE4-MAG-SCL: CF5.2.4; also elsewhere on the board
SPARE5-MAG-POWER: CF5.2.5; also elsewhere on the board
SPARE6-MAG-POWER: CF5.2.6; also elsewhere on the board
SPARE7: CF5.2.7; also elsewhere on the board
SPARE8: CF5.2.8; also elsewhere on the board
SPARE9-TURNSTILE-DEPLOY: CF5.2.9; also elsewhere on the board
SPARE10-TURNSTILE-DEPLOY: CF5.2.10; also elsewhere on the board
SPARE21: CF5.2.21; also elsewhere on the board
SPARE22: CF5.2.22; also elsewhere on the board
SPARE31: CF5.2.31; also elsewhere on the board
SPARE32: CF5.2.32; also elsewhere on the board
VBUS: C9.1, CF5.2.23, CF5.2.24, CF5.2.25, CF5.2.26, J2.7, J2.9, J2.11; also elsewhere on the board

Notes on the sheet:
DEBUG CONNECTOR


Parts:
C10: 10u 25V; 1206-B
CF6.2: SFM-120-X1-XXX-D

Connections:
!SD: CF6.2.39, CF6.2.40; also elsewhere on the board
C3-UART-RX: CF6.2.38; also elsewhere on the board
C3-UART-TX: CF6.2.37; also elsewhere on the board
CAN1_H: CF6.2.33, CF6.2.34; also elsewhere on the board
CAN1_L: CF6.2.35, CF6.2.36; also elsewhere on the board
CAN2_H: CF6.2.17, CF6.2.18; also elsewhere on the board
CAN2_L: CF6.2.19, CF6.2.20; also elsewhere on the board
GND: C10.2, CF6.2.27, CF6.2.28, CF6.2.29, CF6.2.30, CF6.2.LC1, CF6.2.LC2; also elsewhere on the board
OPD_PWR: CF6.2.15, CF6.2.16; also elsewhere on the board
OPD_SCL: CF6.2.13, CF6.2.14; also elsewhere on the board
OPD_SDA: CF6.2.11, CF6.2.12; also elsewhere on the board
SPARE1-MAG-SDA: CF6.2.1, CF6.2.2; also elsewhere on the board
SPARE3-MAG-SCL: CF6.2.3; also elsewhere on the board
SPARE4-MAG-SCL: CF6.2.4; also elsewhere on the board
SPARE5-MAG-POWER: CF6.2.5; also elsewhere on the board
SPARE6-MAG-POWER: CF6.2.6; also elsewhere on the board
SPARE7: CF6.2.7; also elsewhere on the board
SPARE8: CF6.2.8; also elsewhere on the board
SPARE9-TURNSTILE-DEPLOY: CF6.2.9; also elsewhere on the board
SPARE10-TURNSTILE-DEPLOY: CF6.2.10; also elsewhere on the board
SPARE21: CF6.2.21; also elsewhere on the board
SPARE22: CF6.2.22; also elsewhere on the board
SPARE31: CF6.2.31; also elsewhere on the board
SPARE32: CF6.2.32; also elsewhere on the board
VBUS: C10.1, CF6.2.23, CF6.2.24, CF6.2.25, CF6.2.26; also elsewhere on the board


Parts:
C11: 10u 25V; 1206-B
CF7.2: SFM-120-X1-XXX-D

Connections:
!SD: CF7.2.39, CF7.2.40; also elsewhere on the board
C3-UART-RX: CF7.2.38; also elsewhere on the board
C3-UART-TX: CF7.2.37; also elsewhere on the board
CAN1_H: CF7.2.33, CF7.2.34; also elsewhere on the board
CAN1_L: CF7.2.35, CF7.2.36; also elsewhere on the board
CAN2_H: CF7.2.17, CF7.2.18; also elsewhere on the board
CAN2_L: CF7.2.19, CF7.2.20; also elsewhere on the board
GND: C11.2, CF7.2.27, CF7.2.28, CF7.2.29, CF7.2.30, CF7.2.LC1, CF7.2.LC2; also elsewhere on the board
OPD_PWR: CF7.2.15, CF7.2.16; also elsewhere on the board
OPD_SCL: CF7.2.13, CF7.2.14; also elsewhere on the board
OPD_SDA: CF7.2.11, CF7.2.12; also elsewhere on the board
SPARE1-MAG-SDA: CF7.2.1, CF7.2.2; also elsewhere on the board
SPARE3-MAG-SCL: CF7.2.3; also elsewhere on the board
SPARE4-MAG-SCL: CF7.2.4; also elsewhere on the board
SPARE5-MAG-POWER: CF7.2.5; also elsewhere on the board
SPARE6-MAG-POWER: CF7.2.6; also elsewhere on the board
SPARE7: CF7.2.7; also elsewhere on the board
SPARE8: CF7.2.8; also elsewhere on the board
SPARE9-TURNSTILE-DEPLOY: CF7.2.9; also elsewhere on the board
SPARE10-TURNSTILE-DEPLOY: CF7.2.10; also elsewhere on the board
SPARE21: CF7.2.21; also elsewhere on the board
SPARE22: CF7.2.22; also elsewhere on the board
SPARE31: CF7.2.31; also elsewhere on the board
SPARE32: CF7.2.32; also elsewhere on the board
VBUS: C11.1, CF7.2.23, CF7.2.24, CF7.2.25, CF7.2.26; also elsewhere on the board


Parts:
C3, C4: 1n; .0603-C-NOSILK
R5, R6, R7, R8: NP/60.4; 1206-C
R9, R10: 0; .0603-B-NOSILK

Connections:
CAN1_H: R5.1, R10.1; also elsewhere on the board
CAN1_L: R6.1, R9.1; also elsewhere on the board
CAN2_H: R7.1, R10.2; also elsewhere on the board
CAN2_L: R8.1, R9.2; also elsewhere on the board
GND: C3.2, C4.2; also elsewhere on the board
unnamed: C4.1, R7.2, R8.2
unnamed: C3.1, R5.2, R6.2

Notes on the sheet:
NP: CAN 1/2 independent 0 Ohm: CAN 1 = 2 (remove 60 ohms)

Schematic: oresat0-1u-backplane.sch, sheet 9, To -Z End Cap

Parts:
CM8: U.FL-R-SMA; U.FL-R-SMT
J1: 5-104196-5

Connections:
GND: CM8.2, CM8.3, J1.HD1 (HD), J1.HD2 (HD), J1.HD3 (HD); also elsewhere on the board
S-PATCH: CM8.1; also elsewhere on the board
SPARE1-MAG-SDA: J1.19, J1.20; also elsewhere on the board
SPARE3-MAG-SCL: J1.18; also elsewhere on the board
SPARE4-MAG-SCL: J1.17; also elsewhere on the board
SPARE5-MAG-POWER: J1.16; also elsewhere on the board
SPARE6-MAG-POWER: J1.15; also elsewhere on the board
SPARE7: J1.14; also elsewhere on the board
SPARE8: J1.13; also elsewhere on the board
SPARE9-TURNSTILE-DEPLOY: J1.12; also elsewhere on the board
SPARE10-TURNSTILE-DEPLOY: J1.11; also elsewhere on the board

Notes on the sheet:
-Z End Cap Connector



Board: 4 copper layers, 82.5 x 99.0 mm, 42 parts (8 on the bottom side), 33 nets.

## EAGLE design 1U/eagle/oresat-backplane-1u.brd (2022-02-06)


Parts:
C1, C2: 1n; .0603-C-NOSILK
C5: C-EU1206-B; 1206-B
CF1.2: SFM-120-X1-XXX-D
CM1.1, CM1.2, CM1.3: J-MOLEX-SMPM-73300-0111X
FIDUCIAL1, FIDUCIAL2, FIDUCIAL3: FIDUCIAL-1.0X2.0
R1, R2, R3, R4: 60.4; 1206-C
U$1: FLIGHMARKERNEW; FLIGHTMARKER_NEW_BOARDS

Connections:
!SD: CF1.2.39, CF1.2.40; also elsewhere on the board
CAN1_H: CF1.2.33, CF1.2.34, R1.1; also elsewhere on the board
CAN1_L: CF1.2.35, CF1.2.36, R2.1; also elsewhere on the board
CAN2_H: CF1.2.17, CF1.2.18, R3.1; also elsewhere on the board
CAN2_L: CF1.2.19, CF1.2.20, R4.1; also elsewhere on the board
GND: C1.2, C2.2, C5.2, CF1.2.27, CF1.2.28, CF1.2.29, CF1.2.30, CF1.2.LC1, CF1.2.LC2, CM1.1.P$1 (SHIELD1), CM1.1.P$2 (SHIELD1), CM1.1.P$3 (SHIELD1), CM1.1.P$4 (SHIELD1), CM1.2.P$1 (SHIELD1), CM1.2.P$2 (SHIELD1), CM1.2.P$3 (SHIELD1), CM1.2.P$4 (SHIELD1), CM1.3.P$1 (SHIELD1), CM1.3.P$2 (SHIELD1), CM1.3.P$3 (SHIELD1), CM1.3.P$4 (SHIELD1); also elsewhere on the board
L1-TURNSTILE: CM1.1.RF-DOWN (RF); also elsewhere on the board
L-TURNSTILE: CM1.2.RF-DOWN (RF); also elsewhere on the board
unnamed: C2.1, R3.2, R4.2
unnamed: C1.1, R1.2, R2.2
OPD_PWR: CF1.2.15, CF1.2.16; also elsewhere on the board
OPD_SCL: CF1.2.13, CF1.2.14; also elsewhere on the board
OPD_SDA: CF1.2.11, CF1.2.12; also elsewhere on the board
SPARE1: CF1.2.1, CF1.2.2; also elsewhere on the board
SPARE3: CF1.2.3; also elsewhere on the board
SPARE4: CF1.2.4; also elsewhere on the board
SPARE5: CF1.2.5; also elsewhere on the board
SPARE6: CF1.2.6; also elsewhere on the board
SPARE7: CF1.2.7; also elsewhere on the board
SPARE8: CF1.2.8; also elsewhere on the board
SPARE9: CF1.2.9; also elsewhere on the board
SPARE10: CF1.2.10; also elsewhere on the board
SPARE21: CF1.2.21; also elsewhere on the board
SPARE22: CF1.2.22; also elsewhere on the board
SPARE31: CF1.2.31; also elsewhere on the board
SPARE32: CF1.2.32; also elsewhere on the board
UART-RX: CF1.2.38; also elsewhere on the board
UART-TX: CF1.2.37; also elsewhere on the board
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

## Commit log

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2016-03-26 Updated backplane to latest connectors - 1.27 mm 2x20 and new MCX connectors. Also added keep outs from Jeremy.
    [oresat-backplane-for-0.3.brd, oresat-backplane-for-0.3.sch]
2016-03-26 Updated to TE MCX M verticals to save precious, precious mm on the cards
    [oresat-backplane-for-0.3.brd, oresat-backplane-for-0.3.sch]
2018-08-19 Latest backplane, with SamTec TigerEye SFM-1x0 connectors, and with MMCX to UT-047 RF connectors.
    [oresat-backplane-for-0.3.brd, oresat-backplane-for-0.3.sch, oresat-backplane.brd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]
2018-08-19 Beginnings of the 20 slots, with connectors! Almost Joe Approved, waiting for better DXF.
    [oresat-backplane.brd, oresat-backplane.sch]
2018-08-20 OMG we have a backplane. Note that the MMCX connectors are probably incorrectly placed because we're going to switch to some different connector that's more SMT-y for Oliver because he's an RF racist.
    [oresat-backplane.brd, oresat-backplane.sch]
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2018-09-17 Updated center fasteners with new precision shoulder bolt diameter and spring-like arm.
    [oresat-backplane-breakout.brd, oresat-backplane-breakout.sch]
2018-10-02 Version 1.0 of backplane. With SMPM connectors, with the correct BSTOP layer for thermal connection to the -X frame, and with separate pins on the backplane connectors for future flexibility in this 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
    [oresat-backplane.brd, oresat-backplane.sch]
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2018-12-03 Updated TFM connectors with smaller holes and bigger pads based on the v1.0 backplane. Now it's V1.1!
    [oresat-backplane.brd, oresat-backplane.sch]
2019-01-15 Backplane v1.1. Main connectors to all cards including end cards, Aux connector to all cards but the end card, signals named, etc.
    [oresat-backplane-breakout.brd, oresat-backplane-breakout.sch, oresat-backplane.brd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]
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2019-02-22 Fixed wrong signal names, removed thermals from bottom of main connectors, should be ready for fab.
    [oresat-backplane.brd, oresat-backplane.sch]
2019-05-26 Backplane v3. All good, except for the polygon error that keeps killing EAGLE. I thought this was fixed? Also, the RF stuff is all terrible until Vigely fixgures out what we should do :)
    [oresat-backplane.brd, oresat-backplane.sch]
2019-06-20 Updated connector locations from MCAD. Last of the separate RF grounds before reverting back to single ground plane.
    [oresat-backplane.brd]
2019-06-29 Backplane v2.0! New dimensions and connector placement for Frame v1.1. New bespoke RF lines for the current OreSat RF card and antenna plan. After design review, added one more pin pair to vbus and g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
    [oresat-backplane.brd, oresat-backplane.sch]
2019-06-29 Updated microstrips to 0.38 mm based on theoretical calcs of 0.35 mm for the OSH Park 4 layer, and Harmon Industry's measurements of 0.41 mm for 50 ohms. Also expanded solder mask openings around RF 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
    [oresat-backplane.brd, oresat-backplane.sch]
2019-07-01 Last polish before fab. Removed copper and solder mask from the fasteners that don't make electrical contact, so they can be cycled without flaking and other damage.
    [oresat-backplane.brd]
2019-07-24 Updated to latest backplane DXF. Reduced all sides by 0.15 mm. Fixed solar connector cutout areas that were lopsided. Awaiting RF testing.
    [oresat-backplane.brd]
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2020-02-16 More additions to v2.1: split termination on the CAN busses, locked everything down, and moved the RF connectors to where they're currently supposed to be.
    [oresat-backplane.brd, oresat-backplane.sch]
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2020-07-13 Widended shoulder bolt screw down area to cover the entire bolt. Shouldn't affect anything.
    [oresat-backplane-2u.brd]
2020-07-13 Uh, whoops, should have committed these at the same time. First draft of the 1U backplane. Passes ERC and DRC.
    [oresat-backplane-1u.sch]
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2020-11-17 Updated 1U backplane to v1.2. Better position of end cap connector, added debug connector.
    [oresat-backplane-1u.brd, oresat-backplane-1u.sch]
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2020-12-08 Updated with corrected debug connector. Footprint didn't change, so no change to version.
    [oresat-backplane-1u.brd, oresat-backplane-1u.sch]
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2021-03-22 Version 1.3. No significant difference with v1.2 besides added TPLACE block, updated not for flight marker, and fiducials just in case.
    [oresat-backplane-1u.brd, oresat-backplane-1u.sch]
2021-03-22 v1.1 debug port breakout. v1.0 wasn't deep enough so it hit the solar panel.
    [debug-port-breakout.brd]
2021-03-22 v1.1 of the debug port plug. Perhaps it's not a great to short out literally every pin on the bus to ground? Maybe?
    [debug-port-plug.brd, debug-port-plug.sch]
2021-10-03 Backplane v2.0. Changes to signals; vaguely back compatible with v1. Also spun off OreSat0 bespoke backplane for the OreSat0 mission.
    [oresat0-backplane.brd, oresat0-backplane.sch]
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2021-11-11 Updated spare lines in schematic to reflect magnetometer usage; no change to board.
    [oresat0-1u-backplane.brd, oresat0-1u-backplane.sch]
2021-11-25 Fixed OreSat0.1 BOM - debug connector was wrong. Also added PCB cost.
    [oresat0-backplane-bom.xlsx]
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2022-02-06 Half-done changes to the 2U (needs fixing, but in KiCAD).
    [oresat-backplane-2u.brd, oresat-backplane-2u.sch]
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2022-07-07 Moved the correct 2u backplane to KiCad this time
    [Slot_1.kicad_sch, Slot_10.kicad_sch, Slot_11.kicad_sch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]
2022-07-13 RF traces are fixed, hopefully correctly
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2022-07-18 Fixed DRC errors and warnings
    [Slot_1.kicad_sch, Slot_2.kicad_sch, Slot_3.kicad_sch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]
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2022-07-27 Fixed RF traces and connectors, and DRC
    [Slot_1.kicad_sch, Slot_10.kicad_sch, Slot_11.kicad_sch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]
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2023-02-19 Fixed all (most) of the issues from Eagle imports
    [Slot_1.kicad_sch, Slot_12.kicad_sch, Slot_13.kicad_sch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]
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2023-02-20 Fixed backplane connector library names
    [oresat-backplane-2u.kicad_sch]
2023-02-20 Fixed silkscreen on copper
2023-02-20 Updated 2U DXF to something more useful, and rename Ben's naming faux pas.
    [2U Backplane - 2U Backplane.dxf, 2u-backplane.dxf, oresat-backplane-2u.kicad_sch]
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2023-03-28 Moved aux connectors, fixed RF connector soldermask
    [oresat-backplane-2u.kicad_sch]
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2023-04-25 Polished v1.1 of the OreSat0.5 backplane: fixed schematic off grid issues and updated symbols, removed copper spikes, updated date, ignored ignorable DRC errors.
    [oresat-backplane-2u.kicad_sch]
2025-09-29 New OreSat1 2U backplane. Switched to the correct backplane design (OreSat0.5 was incorrect) and broke up into multiple sheets. Set actual part numbers for BOM, added symbols for fastener holes. Stil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
    [oresat-backplane-2u-sch-auxilliary.kicad_sch, oresat-backplane-2u-sch-debug.kicad_sch, oresat-backplane-2u-sch-main-1.kicad_sch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]
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2025-10-09 Update of OreSat1 2U backplane. Removed extraneous connectors, imported DXF from OnShape and moved debug connectors by 0.176 mm. Routing left to do.
    [oresat-backplane-2u-sch-auxilliary.kicad_sch, oresat-backplane-2u-sch-debug.kicad_sch, oresat-backplane-2u-sch-main-1.kicad_sch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]
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2025-10-22 Added latest DXF drawing from the structure team, updated the stackup with OreSat standards, updated the page sizes, etc.
    [3U backplane.kicad_pcb, 3U backplane.kicad_sch, oresat-backplane-3u.kicad_pcb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]
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2025-10-22 Fixed libraries and footprints, synced sch and pcb (sorry Jacob).
    [oresat-backplane-3u-sch-debug.kicad_sch, oresat-backplane-3u-sch-main-1.kicad_sch, oresat-backplane-3u-sch-main-2.kicad_sch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]
2025-10-22 Fix library issues on aux footprints.
    [oresat-backplane-2u-sch-auxilliary.kicad_sch, oresat-backplane-2u.kicad_pcb]
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2025-12-01 Final fix and polish on 2U backplane for OreSat1.
    Found a bunch of small little details to fix - somehow CAN lines were down to 0.2 mm, fixed to 0.3 mm. Also expanded some of
    the lines to 0.6 mm for higher power lines. Added more vias for VBUS on the debug connector, and finally added 3D models
    to all of the connectors so the backplane fully renders now!
    [oresat-backplane-2u-sch-auxilliary.kicad_sch, oresat-backplane-2u-sch-debug.kicad_sch, oresat-backplane-2u-sch-main-1.kicad_sch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]
2025-12-02 Fixed DRC errors
    [oresat-backplane-2u.kicad_pcb]
2025-12-02 Moved can lines to back & fixed RF schematic organization
    [oresat-backplane-3u-sch-aux.kicad_sch, oresat-backplane-3u-sch-rf1.kicad_sch, oresat-backplane-3u-sch-rf2.kicad_sch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]
2025-12-04 Can lines on back - need to move can resistors to front & add b.side solder mask
    [oresat-backplane-3u-sch-debug.kicad_sch, oresat-backplane-3u-sch-main-1.kicad_sch, oresat-backplane-3u-sch-main-2.kicad_sch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]
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2025-12-29 OreSat1 backplane v1.0 commit
    Final cleanup. moved should bolt holes from to drilled holes, not routed holes. Updated date on schematic and board. Sending out for fab.
    [oresat-backplane-2u-sch-auxilliary.kicad_sch, oresat-backplane-2u-sch-debug.kicad_sch, oresat-backplane-2u-sch-main-1.kicad_sch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]
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2026-02-21 Added schematic and board variables, polished some silkscreen, reviewed board, renamed directory
    [oresat-backplane-3u-ESI.kicad_pcb, oresat-backplane-3u-ESI.kicad_sch, oresat-backplane-3u-sch-aux.kicad_sch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]
2026-02-21 Added fastener solder mask cutouts and copper keep out zones for all fasteners.
    [oresat-backplane-3u-ESI.kicad_pcb]
2026-02-21 Updated generic 3U backplane with correct fastener copper and solder mask cutouts under fastners, and updated date on sch and brd.
    [oresat-backplane-3u-sch-aux.kicad_sch, oresat-backplane-3u-sch-debug.kicad_sch, oresat-backplane-3u-sch-main-1.kicad_sch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]
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2026-02-22 fixed erc and drc errors
    [oresat-backplane-3u-ESI.kicad_pcb, oresat-backplane-3u-sch-rf3.kicad_sch]
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2026-02-22 Polish of 3U for ESI
    Fixed ERC/DRC/sync errors. Made fancy RF table. Fixed BOM.
    [oresat-backplane-3u-ESI.kicad_pcb, oresat-backplane-3u-ESI.kicad_sch, oresat-backplane-3u-sch-debug.kicad_sch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]
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2026-02-22 OreSat1 backplane v1.1
    Lots of little changes; technically there should be no actual changes betwen v1.0 and v1.1 but
    the BOM is correct, the masks are done better, the precision shoulder bolts are drills not
    routed, and it's just cleaned up a lot.
    [oresat-backplane-2u-sch-auxilliary.kicad_sch, oresat-backplane-2u-sch-debug.kicad_sch, oresat-backplane-2u-sch-main-1.kicad_sch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]
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2026-03-05 Changed schematic & pcb to add spare traces, no helical or turnstile
    [backplane-3u-ESI.kicad_pcb, oresat-backplane-3u-sch-main-1.kicad_sch, oresat-backplane-3u-sch-main-2.kicad_sch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]
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2026-03-09 Small fix for CAD directory
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2026-03-09 footprint weirdness fixed
    [esi-backplane-3u-sch-debug.kicad_sch, esi-backplane-3u-sch-main-1.kicad_sch, esi-backplane-3u-sch-main-2.kicad_sch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]
2026-03-09 fixed resistor footprint issues?
    [esi-backplane-3u.kicad_pcb]
2026-03-12 Fixed minor BOM issue with a repeated connector.
    [esi-backplane-3u-sch-main-1.kicad_sch, esi-backplane-3u-sch-rf.kicad_sch]
2026-03-12 Minor BOM fix on 2U
    [oresat-backplane-2u-sch-auxilliary.kicad_sch, oresat-backplane-2u.kicad_pcb]
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2026-04-08 Fix and update SMPM connectors, now they're sane for KiCad. Also, move to DRU-based ground plane peelback to avoid DRC errors, and improve fmask layer. Also lock a bunch of stuff that ought to be loc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
    [esi-backplane-3u-sch-rf.kicad_sch, esi-backplane-3u.kicad_pcb]
2026-04-08 minor f mask fix around SMPMs
    [esi-backplane-3u.kicad_pcb]
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2026-04-26 Connected Spares and switched OPD to inner layer. Updated RF cons -- **RF con new footprint has ground pad schematic parity error
    [oresat-backplane-3u-sch-aux.kicad_sch, oresat-backplane-3u-sch-debug.kicad_sch, oresat-backplane-3u-sch-main-1.kicad_sch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]
2026-04-26 Updated schematic symbol for RF con. Believe this is done. Remaining DRC errors are only unconnected RF cons -- fine until use defined for non-generic version.
    [oresat-backplane-3u-sch-rf1.kicad_sch, oresat-backplane-3u-sch-rf2.kicad_sch, oresat-backplane-3u-sch-rf3.kicad_sch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]
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2026-09-01 Oresat1 2U Backplane v1.1
    Big review of all issues, added better custom DRUs and updated README and Makefile. Added fiducials. Created
    release folder, I think this makes sense.
    [oresat-backplane-2u-sch-auxilliary.kicad_sch, oresat-backplane-2u-sch-debug.kicad_sch, oresat-backplane-2u-sch-main-1.kicad_sch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]

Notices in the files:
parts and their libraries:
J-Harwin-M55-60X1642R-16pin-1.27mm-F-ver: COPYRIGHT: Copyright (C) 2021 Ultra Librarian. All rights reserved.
